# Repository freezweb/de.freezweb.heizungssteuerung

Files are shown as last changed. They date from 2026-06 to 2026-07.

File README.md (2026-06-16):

# de.freezweb.heizungssteuerung

Heizungssteuerung auf Revolution Pi Connect 4 mit Anbindung an Home Assistant (MQTT).

Komplette Spezifikation: siehe [LASTENHEFT.md](LASTENHEFT.md).

## Komponenten
- **Hauptsteuerung** Heizungsraum (RevPi #1, `10.1.25.10`)
- **Slave-Steuerung** Hauptkeller (RevPi #2, `10.1.25.11`, sp&auml;ter)
- **Visualisierung + History**: Home Assistant via MQTT-Discovery
- **Failsafe**: Witterungsgef&uuml;hrte Heizkurve bei MQTT-/HA-Ausfall

## Stack
- Python 3.11 (Asyncio)
- `revpimodio2` &mdash; RevPi-I/O
- `paho-mqtt` &mdash; HA-Kopplung
- `pymodbus` &mdash; W&auml;rmepumpen, Klima-Innenger&auml;te, Slave-CPU
- systemd (`Type=simple, Restart=on-failure`)

## Verzeichnisstruktur
```
src/heizung/        Hauptcode
config/             Live-Configs (gitignored, *.example committet)
pictory/            RevPi-PiCtory-Export
tests/              Pytest
deploy/             systemd-Unit + install/update Scripts
docs/               Hydraulik-, I/O- und MQTT-Doku
```

Wichtige Hardware-Planung:
- [docs/revpi-modulplanung.md](docs/revpi-modulplanung.md)
- [docs/io-belegung.md](docs/io-belegung.md)

## Quick start (Entwicklung)
```bash
python -m venv .venv
.venv\Scripts\activate
pip install -e .
cp config/settings.yaml.example config/settings.yaml
# Anpassen, dann:
python -m heizung
```

## Deployment auf RevPi
Siehe `deploy/install.sh`.

## Phasen-Plan
Siehe [LASTENHEFT.md Abschnitt 10](LASTENHEFT.md#10-phasen-plan-reihenfolge).

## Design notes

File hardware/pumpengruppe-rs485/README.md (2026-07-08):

# Pumpengruppe RS485 KiCad-Projekt

RevA preliminary, Stand 2026-06-25.

Dieses Verzeichnis enthaelt den KiCad-Startentwurf fuer die dezentrale
Pumpengruppen-Platine:

- `pumpengruppe-rs485.kicad_pro`: KiCad-Projekt
- `pumpengruppe-rs485.kicad_sch`: Schaltplan mit lokalen Symbolen
- `pumpengruppe-rs485.kicad_pcb`: PCB-Grundlayout 160 x 110 mm
- `lib/`: lokale Symbole/Footprints
- `export-fab.ps1`: Gerber/Drill/BOM-Export per `kicad-cli`
- `fab/`: Zielordner fuer Fertigungsdaten

Aktueller Stand:

- Schaltplan/PCB laden in KiCad 10.0.4.
- Schaltplan enthaelt jetzt alle im PCB platzierten Hauptbauteile inklusive
  `F1`, `U5`, USB-C/USB-UART und schaltbarem RS485-Abschluss. Die lokalen
  Symbole haben benannte Pins; die Netznamen sind als sichtbare Texte an den
  Funktionspins gesetzt.
- Gerber/Drill/BOM lassen sich per `export-fab.ps1` erzeugen.
- USB-C-Serviceanschluss mit USB-UART-Funktion ist eingeplant.
- UART-Topologie im Schaltplan ist getrennt:
  `U6` USB-UART liegt nur auf ESP-UART0 (`ESP_U0RX`/`ESP_U0TX`) fuer
  Firmware/Debug. `U4` MAX3485 liegt separat auf dem RS485-UART
  (`RS485_UART_RX` = ESP GPIO16, `RS485_UART_TX` = ESP GPIO17,
  `RS485_DE` = ESP GPIO4). Nach dieser Korrektur muss die PCB-Datei in KiCad
  aus dem Schaltplan aktualisiert und das Routing fuer diese Netze neu gezogen
  werden; alte `UART_RX`/`UART_TX`-Routen im PCB duerfen nicht als
  Fertigungsstand gelten.
- ESP32 ist als WROOM-32D mit PCB-Antenne vorgesehen; Antennenseite am
  Platinenrand platzieren und Keepout freihalten.
- Relais werden nicht direkt vom ESP geschaltet: pro Relais sind 100R
  Gatewiderstand, 100k Pulldown, AO3400A-kompatibler NMOS, SS14-Freilaufdiode
  und Status-LED vorgesehen.
- Mischer ist als Hardware-Interlock geplant: `K2` schaltet nur die
  Mischerfreigabe, `K3` ist ein SPDT-Umschaltrelais fuer die Richtung
  `NC=ZU` / `NO=AUF`. Damit koennen AUF und ZU elektrisch nicht gleichzeitig
  gespeist werden.
- Kontrollanzeigen: 230 V diskret auf der Netzseite mit `R40/R41/D40/D41`,
  5 V, 3V3 sowie RS485 TX/RX und die drei Relaisansteuerungen.
- Adressierbare RGB-Anzeige: `D60-D83` sind einheitliche SK6812MINI/3535-5-V-RGB-LEDs
  an `RGB_DATA`/ESP32 GPIO21. `D60-D63` bleiben allgemeine Status-LEDs,
  `D64-D83` bilden den senkrechten Ventilstand-Balken mit 5-%-Schritten;
  die 20er-Leiste ist im 4,8-mm-Raster gesetzt, damit Courtyards nicht kollidieren.
- RTD/ESP-Hinweis: Die beiden MAX31865 haben getrennte Chip-Select-Leitungen
  (`RTD_VL_CS` = GPIO5, `RTD_RL_CS` = GPIO22). Der ESP32-EN-Pin ist ueber
  `R33` als 10-kOhm-Pullup an `+3V3` angebunden.
- Netzteil ist auf ein guenstiges KiCad-Standardfootprint fuer
  `HLK-5M05`/`HLK-5Mxx` umgestellt.
- RS485 ist auf eine guenstige Standardtransceiver-Schaltung umgestellt:
  `U4` = MAX3485/SP3485-Klasse im SOIC-8 mit getrennten UART-Netzen zum ESP,
  `RS485_DE` vom ESP fuer DE/RE.
- Ueberspannungsschutz auf der Netzseite ist diskret vorgesehen:
  `RV1` als 275-VAC-MOV zwischen L und N.
- RJ45 Pin 1/2 fuehren `BUS_5V`, Pin 7/8 `COM`; `F2` schuetzt die 5V-Kopplung
  mit PTC, `R32` koppelt COM auf lokale 0V fuer RJ45-Power-Sharing.
- Es gibt zwei Bestueckungsvarianten fuer dieselbe Leiterplatte:
  - Vollausbau Pumpengruppe: `pumpengruppe-rs485-bom.csv` und
    `pumpengruppe-rs485-pick-place.csv`.
  - Temperatur-/RS485-Variante: `pumpengruppe-rs485-bom-tempinput.csv` und
    `pumpengruppe-rs485-pick-place-tempinput.csv`; dabei bleibt der linke
    230-V-/Relaisbereich unbestueckt und die Versorgung erfolgt ueber
    `BUS_5V`/RJ45.
- Die Breakaway-Variante ist im Board sichtbar umgesetzt: `MB1` setzt
  0,7-mm-NPTH-Mousebites in die oberen und unteren Materialstege des
  vorhandenen Isolationsschlitzes. Zusaetzlich bleibt die
  `Dwgs.User`-/Silkscreen-Markierung fuer die Bestueckungsvariante erhalten.
- Netzteil und Relais sind so platziert, dass die Bauteile den
  MAINS/SELV-Spalt ueberbruecken: Netz-/Kontaktpins links, SELV-/Spulenpins
  rechts.
- RS485-Abschluss ist schaltbar: `R3 = 120R` in Serie mit `JP1`. `JP1` ist
  ein 1x3-Header, damit der Jumper am Geraet bleiben kann:
  `1-2 = Abschluss aktiv`, `2-3 = Parkposition/Aus`.
- RJ45-Buchsen und USB-C-Serviceport sind an die Unterkante gesetzt und zeigen
  zur Kante, damit Stecker/Kabel nutzbar sind. RS485-Schraubklemmen bleiben an
  der rechten Anschlusskante. J3/J4 sind auf dem Silkscreen mit A/B/GND
  beschriftet; am unteren Rand steht das RJ45-Pinout
  `1/2=5V 3/6=NC 4=A 5=B 7/8=GND`.
- KiCad-Netclasses sind in `pumpengruppe-rs485.kicad_pro` gesetzt:
  `230V` routet L/N/geschaltete 230-V-Lastnetze und PE mit 1,5 mm und
  0,8 mm Clearance innerhalb der 230-V-Netze. Fuer die 5-A-Sicherung sollte die
  Bestellung mit mindestens 70 um / 2 oz Kupfer angefragt werden oder die
  tatsaechliche Last/Sicherung entsprechend reduziert werden. Die 8-mm-Trennung
  zwischen 230 V und SELV bleibt als physische Keepout-/Fraesnut-Regel beim
  Layout zwingend einzuhalten.
- Die Netclasses fuer weitere Power-Routings sind gesetzt:
  `SELV_POWER_0V8` fuer `+5V`, `BUS_5V`, `USB_VBUS`, `GND` und `RS485_GND`;
  `Doppelte Dicke` mit 0,4 mm fuer `+3V3`. Auf der RGB-/Temp-Input-Seite sind
  erste vorhandene 5-V-/GND-Segmente real auf 0,8 mm und 3V3-Segmente auf
  0,4 mm verbreitert. Einige Engstellen an USB/RJ45 bleiben bewusst 0,2 mm,
  weil breitere Leiterbahnen dort DRC-Kurzschluesse erzeugen wuerden. Fuer die
  finale Serienplatine sollten diese Netze weiter gezielt als breite
  Versorgungsstaemme bzw. Kupferflaechen nachgezogen werden.

Wichtig: RevA ist elektrisch geroutet und hat keine offenen Netze im KiCad-DRC.
Vor einer Netzspannungs-Freigabe bleiben trotzdem Relais-/Sicherungsrating,
PE-Fuehrung, Gehaeuseintegration, Beruehrschutz, EMV-Schutz und die
Herstellerfreigabe fuer 230-V-Abstaende zu pruefen. Wenn die RJ45-5V-Weitergabe
bestueckt/genutzt wird, ist die RS485-/SELV-Masse gemeinsam; das
Isolationskonzept muss dann als gemeinsamer SELV-Bus bewertet werden.

## Export

Nach Installation von KiCad:

```powershell
cd hardware\pumpengruppe-rs485
.\export-fab.ps1
```

Das Skript erzeugt Gerber, Excellon-Drill, beide BOM-Varianten, beide
Pick-and-Place/XY-Dateien und eine ZIP-Datei in `fab/`.

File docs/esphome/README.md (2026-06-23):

# ESPHome Wasserverbrauch Pumpe

`wasserverbrauch-pumpe.yaml` ist der aktuell bekannte Stand des ESP32 am
Flowmeter der Brunnenpumpe.

## Ziel fuer die Brunnenregelung

Die ESPHome-Konfig stellt den Momentandurchfluss als lokalen Modbus-TCP-Server
per WLAN bereit.

| Register | Typ | Inhalt | Skalierung |
|---|---|---|---|
| 0 | Input Register | Wasserdurchfluss | L/min * 100 |
| 1/2 | Input Register | Wasserverbrauch Gesamt | L * 1000 |

Beispiel: Registerwert `125` bedeutet `1.25 L/min`.

## Modbus TCP

- TCP-Port: `502`
- Unit-ID: `1`
- Function 3 und 4 werden beantwortet
- Register 0: Durchfluss `L/min * 100`
- Register 1/2: Gesamtverbrauch `L * 1000`

## Anbindung an die Hauptsteuerung

ESPHome bringt `async_tcp` als TCP-Grundlage mit, aber keinen fertigen
Modbus-TCP-Server fuer diesen Flowmeter-Fall. Deshalb startet die YAML in
`on_boot` einen kleinen AsyncTCP-Server direkt aus einem Lambda. Es wird keine
zweite Datei und keine External Component benoetigt.

Die Hauptsteuerung liest:

- Host: `wasserverbrauch-pumpe.local` bzw. die per mDNS aufgeloeste IP
- TCP-Port: `502`
- Unit-ID: `1`
- Function: `4` / Input Register
- Register: `0`
- Skalierung: `100`

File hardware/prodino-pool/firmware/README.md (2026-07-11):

# Prodino Pool Firmware

Firmware fuer den KMP Prodino MKR Zero Ethernet als Pool-I/O per Modbus TCP:

- Relay 1: Pool-Nachfuellventil
- Relay 2: Flockungsmittel-Peristaltikpumpe
- OptoIn1: Schwimmer, Kontakt geschlossen = Pool zu leer

Modbus TCP:

- Port: `502`
- Unit-ID: `1`
- Coils `0..3`: Relais 1..4, schreibbar per FC05/FC15, lesbar per FC01
- Discrete Inputs `0..3`: OptoIn 1..4, lesbar per FC02
- Holding/Input Register FC03/FC04:
  - `0`: Uptime Sekunden Low-Word
  - `1`: Uptime Sekunden High-Word
  - `2`: Relaismaske, Bit 0 = Relais 1
  - `3`: Eingangsmaske, Bit 0 = OptoIn 1
  - `4`: Firmware-Version

Sicherheit:

- Wenn 120 Sekunden kein Modbus-Schreibkommando kommt, werden alle Relais ausgeschaltet.
- DHCP wird zuerst versucht; als Fallback nutzt die Firmware `10.1.1.146`.

Flashen:

```powershell
cd hardware\prodino-pool\firmware
pio run -t upload
pio device monitor -b 115200
```

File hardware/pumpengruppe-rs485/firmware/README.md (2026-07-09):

# Pumpengruppe RS485 Firmware

Erste Test-Firmware fuer die ESP32-Pumpengruppen-Platine.

## Funktionen in Version 0.2.0

- WLAN als Client, bei fehlender Verbindung Fallback-AP.
- Weboberflaeche fuer Status, Werteuebersicht, WLAN, RS485 und Mischerparameter.
- Web-Update unter `/update`.
- ArduinoOTA im lokalen Netz.
- Modbus-RTU-Slave mit den Registeradressen aus `docs/pumpengruppe-rs485-platine.md`.
- Optionaler Modbus-TCP-Server mit demselben Registersatz. Der Transport kann
  WLAN oder spaeter ein kabelgebundener IP-Pfad sein.
- Optionaler MQTT-Client fuer Installationen ohne Modbus-Master.
- Simulierte Vor-/Ruecklauftemperaturen, solange keine MAX31865-Hardware angeschlossen ist.
- Relais-/Mischerzustand und Bus-Watchdog als lauffaehige Logik.

## Flashen

```powershell
cd hardware\pumpengruppe-rs485\firmware
pio run -t upload
pio device monitor
```

Wenn kein WLAN konfiguriert ist oder die Verbindung fehlschlaegt, startet der
ESP32 einen Access Point:

- SSID: `Pumpengruppe-XXXXXX`
- Passwort: keines, offenes Einrichtungs-WLAN
- Web: `http://192.168.4.1/`
- Captive Portal: DNS leitet im Einrichtungs-WLAN auf die Weboberflaeche um.

Default-Login fuer die Weboberflaeche:

- Benutzer: `admin`
- Passwort: `admin`

Im offenen Einrichtungs-WLAN ist kein Login noetig. Sobald der ESP im normalen
WLAN erreichbar ist, schuetzt HTTP Basic Auth die Weboberflaeche. Bitte nach
dem ersten Test aendern.

## Konfiguration zuruecksetzen

Der Taster `BOOT/CFG RESET` liegt auf `GPIO0` gegen GND.

- kurzer Druck waehrend Reset/Power-Up: normaler ESP32-Bootloader/Flash-Modus
- langer Druck im laufenden Betrieb fuer mindestens 10 Sekunden:
  gespeicherte WLAN-, Web-, Modbus- und MQTT-Konfiguration wird geloescht,
  alle Ausgaenge werden abgeschaltet und der ESP startet neu

Danach startet wieder das offene Einrichtungs-WLAN.

## Vorlaeufige Pinbelegung

| Signal | GPIO |
|---|---:|
| Pumpe Relais | 35 |
| Mischer Freigabe | 36 |
| Mischer Richtung | 37 |
| RS485 TX | 17 |
| RS485 RX | 16 |
| RS485 DE/RE | 4 |
| RGB/SK6812 | 21 |
| SPI MOSI | 11 |
| SPI MISO | 13 |
| SPI SCK | 12 |
| RTD Vorlauf CS | 10 |
| RTD Ruecklauf CS | 9 |
| BOOT/CFG RESET | 0 |
| USB D- | native USB / GPIO19 |
| USB D+ | native USB / GPIO20 |

Die Platinenrevision nutzt `ESP32-S3-WROOM-1-N4`; der USB-UART-Baustein
entfaellt, Firmware/Monitor laufen direkt ueber natives USB-CDC.

J5 ist als Erweiterungsheader vorgesehen: `+5V`, `+3V3`, mehrfach `GND` sowie
freie S3-GPIOs `1`, `2`, `3`, `5`, `6`, `7`, `8`, `14`, `15`, `18`, `38`,
`39`, `40`, `41`, `42`. Diese Pins sind nicht fuer Relais, RS485, SPI, RGB,
USB oder Boot reserviert.

## Modbus

RTU und TCP verwenden denselben Registersatz:

- Holding Register 0..8: Master -> Board
- Input Register 0..8: Board -> Master

Modbus TCP ist ab Werk aktiv auf Port `502`. Die Unit-ID ist die eingestellte
Slave-ID, `255` wird ebenfalls akzeptiert. Falls nur RS485 genutzt werden soll,
kann TCP in der Weboberflaeche deaktiviert werden.

## MQTT

MQTT ist ab Werk deaktiviert und kann in der Weboberflaeche unter `MQTT`
aktiviert werden. Wenn kein Basis-Topic eingetragen ist, wird
`pumpengruppe/<hostname>` verwendet.

Command-Topics:

| Topic | Payload |
|---|---|
| `<base>/cmd` oder `<base>/set` | JSON, z.B. `{"pump":true,"target":56}` |
| `<base>/target/set` | Zielposition in Prozent, z.B. `56` |
| `<base>/pump/set` | `0/1`, `on/off`, `true/false` |
| `<base>/mode/set` | `auto`, `hand`, `cal_close`, `cal_open` |
| `<base>/modbus_tcp/set` | `0/1`, `on/off`, `true/false`, schaltet Modbus TCP sofort am ESP |

Status-Topics:

| Topic | Inhalt |
|---|---|
| `<base>/availability` | `online` / `offline` |
| `<base>/state` | JSON mit Firmware, IP, Pumpe, Ziel, Position, Temperaturen, Fehlern |
| `<base>/position/state` | Mischerposition in Prozent |
| `<base>/target/state` | Zielposition in Prozent |
| `<base>/pump/state` | realer Pumpenausgang `0/1` |
| `<base>/pump_requested/state` | angeforderte Pumpe `0/1` |
| `<base>/vl_temp/state` / `<base>/rl_temp/state` | Vor-/Ruecklauf in Grad C |
| `<base>/fault/state` | Fehlercode |
| `<base>/moving/state` | Mischerfahrt aktiv `0/1` |
| `<base>/modbus_tcp/state` | Modbus TCP aktiv `0/1` |
| `<base>/heartbeat` | JSON mit `uptimeS`/`uptimeMs` als Lebenszeichen |

Die Statuswerte werden nach dem MQTT-Connect einmal vollstaendig gesendet und
danach nur noch bei geaenderter Payload erneut veroeffentlicht. Der Heartbeat
kommt weiterhin zyklisch im eingestellten Statusintervall, damit man sieht,
dass das Board noch arbeitet.

Einrichtungshilfe:

Beim MQTT-Verbinden veroeffentlicht das Board retained Hilfe- und Beispieltopics
unter `<base>/help/...` und `<base>/example/...`. Die echten Command-Topics
werden bewusst nicht retained vom Board beschrieben, damit ein alter retained
Befehl beim Reconnect nicht automatisch erneut ausgefuehrt wird.

Solange MQTT verbunden ist, gilt die Brokerverbindung als Watchdog-Lebenszeichen.
Wenn WLAN/Broker ausfaellt, greift der vorhandene Watchdog wie bei Modbus.

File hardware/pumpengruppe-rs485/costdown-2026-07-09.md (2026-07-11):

# Pumpengruppe RS485 Costdown 2026-07-09

Ziel: PCBWay soll die Platine nicht mit teuren Importteilen kalkulieren muessen. Wo funktional vertretbar, werden guenstige Standardteile aus chinesischem Lager bevorzugt. Vor erneutem Angebot werden Schaltplan, Footprints und BOM auf diese Teile umgestellt.

## Status 2026-07-10

Die PCBWay-Quote vom 2026-07-09 markiert als lange Lieferzeit (`7-10 Workdays`) nur F1, K2 und K3. Diese drei Positionen sind im KiCad-Projekt ersetzt:

| Ref | Vorher | Jetzt | Status |
|---|---|---|---|
| F1 | Littelfuse 03453LS1H | 2x Bel Fuse FC-203-22 Sicherungsclip | In Schaltplan, PCB und exportierter BOM geaendert |
| K1-K3 | Omron G5LE Varianten | Songle SRD-05VDC-SL-C fuer alle drei Relais | In Schaltplan, PCB und exportierter BOM geaendert |
| U4 | MAX3485EESA+ | MaxLinear SP3485EN-L/TR | Zusaetzlicher Costdown-Tausch ohne Layoutaenderung, in Schaltplan, PCB und exportierter BOM geaendert |

Export/Pruefung nach Umbau: `fab/pumpengruppe-rs485-revA-preliminary-gerber.zip`, `fab/pumpengruppe-rs485-bom.csv`, `fab/pumpengruppe-rs485-aisler-mpn-bom.csv` und `fab/preflight-drc-after-leadtime.rpt` wurden neu erzeugt. DRC: 0 unverbundene Pads, 0 Footprint-Fehler; verbleibend sind bekannte Silkscreen-Warnungen.

## Festgelegte Klemmen

Alle Klemmen sollen Schraube oben und Drahteinfuehrung seitlich haben.

| Ref | Alt | Neu | Preisstand | Grund |
|---|---|---|---|---|
| X1, X2 | Degson DG129-7.62-03P-14-00AH | [Cixi Kefa KF128-5.08-3P-AA / LCSC C474953](https://www.lcsc.com/product-detail/C474953.html) | ab ca. 0.1609 USD | 5.08 mm, 3-polig, guenstig, seitliche Einfuehrung, oben geschraubt |
| X3 | Degson DG129-7.62-04P-14-00AH | [DORABO DB128L-5.08-4P-GN-S / LCSC C2827883](https://www.lcsc.com/product-detail/C2827883.html) | 5+ ca. 0.3391 USD, 50+ ca. 0.2698 USD | 5.08 mm, 4-polig, guenstig, seitliche Einfuehrung, oben geschraubt |
| J3, J4 | Degson DG350-3.5-03P-14-00AH | [Cixi Kefa KF128L-3.5-3P / LCSC C474931](https://www.lcsc.com/product-detail/C474931.html) | ab ca. 0.1102 USD | RS485-Klemme, 3.5 mm, guenstig |
| X4, X5 | Degson DG350-3.5-02P-14-00AH | [Cixi Kefa KF128L-3.5-2P / LCSC C474930](https://www.lcsc.com/product-detail/C474930.html) | ab ca. 0.0728 USD | RTD-Klemme, 3.5 mm, guenstig |

Hinweis: X1/X2/X3 sind 230-V-nahe. Nach dem Umrouten muessen Freiraeume, Netzklassen und Bohr-/Pad-Abstaende erneut per DRC geprueft werden.

## Weitere empfohlene Costdown-Teile

| Ref | Alt laut PCBWay | Vorschlag | Preisstand | Einschaetzung |
|---|---|---|---|---|
| F1 | Littelfuse 03453LS1H, ca. 8.50 USD/Stk | [2x Bel Fuse FC-203-22 / LCSC C3205463](https://www.lcsc.com/product-detail/C3205463.html) | ab ca. 0.0112 USD je Clip, 2 Clips pro Sicherung | Sehr grosser Hebel; nutzt den vorhandenen offiziellen KiCad-Clip-Footprint, PCBWay muss zwei Clips pro F1 bestuecken |
| K1/K2/K3 | Omron G5LE, teuer/Import | [Songle SRD-05VDC-SL-C / LCSC C35449](https://www.lcsc.com/product-detail/C35449.html) fuer alle drei Relais | ab ca. 0.2324 USD | Einheitliches SPDT-Relais spart BOM-Varianten. K1/K2 nutzen nur COM/NO, K3 nutzt COM/NO/NC fuer AUF/ZU. Fuer moderne Hocheffizienzpumpen mit wenigen Watt ausreichend, Schaltleistung trotzdem mit realem Pumpendatenblatt verifizieren |
| PSU1 | Mean Well IRM-05-5 | [HI-LINK HLK-5M05 / LCSC C209907](https://www.lcsc.com/product-detail/C209907.html) oder guenstiger 5-W-AC/DC-Baustein | ab ca. 1.6091 USD | 5 W beibehalten, 3 W wegen Relais/RGB eher nicht |
| U4 | MAX3485EESA+ | [MaxLinear SP3485EN-L/TR / LCSC C8963](https://www.lcsc.com/product-detail/C8963.html) | ab ca. 0.1662 USD | Pin-kompatible SOIC-8-Klasse, deutlich guenstiger |
| U6 | CP2102N QFN | Entfaellt bei Wechsel auf ESP32-C3/S3 mit nativem USB; sonst [WCH CH340C SOP-16 / LCSC C84681](https://www.lcsc.com/product-detail/C84681.html) | CH340C ab ca. 0.3578 USD | Native USB spart U6, DTR/RTS-Transistoren und einige Passivteile. CH340C nur verwenden, wenn wir beim klassischen ESP32 bleiben |
| U1 | ESP32-WROOM-32D-N4 | Bevorzugt: [ESP32-S3-WROOM-1-N4 / LCSC C2913197](https://www.lcsc.com/product-detail/C2913197.html); Sparvariante: [ESP32-C3-WROOM-02-N4 / LCSC C2934560](https://www.lcsc.com/product-detail/C2934560.html); konservativ: [ESP32-WROOM-32E-N4 / LCSC C701341](https://www.lcsc.com/product-detail/C701341.html) | S3 100+ ca. 3.5177 USD; C3 100+ ca. 2.4185 USD; 32E 100+ ca. 2.9273 USD | S3 kostet gegenueber C3 ca. 1.10 USD mehr, spart wie C3 den USB-UART und gibt deutlich mehr GPIO-/Firmware-Reserve. C3 bleibt nur die maximale Sparvariante |
| D10-D31 | Wuerth 0603 LEDs | [KENTO KT-0603G / LCSC C12624](https://www.lcsc.com/product-detail/C12624.html) | 50+ ca. 0.0122 USD, 500+ ca. 0.0097 USD | Gleiche Funktion, deutlich billiger |
| U2/U3 | MAX31865AAP+ | Behalten oder redesign auf ADS1115 + Praezisionsnetzwerk | offen | MAX31865 ist teuer, aber sauber. ADS1115 spart Geld, erfordert Firmware-/Analog-Redesign |

## USB-Flash / Bootloader

Aktueller Pruefstand aus KiCad-Netzliste:

- USB-C D+/D- sind mit dem USB-UART verbunden.
- USB-UART TXD/RXD sind gekreuzt mit ESP UART0 GPIO3/GPIO1 verbunden.
- RS485 liegt separat auf GPIO16/GPIO17 und kollidiert damit nicht mit dem USB-Flash-Port.
- Nicht fertig: `DTR` und `RTS` vom USB-UART sind unverbunden, `IO0` vom ESP ist ebenfalls unverbunden. Damit kann die Platine aktuell nicht sicher per "nur USB einstecken und Upload druecken" in Serie geflasht werden.

Pflichtumbau fuer Serienflash:

1. `GPIO0` mit 10 kOhm Pull-up nach 3V3 versehen.
2. `EN` mit 10 kOhm Pull-up nach 3V3 beibehalten und 100 nF nach GND ergaenzen.
3. `DTR` und `RTS` ueber die uebliche zweitransistorige Auto-Program-Schaltung auf `GPIO0` und `EN` fuehren, wie bei ESP32-Devkits. Damit kann esptool/PlatformIO den Chip automatisch resetten und in den UART-Bootloader bringen.
4. Taster `BOOT/CFG RESET` von `GPIO0` nach GND vorsehen. Kurz beim Reset = Bootloader, 10 s im laufenden Betrieb = Firmware loescht Konfiguration und startet wieder ins offene Einrichtungs-WLAN.
5. Zusaetzlich kleine Testpads fuer `EN`, `GPIO0`, `U0TXD`, `U0RXD`, `3V3`, `GND` vorsehen. Fuer Fehlersuche Gold wert.

Wenn U6 auf CH340C umgestellt wird, muss dieselbe Funktion erhalten bleiben: `TXD`, `RXD`, `DTR#`, `RTS#`, `VCC`, `GND`, USB D+/D-. Nur ein reiner TX/RX-Anschluss reicht nicht.

## ESP-Modul-Entscheidung

Kurzfassung: Wenn wir sowieso wegen Relais/Klemmen/USB routen muessen, ist `ESP32-S3-WROOM-1-N4` die sinnvollste Revision. Der C3 waere billiger, hat aber fuer diese Platine praktisch keine GPIO-Reserve. Der S3 kostet bei 100 Stueck grob 1.10 USD mehr als der C3, spart aber ebenfalls den USB-UART und laesst firmwareseitig deutlich mehr Luft.

Bewertung:

- `ESP32-WROOM-32D` ist bei Espressif als NRND gefuehrt. Fuer neue Bestellungen daher nicht mehr die beste Wahl.
- `ESP32-WROOM-32E-N4` ist der kleinste Umbau: gleicher Modul-Footprint/Pinout-Bereich, ausreichend GPIO, Firmware bleibt praktisch gleich, Preis bei LCSC 100+ ca. 2.9273 USD. Nachteil: externer USB-UART bleibt noetig.
- `ESP32-C3-WROOM-02-N4` ist billiger und moderner, Preis bei LCSC 100+ ca. 2.4185 USD, und hat USB Serial/JTAG direkt im Chip. Damit entfallen U6, DTR/RTS-Transistoren und ein Teil der Passivteile.
- C3-Nachteil: 15 GPIOs sind knapp. Fuer diese Platine geht es voraussichtlich exakt auf: 3 Relais, RS485 TX/RX/DE, SPI MOSI/MISO/SCK, 2x RTD-CS, RGB-Daten, BOOT/CFG-Reset, USB D+/D-. Es bleibt praktisch keine Reserve.
- `ESP32-S3-WROOM-1-N4` hat ebenfalls natives USB Serial/JTAG, mehr Rechenleistung, mehr RAM und deutlich mehr nutzbare GPIOs. Preis bei LCSC 100+ ca. 3.5177 USD, also ca. 1.10 USD mehr als C3. Bei 10 Platinen sind das nur rund 11 bis 12 USD Mehrkosten, dafuer bleibt die Firmware/Hardware deutlich entspannter.

Empfehlung fuer Costdown-Revision A: auf `ESP32-S3-WROOM-1-N4` umplanen. `ESP32-C3-WROOM-02-N4` nur als harte Sparvariante, falls jeder Dollar zaehlt. `ESP32-WROOM-32E-N4 + CH340C` nur als Fallback, falls natives USB oder S3-Layout unerwartet Probleme macht.

Vor S3-Freigabe zwingend pruefen:

1. Exaktes Pinmapping fuer alle Signale inkl. strapping pins und USB D+/D-.
2. PlatformIO/Arduino Build mit passendem `esp32-s3-devkitc-1` Boardprofil.
3. USB-Flash und Monitor ueber natives USB auf Windows testen.
4. BOOT/CFG-Reset-Taster auf den S3-Boot-Strap-Pin legen und in Firmware entsprechend anpassen.

## Naechster Umbaupfad

1. Klemmen, RS485-IC, Status-LEDs und Sicherungshalter umstellen.
2. K1/K2/K3 auf einheitliches Songle SRD-05VDC-SL-C umstellen; K1/K2 als NO-Kontakt, K3 als Umschalter.
3. USB-UART-Auto-Boot-Schaltung ergaenzen, sonst ist Serienflash nicht akzeptabel.
4. Netzteil auf 5-W-Standardmodul umplanen und thermisch/lastseitig pruefen.
5. Erst danach RTD-Frontend anfassen, weil das deutlich mehr Schaltplan und Firmware betrifft.

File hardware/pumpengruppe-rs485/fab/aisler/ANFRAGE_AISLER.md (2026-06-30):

# AISLER Anfrage - Pumpengruppe RS485 RevA

Projekt: `pumpengruppe-rs485`

Ziel der Anfrage:
- Angebot fuer Leiterplatte und Bestueckung der aktuellen RevA einholen.
- Zunaechst Prototyp-/Kleinserie, Stueckzahl bitte im AISLER-Portal variieren.
- Bitte als Machbarkeits-/Kostenanfrage behandeln, nicht ohne Ruecksprache in Serienfertigung geben.

Empfohlener Upload:
1. `pumpengruppe-rs485-aisler-native-kicad.zip`
   - KiCad-10-Projekt mit lokalen Symbolen und Footprints.
   - AISLER unterstuetzt KiCad nativ; das ist fuer BOM/PnP-Erkennung meist am besten.
2. Falls noetig zusaetzlich `pumpengruppe-rs485-aisler-gerber-drill.zip`
   - Klassische Gerber-/Excellon-Fertigungsdaten.
3. Fuer Assembly die CSV-Dateien unter `assembly/` nutzen.
   - Wichtig: `pumpengruppe-rs485-aisler-mpn-bom.csv` ist die bevorzugte AISLER-BOM mit Hersteller- und MPN-Feldern.
   - `pumpengruppe-rs485-component-review.csv` enthaelt die wenigen Positionen, bei denen Footprint/Spannungsfestigkeit vor einer echten Bestellung noch bestaetigt werden muessen.

Varianten:
- `pumpengruppe-rs485-aisler-mpn-bom.csv` + `pumpengruppe-rs485-pick-place.csv`
  = volle Pumpengruppen-Variante mit 230V-/Relais-/Pumpen-/Mischerbereich.
- `pumpengruppe-rs485-bom-tempinput.csv` + `pumpengruppe-rs485-pick-place-tempinput.csv`
  = Bestueckungsvariante fuer reine Temperatur-/RS485-Eingangskarte, linker 230V-Teil nicht bestueckt.
- PSU1 ist auf Mean Well IRM-05-5 umgeplant und soll in der vollen Pumpengruppen-Variante von AISLER bestueckt werden. Bitte Footprint, Verfuegbarkeit und 230V-Abstaende vor Freigabe bestaetigen.

Wichtige Rueckfragen an AISLER:
- 230V-Bereich, Relais, Netzteil und Schraubklemmen bitte gegen VDE-/Kriechstreckenanforderungen pruefen.
- Bitte klaeren, welche THT-Teile automatisch/manuell bestueckbar sind.
- Bitte Ersatztypen fuer Relais, Klemmen, RJ45, USB-C und PSU1 / IRM-05-5 vor Freigabe bestaetigen.
- D50/D51/D52 sind optionale RS485-TVS-Reserveplaetze und in der Basisbestueckung DNP; bitte nicht bestuecken.
- X3 ist ein 4-poliger 7,62-mm-Netz-/Mischeranschluss. Bitte nicht durch eine 5,08-mm-Klemme ersetzen; MPN/Footprint muessen vor Fertigung mechanisch zusammenpassen.
- Relais K1/K2/K3 und RTD-ICs U2/U3 sind in der Review-Liste bewusst als Footprint-Pruefung markiert.
- R40/R41 sind 230V-LED-Vorwiderstaende; Spannungsfestigkeit, Verlustleistung und Kriechstrecke vor Freigabe pruefen.
- Bitte Positionen/Rotationen im Assembly-Viewer pruefen, insbesondere RJ45, USB-C, Relais, ESP32 und SK6812MINI.
- Die DRC-/ERC-Reports liegen bei. Aktueller Stand enthaelt noch Warnungen/Verstoesse und Schaltplan-/PCB-Paritaetsmeldungen; vor einer echten Produktionsfreigabe muessen diese gemeinsam bewertet bzw. bereinigt werden.

Board-Hinweise:
- 2-Lagen PCB.
- Mains/SELV-Trennung und Bruchkante/Bestueckungsvariante sind Bestandteil des aktuellen Layoutstands.
- RJ45 fuehrt RS485 sowie BUS_5V/BUS_COM fuer Daisy-Chain-Versorgung.
- RS485-Abschluss ueber 1x3-Jumper: 1-2 = Abschluss aktiv, 2-3 = Parkposition.

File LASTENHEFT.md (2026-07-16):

# LASTENHEFT - Heizungssteuerung Freezweb (de.freezweb.heizungssteuerung)

Stand: 2026-06-16

Komplette Spezifikation des Projekts. Anderungen am Funktionsumfang erfordern
Update dieses Dokuments.

## 0. Zielsetzung (TL;DR)
Komplette Ablosung der bisherigen Heizungssteuerung durch eigene Python-Losung
auf 2x Revolution Pi Connect 4 (Hauptsteuerung Heizungsraum + Slave Hauptkeller).
Visualisierung und Verlaufsdaten komplett in Home Assistant via MQTT-Discovery.
Autarker Failsafe-Betrieb mit witterungsgefuhrter Heizkurve bei MQTT-/HA-Ausfall.
Jeder Ausgang Hand/Auto schaltbar mit pro Kanal konfigurierbarem Hand-Timeout.

Vorbereitet fur den Umbau auf 2x 16 kW Monoblock-Warmepumpe + separate
Brauchwasser-WP + Brunnenkuhlung + Pool ganzjahrig 35 Grad + Klima-OG +
Nebengebaude + Hoftor.

## 1. Raumliche Aufteilung & Komponenten

| Standort | Inhalt | Anbindung |
|---|---|---|
| Heizungsraum (separat) | Hauptsteuerung RevPi #1, Olbrenner (uebergangsweise), Warmwasserspeicher; spater 2x Monoblock-WP, Brauchwasser-WP, Pool-Hydraulik, Brunnenkuhlung-WT, Nebengebaude-Strang | direkte I/O |
| Hauptkeller (~12 m entfernt) | Slave-RevPi #2 (spater), 2x 3-Wege-Mischer + Umwalzpumpen, 3 Strange: FBH-EG, Klimakreis-OG, Heizkorper-Backup OG; optional Gewaechshaus-Lufterhitzer als zusaetzlicher Niedertemperaturkreis | LAN/VLAN 25, Modbus-TCP |
| EG | Heizkreisverteiler FBH + Shelly-Funkventile (von HA gesteuert) | nur HA |
| OG | Aktuell 6 Heizkorper mit Shelly-TRV -> spater 5 Klima-Innengerate (Kind, Buro, Schlaf, Bad, Flur) + Heizkorper-Backup | Modbus RTU |
| Hoftor | 2 Antriebsausgange (ganz/halb) + 2 Endschalter + 1 Lichtschranke | Haupt-CPU |

## 2. Wohnflachen & Heizlast

### 2.1 Raume Hauptgebaude

**Erdgeschoss - Gesamt 122,31 m^2, beheizt ~105,5 m^2**

| Raum | Masse | Flache | Beheizt? |
|---|---|---|---|
| Kueche | 5,20 x 3,55 | 18,46 | ja |
| Wohnen | 11,50 x 5,00 | 57,50 | ja |
| Bad | 3,30 x 2,75 | 9,08 | ja |
| Flur | 8,00 x 1,60 | 12,80 | ja |
| HWR | 3,35 x 2,15 | 7,20 | nein (kalt) |
| Wintergarten | 5,10 x 3,75 | 19,13 | nein (komplett unbeheizt) |
| Treppenflur | 3,85 x 2,00 | 7,70 | ja |

**Obergeschoss - Gesamt 111,07 m^2, beheizt ~99,2 m^2**

| Raum | Masse | Flache | Beheizt? | Klima-IG |
|---|---|---|---|---|
| Flur 1 | 2,85 x 2,70 | 7,70 | ja | - |
| Flur 2 | 5,85 x 2,75 | 16,09 | ja | ja (Flur-IG) |
| Flur 3 | 3,45 x 2,25 | 7,76 | ja | - |
| Saunaraum (Lager) | 6,90 x 3,55 | 24,50 | nein (Frostschutz) | - |
| Kind | 5,00 x 3,55 | 17,75 | ja | ja |
| Buero | 6,95 x 3,55 | 24,67 | ja | ja |
| Schlafen | 3,55 x 3,55 | 12,60 | ja | ja |
| Bad mit Whirlpool | 3,55 x 3,55 | 12,60 | ja | ja |

### 2.2 Weitere beheizte Flachen
- **Nebengebaude**: ~140 m^2 (2x Buero + 1x Konferenz/Aufenthalt/Kueche/Multifunktion)
- **Pool**: < 30 m^3 outdoor mit Rollabdeckung, **ganzjahrig 35 Grad**

### 2.3 Heizlast-Uberschlag
Annahmen: Massivziegel mit beidseitiger Daemmung 10-14 cm, 2-Scheiben-Iso-Verglasung,
oberste Geschossdecke gedaemmt, Keller ungedaemmt aber Heizungsverteilung
durchlaeuft (kein Frost), Kernsanierung 2000-2003 -> Heizlastniveau ca. 55-70 W/m^2.

| Bereich | Flache | Spez. Heizlast | Heizlast |
|---|---|---|---|
| Hauptgebaude (EG+OG) | ~205 m^2 | 65 W/m^2 | ~13 kW |
| Nebengebaude | 140 m^2 | 70 W/m^2 (Burobetrieb tagsueber) | ~10 kW |
| Pool 35 Grad outdoor, abgedeckt, -10 Grad Aussentemp | 25 m^2 Becken | 250 W/m^2 | ~6-8 kW dauerhaft |
| **Spitzenlast (gleichzeitig)** | | | **~28-30 kW** |

### 2.3.1 Raumweise Heizlast fuer HA-Leistungsanforderung

Da das Gebaeude innen und aussen um 2000 gedaemmt wurde und ueberall
doppelt verglaste Kunststofffenster verbaut sind, wird fuer die
laufende Regelung vorerst der Lastenheft-Ueberschlag von **65 W/m^2**
als einheitlicher spezifischer Raumwert verwendet. Home Assistant
gewichtet diese Raum-Heizlast mit der aktuellen Ventilstellung.

**EG / FBH-Kreis**

| Raum / Ventilgruppe | Flaeche | Heizlast bei 65 W/m^2 | HA-Stellwert |
|---|---:|---:|---|
| Kueche | 18,46 m^2 | 1,20 kW | `number.heizung_kuche_ventilstellung` |
| Wohnen 1 | 19,17 m^2 anteilig | 1,25 kW | `number.wohnzimmer_1_ventilstellung` |
| Wohnen 2 | 19,17 m^2 anteilig | 1,25 kW | `number.wohnzimmer_2_ventilstellung` |
| Wohnen 3 | 19,17 m^2 anteilig | 1,25 kW | `number.wohnzimmer_3_ventilstellung` |
| Bad EG | 9,08 m^2 | 0,59 kW | `number.heizung_eg_bad_ventilstellung` |
| Flur + Treppenflur | 20,50 m^2 | 1,33 kW | `number.heizung_flur_eg_ventilstellung` |
| **Summe EG** | **105,54 m^2** | **6,86 kW** | |

**OG / Heizkoerper-Backup**

| Raum / Ventilgruppe | Flaeche | Heizlast bei 65 W/m^2 | HA-Stellwert |
|---|---:|---:|---|
| Flur 1-3 | 31,55 m^2 | 2,05 kW | `sensor.shellyblutrv_f844772c4513_valve_position` |
| Kind | 17,75 m^2 | 1,15 kW | `sensor.shellyblutrv_f8447705cec4_valve_position_2` |
| Buero | 24,67 m^2 | 1,60 kW | `sensor.shellyblutrv_f844772090fd_valve_position` |
| Schlafen | 12,60 m^2 | 0,82 kW | `sensor.shellyblutrv_f844772ca365_valve_position` |
| Bad OG | 12,60 m^2 | 0,82 kW | `sensor.shellyblutrv_f844772c36fd_valve_position` |
| Saunaraum/Lager | 24,50 m^2 | Frostschutz, nicht in Heizanforderung | `sensor.shellyblutrv_f8447705cec4_valve_position` |
| **Summe OG ohne Sauna** | **99,17 m^2** | **6,44 kW** | |

Wenn einzelne Ventil-Entitaeten in HA nicht verfuegbar sind, darf die
Automation fuer diesen Raum temporaer auf den jeweiligen Gesamt-Prozentwert
`sensor.heizanforderung_eg_prozent` bzw. `sensor.heizanforderung_og_prozent`
zurueckfallen.

### 2.4 WP-Dimensionierungs-Empfehlung
- 2x 11 kW war urspruenglich zu knapp gerechnet.
- **Empfehlung: 2x 16 kW Monoblock** (gesamt 32 kW, Modulationsbereich typ. 5-16 kW/Stueck)
  - Damit immer mind. eine WP im Optimalbereich (5-8 kW) fuer Teillast
  - Bei Volllast beide parallel
  - Bei Abtauen einer WP uebernimmt die andere
- **Pool-Waerme aus PV-Ueberschuss** (30 kWp + 100 kWh Speicher) -> realistisch
- **Brauchwasser-WP** bleibt separat (200 L, eigener Steuerkreis)

### 2.5 WP-Modell-Favorit Monoblock

**Favorit Stand 2026-06-23: Sunex NEXUS M18 EVI 18 kW Monoblock-Waermepumpe (R32)**

- Link: https://www.thermona-shop.de/sunex-nexus-m18-evi-18-kw-monoblock-waermepumpe-fuer-groessere-gebaeude-r32-47395
- Preis bei Pruefung: 2.262,99 EUR inkl. MwSt., zzgl. Versand
- Auslegung: 2 Stueck = 36 kW nominal; alternativ 3 kleinere Geraete nur bei deutlich besserem Preis/Modbus-Konzept.
- Passt zur Anlage, weil das Haus bereits auf Niedertemperatur bis ca. 55 Grad ausgelegt ist.
- Wichtige Daten laut Shop: 18 kW, max. VL 55 Grad, SCOP W35 4,58, SCOP W55 3,47, 400 V / 3~, R32, Betrieb -25 bis +45 Grad, empfohlener Heizwasserdurchfluss 3,1 m3/h.
- Achtung: Umwaelzpumpe ist laut Shop nicht integriert; Hydraulikpumpe, Sicherheitsgruppe, Magnetfilter und Frostschutzkonzept separat planen.
- Vor Bestellung zwingend klaeren: Modbus/Steuerungsdoku, externe Freigabe ueber Linkage Switch, Sollwertvorgabe, Fehler-/Statusregister, Gewaehrleistungsbedingungen bei Eigenintegration.

Weitere marktuebliche Kandidaten als Vergleich:
Heiko Thermal Plus 16 kW, Midea V8 16 kW, HeyHeat, Solar2Heat.

Pflichtkriterien:
- Monoblock (kein Innengeraet)
- Modbus RTU mindestens: Freigabe, VL-Soll, Heiz/Kuehl-Umschaltung, Status, Fehler
- Modulierend (Inverter)
- COP > 4 bei A7/W35
- VL bis 55 Grad
- 230 V oder 400 V Anschluss klaeren

## 3. Bestandshardware & Anpassung

### 3.1 Vorhanden (Heizungsraum, Stand 2026-06-16)
- 4x **RevPi Connect 4 WLAN 32/4GB** (eine CPU fuer Hauptsteuerung aktiv, weitere als Slave/Reserve; Hostname Hauptsteuerung `RevPi107273`)
- 3x **DIO V1.5** - je 14 DI + 14 DO (Eingaenge und Ausgaenge separat vorhanden, nicht 14 universelle Kanaele)
- 17x **DI V1.5** - je 16 DI = 272 DI Reservebestand
- 11x **AIO V1.4** - je 4 AI (V/I) + 2 RTD (Pt100/Pt1000) + 2 AO (V/I)

Wichtige Korrektur: DIO-Kanaele sind nicht "entweder DI oder DO". Ein DIO stellt
parallel 14 Eingange und 14 Ausgaenge bereit. AIO stellt direkte PT1000-Fuehler
nur an den 2 RTD-Kanaelen pro Modul bereit; die 4 AI sind Spannungs-/Stromeingaenge.

### 3.2 Geplante Modulkonfiguration (Endausbau)

**Hauptsteuerung Heizungsraum** (von links nach rechts):
> **DIO, DIO, AIO, AIO, AIO, CPU, AIO, AIO, AIO, AIO, AIO**

-> 2x DIO = 28 DI + 28 DO (21 DO geplant, 7 DO Reserve; 16 DI geplant, 12 DI Reserve)
-> 8x AIO = 32 AI (V/I) + 16 RTD + 16 AO
-> RevPi Connect 4 Limit eingehalten: 5 Module links + 5 Module rechts

**Slave-Steuerung Hauptkeller** (neu aufzubauen, spater):
> **DIO, CPU, AIO, AIO, AIO**

-> 1x DIO = 14 DI + 14 DO
-> 3x AIO = 12 AI (V/I) + 6 RTD + 6 AO
-> Damit sind alle 3 vorhandenen DIO und alle 11 vorhandenen AIO sinnvoll verteilt.
-> Die 17 DI-Module bleiben Reserve oder fuer spaetere dezentrale reine Eingangsstationen.

### 3.3 Zusatzhardware (zu beschaffen)

| Komponente | Zweck | Stueck | grob |
|---|---|---|---|
| Waveshare RS485-to-ETH | Modbus-Gateway WP-Bus | 1 | 50 EUR |
| Waveshare RS485-to-ETH | Modbus-Gateway Klima-OG-Bus | 1 | 50 EUR |
| Waveshare RS485-to-ETH | Modbus-Gateway BW-WP/Pool-/Filterperipherie | 1 | 50 EUR |
| Dezentrale RS485-Pumpengruppen-Platine | je Mischerkreis: 3WV Auf/Zu, Pumpe, VL/RL-RTD, ESP32 OTA | 4+ inkl. optional Gewaechshaus | Eigenentwicklung |
| Koppelrelais 24V -> 230V/16A | Pumpen, WP-Freigaben, Brunnen, Tor | ~20 | je 8-12 EUR |
| Hutschienen-Netzteil 24V/5A | I/O-Versorgung Slave-Schrank | 1 | 40 EUR |
| PT1000 Anlegefuehler | neue Sensoren erganzend | ~8 inkl. optional Gewaechshaus | je 15 EUR |
| Schaltschrank Slave | Hauptkeller | 1 | 200 EUR |
| Endschalter Hoftor (mechanisch, NO) | Tor zu-Position | 2 | 30 EUR |
| Lichtschranke Tor (Reflex, 24V) | Sicherheit Tor | 1 | 80 EUR |
| 3WV-Stellantriebe spater optional 0-10V | wenn 230V-Antriebe ersetzt werden | 5 (sukzessive) | je 100-150 EUR |

### 3.4 Netzwerk (festgelegt)
- VLAN: **25 / heizung_25 / 10.1.25.0/24** (pfSense + UniFi)
- **RevPi #1 (Heizungsraum)**: 10.1.25.10/24 statisch
- **RevPi #2 (Hauptkeller)**: 10.1.25.11/24 statisch (spaeter)
- Gateway: 10.1.25.1 (pfSense)
- MQTT-Broker: mqtt.esrv.center (User vbnet/vbnet)
- HA: 10.1.20.2 (eigenes VLAN, ueber pfSense erreichbar)
- SSH-Key vom Daniel-Laptop: `~/.ssh/id_ed25519_heizung` (eingerichtet 2026-06-16)

## 4. I/O-Belegungsplan

### 4.1 Haupt-RevPi Digital

Physische Klemmenlogik fuer die Hauptsteuerung:

- Karte 1 von links = DIO Adresse 27 / PiCtory `DIO2`: `DO1.1-DO1.14`, `DI1.1-DI1.14` = Software `DO15-DO28`, `DI15-DI28`
- Karte 2 von links = DIO Adresse 28 / PiCtory `DIO1`: `DO2.1-DO2.14`, `DI2.1-DI2.14` = Software `DO01-DO14`, `DI01-DI14`

**Digitale Ausgaenge (DO):**

| # | Physisch | Beschreibung | Phase |
|---|---|---|---|
| DO01 | DO2.1 | Olbrenner Freigabe (uebergangsweise) | A -> entfaellt B |
| DO02 | DO2.2 | Ladepumpe Brauchwasserspeicher (uebergangsweise) | A -> entfaellt B |
| DO03 | DO2.3 | WP1 Freigabe (potentialfrei) | B |
| DO04 | DO2.4 | WP2 Freigabe (potentialfrei) | B |
| DO05 | DO2.5 | Brauchwasser-WP Freigabe | B |
| DO06 | DO2.6 | Brunnenpumpe Magnetventil | C |
| DO07 | DO2.7 | Pool-Filterpumpe Freigabe | E |
| DO08 | DO2.8 | WP1 in Sammel-/Gesamtwaermekreis AUF | B |
| DO09 | DO2.9 | WP1 in Sammel-/Gesamtwaermekreis ZU | B |
| DO10 | DO2.10 | WP2 in Sammel-/Gesamtwaermekreis AUF | B |
| DO11 | DO2.11 | WP2 in Sammel-/Gesamtwaermekreis ZU | B |
| DO12 | DO2.12 | 3WV Pool-Heizkreis AUF | E |
| DO13 | DO2.13 | 3WV Pool-Heizkreis ZU | E |
| DO14 | DO2.14 | 3WV Nebengebaude AUF | B |
| DO15 | DO1.1 | 3WV Nebengebaude ZU | B |
| DO16 | DO1.2 | Reserve (HK-Backup-Mischer sitzt am Keller-Slave) | - |
| DO17 | DO1.3 | Reserve (HK-Backup-Mischer sitzt am Keller-Slave) | - |
| DO18 | DO1.4 | Pumpe Nebengebaude | B |
| DO19 | DO1.5 | Pumpe Pool-Heizkreis | E |
| DO20 | DO1.6 | Tor "ganz" Impuls (1000 ms via Koppelrelais) | A |
| DO21 | DO1.7 | Tor "halb" Impuls (1000 ms via Koppelrelais) | A |
| DO22 | DO1.8 | Reserve | - |
| DO23 | DO1.9 | Reserve | - |
| DO24 | DO1.10 | Reserve | - |
| DO25 | DO1.11 | Reserve | - |
| DO26 | DO1.12 | Reserve | - |
| DO27 | DO1.13 | Reserve | - |
| DO28 | DO1.14 | Reserve | - |

Klima-OG Kuehlmodus: Wenn die Klima-OG-Senke eine niedrigere Temperatur
fordert, aber der Heizungsmischer bereits geschlossen bleiben muss, kann die
Steuerung in den Brunnen-/Waermetauscherbetrieb wechseln. Dann wird DO06
`Brunnenpumpe Magnetventil` zusammen mit K-DO02 `Pumpe Klimakreis-OG`,
K-DO04 `FU Brunnenpumpe Freigabe` und K-AO01 `FU-Sollwert` aktiviert; K-AO03
`Mischer Klima-OG` wird auf `0 %` gesetzt. Die Funktion bleibt per Default
deaktiviert (`klima_og.kuehlung_enabled: false`), bis Magnetventil bzw.
spaeter ein regelbares Ventil hydraulisch sicher eingebaut sind.

**Digitale Eingange (DI):**

| # | Physisch | Beschreibung | Phase |
|---|---|---|---|
| DI01 | DI2.1 | Endschalter linker Torfluegel geschlossen | A |
| DI02 | DI2.2 | Endschalter rechter Torfluegel geschlossen | A |
| DI03 | DI2.3 | Lichtschranke Tor (Sicherheit, NC: 1=sicher/frei, 0=unterbrochen) | A |
| DI04 | DI2.4 | SG-Ready 1 (EVU, reserviert) | - |
| DI05 | DI2.5 | SG-Ready 2 (EVU, reserviert) | - |
| DI06 | DI2.6 | Reserve (PV-Ueberschuss kommt direkt per HA/MQTT) | - |
| DI07 | DI2.7 | Reserve (PV-Mangel kommt direkt per HA/MQTT) | - |
| DI08 | DI2.8 | Sammelstoerung WP1 | B |
| DI09 | DI2.9 | Sammelstoerung WP2 | B |
| DI10 | DI2.10 | Sammelstoerung BW-WP | B |
| DI11 | DI2.11 | Stromungswachter Brunnen | C |
| DI12 | DI2.12 | Oelbrenner Wasserdruckwachter (NC: 1=OK, 0=Stoerung) | A |
| DI13 | DI2.13 | Oelbrenner Betriebsmeldung | A |
| DI14 | DI2.14 | Oelbrenner Stoermeldung | A |
| DI15 | DI1.1 | Oelbrenner Sicherheitstemperaturbegrenzer STB (NC: 1=OK, 0=Stoerung) | A |
| DI16 | DI1.2 | Reserve | - |

Sicherheitswirkung Oelbrenner Bestand:

- DI12 Wasserdruckwachter offen / Wassermangel sperrt DO01 Brennerfreigabe und
  schaltet alle Heizungs-Hauptkreis-Pumpen ab, auch im Handbetrieb:
  DO02, DO18, DO19 sowie K-DO01 bis K-DO03.
- DI15 STB offen sperrt DO01 Brennerfreigabe hart, auch im Handbetrieb.
- DI14 Brenner-Stoermeldung wird gemeldet und per Telegram eskaliert, sperrt
  DO01 aber nicht. So bleibt die normale Anforderung am Feuerungsautomaten an,
  damit der Brenner direkt an seiner Taste entstoert werden kann.

### 4.2 Haupt-RevPi Analog (AIO #1-8)

Physische AIO-Karten der Hauptsteuerung:

- Karte 3 von links = AIO Adresse 29 / PiCtory `AIO1`
- Karte 4 von links = AIO Adresse 30 / PiCtory `AIO2`
- Karte 5 von links = AIO Adresse 31 / PiCtory `AIO3`
- Karte 6 von links = AIO Adresse 32 / PiCtory `AIO4`
- Karte 7 von links = AIO Adresse 33 / PiCtory `AIO5`
- Karte 8 von links = AIO Adresse 34 / PiCtory `AIO6`
- Karte 9 von links = AIO Adresse 35 / PiCtory `AIO7`
- Karte 10 von links = AIO Adresse 36 / PiCtory `AIO8`

**RTD (16 direkte Pt1000-Kanaele auf 8 AIO):**

| # | Physisch | AIO | Kanal | Beschreibung |
|---|---|---|---|---|
| RTD01 | RTD3.1 | 1 | RTD1 | Vorlauf Kessel/WP-Sammelvorlauf |
| RTD02 | RTD3.2 | 1 | RTD2 | Brauchwasser oben |
| RTD03 | RTD4.1 | 2 | RTD1 | Ruecklauf Kessel/WP-Sammelruecklauf |
| RTD04 | RTD4.2 | 2 | RTD2 | Brauchwasser unten / Ladetemperatur |
| RTD05 | RTD5.1 | 3 | RTD1 | Aussentemperatur (Nordwand, beschattet) |
| RTD06 | RTD5.2 | 3 | RTD2 | Brunnenwasser-Eintritt WT |
| RTD07 | RTD6.1 | 4 | RTD1 | Brunnenwasser-Austritt WT |
| RTD08 | RTD6.2 | 4 | RTD2 | Kuehlkreis-Vorlauf (kalte Seite WT zum OG) |
| RTD09 | RTD7.1 | 5 | RTD1 | Kuehlkreis-Ruecklauf vom OG |
| RTD10 | RTD7.2 | 5 | RTD2 | Pool-Wassertemperatur |
| RTD11 | RTD8.1 | 6 | RTD1 | Pool-WT Vorlauf |
| RTD12 | RTD8.2 | 6 | RTD2 | Pool-WT Ruecklauf |
| RTD13 | RTD9.1 | 7 | RTD1 | Vorlauf Nebengebaude |
| RTD14 | RTD9.2 | 7 | RTD2 | Ruecklauf Nebengebaude |
| RTD15 | RTD10.1 | 8 | RTD1 | WP1 Verdampfertemperatur / Reserve je nach WP-Modbus |
| RTD16 | RTD10.2 | 8 | RTD2 | BW-WP Vorlauf / Reserve je nach BW-WP-Modbus |

**AI (32 Kanaele V/I - fuer 0-10V/4-20mA, nicht direkte PT1000):**

| # | Physisch | AIO | Kanal | Beschreibung |
|---|---|---|---|---|
| AI01 | AI3.1 | 1 | AI1 | WP1 Vorlauf analoger Messumformer (optional; primaer Modbus) |
| AI02 | AI3.2 | 1 | AI2 | WP1 Ruecklauf analoger Messumformer (optional; primaer Modbus) |
| AI03 | AI3.3 | 1 | AI3 | WP2 Vorlauf analoger Messumformer (optional; primaer Modbus) |
| AI04 | AI3.4 | 1 | AI4 | WP2 Ruecklauf analoger Messumformer (optional; primaer Modbus) |
| AI05 | AI4.1 | 2 | AI1 | Reserve fuer 0-10V/4-20mA |
| AI06 | AI4.2 | 2 | AI2 | Reserve fuer 0-10V/4-20mA |
| AI07 | AI4.3 | 2 | AI3 | Reserve fuer 0-10V/4-20mA |
| AI08 | AI4.4 | 2 | AI4 | Reserve fuer 0-10V/4-20mA |
| AI09 | AI5.1 | 3 | AI1 | Reserve fuer 0-10V/4-20mA |
| AI10 | AI5.2 | 3 | AI2 | Reserve fuer 0-10V/4-20mA |
| AI11 | AI5.3 | 3 | AI3 | Reserve fuer 0-10V/4-20mA |
| AI12 | AI5.4 | 3 | AI4 | Reserve fuer 0-10V/4-20mA |
| AI13 | AI6.1 | 4 | AI1 | Reserve fuer 0-10V/4-20mA |
| AI14 | AI6.2 | 4 | AI2 | Reserve fuer 0-10V/4-20mA |
| AI15 | AI6.3 | 4 | AI3 | Reserve fuer 0-10V/4-20mA |
| AI16 | AI6.4 | 4 | AI4 | Reserve fuer 0-10V/4-20mA |
| AI17 | AI7.1 | 5 | AI1 | Reserve fuer 0-10V/4-20mA |
| AI18 | AI7.2 | 5 | AI2 | Reserve fuer 0-10V/4-20mA |
| AI19 | AI7.3 | 5 | AI3 | Reserve fuer 0-10V/4-20mA |
| AI20 | AI7.4 | 5 | AI4 | Reserve fuer 0-10V/4-20mA |
| AI21 | AI8.1 | 6 | AI1 | Reserve fuer 0-10V/4-20mA |
| AI22 | AI8.2 | 6 | AI2 | Reserve fuer 0-10V/4-20mA |
| AI23 | AI8.3 | 6 | AI3 | Reserve fuer 0-10V/4-20mA |
| AI24 | AI8.4 | 6 | AI4 | Reserve fuer 0-10V/4-20mA |
| AI25 | AI9.1 | 7 | AI1 | Reserve fuer 0-10V/4-20mA |
| AI26 | AI9.2 | 7 | AI2 | Reserve fuer 0-10V/4-20mA |
| AI27 | AI9.3 | 7 | AI3 | Reserve fuer 0-10V/4-20mA |
| AI28 | AI9.4 | 7 | AI4 | Reserve fuer 0-10V/4-20mA |
| AI29 | AI10.1 | 8 | AI1 | Reserve fuer 0-10V/4-20mA |
| AI30 | AI10.2 | 8 | AI2 | Reserve fuer 0-10V/4-20mA |
| AI31 | AI10.3 | 8 | AI3 | Reserve fuer 0-10V/4-20mA |
| AI32 | AI10.4 | 8 | AI4 | Reserve fuer 0-10V/4-20mA |

**AO (10 Kanaele 0-10V):**

| # | Physisch | AIO | Kanal | Beschreibung |
|---|---|---|---|---|
| AO01 | AO3.1 | 1 | AO1 | WP1 VL-Sollwert |
| AO02 | AO3.2 | 1 | AO2 | WP2 VL-Sollwert |
| AO03 | AO4.1 | 2 | AO1 | BW-WP VL-Sollwert |
| AO04 | AO4.2 | 2 | AO2 | 3WV Nebengebaude (zukuenftig 0-10V) |
| AO05 | AO5.1 | 3 | AO1 | Reserve (HK-Backup-Mischer sitzt am Keller-Slave) |
| AO06 | AO5.2 | 3 | AO2 | WP1 in Sammel-/Gesamtwaermekreis (zukuenftig 0-10V) |
| AO07 | AO6.1 | 4 | AO1 | WP2 in Sammel-/Gesamtwaermekreis (zukuenftig 0-10V) |
| AO08 | AO6.2 | 4 | AO2 | Pool-Senke am Gesamtwaermekreis (zukuenftig 0-10V) |
| AO09 | AO7.1 | 5 | AO1 | Filterpumpe Pool Drehzahl |
| AO10 | AO7.2 | 5 | AO2 | Reserve |
| AO11 | AO8.1 | 6 | AO1 | Reserve |
| AO12 | AO8.2 | 6 | AO2 | Reserve |
| AO13 | AO9.1 | 7 | AO1 | Reserve |
| AO14 | AO9.2 | 7 | AO2 | Reserve |
| AO15 | AO10.1 | 8 | AO1 | Reserve |
| AO16 | AO10.2 | 8 | AO2 | Reserve |

### 4.3 Slave-RevPi Hauptkeller / dezentrale Pumpengruppen (spater)

Designentscheidung Stand 2026-06-25: Die Mischerkreise im Hauptkeller sollen
bevorzugt ueber dezentrale RS485-Pumpengruppen-Platinen laufen, nicht mehr
zwingend ueber direkte DIO/AIO-Kanaele des Keller-RevPi. Jede Platine schaltet
lokal Pumpe, 3WV AUF und 3WV ZU, misst VL/RL per RTD und berechnet die
Mischer-Laufzeit aus der per Modbus vorgegebenen Zielposition selbst. Details:
[docs/pumpengruppe-rs485-platine.md](docs/pumpengruppe-rs485-platine.md).

Optionaler Zusatzkreis: Gewaechshaus-Lufterhitzer als Niedertemperatur-Senke
mit ca. 35 Grad Vorlauf. Dieser Kreis soll bevorzugt ebenfalls eine eigene
RS485-Pumpengruppen-Platine bekommen, damit Pumpe, Mischer und VL/RL-Fuehler
lokal am Abgang sitzen. Damit bleibt die Haupt-/Keller-RevPi-I/O-Belegung frei
und der Kreis kann spaeter ohne Umbau der bestehenden drei Mischerkreise
nachgeruestet werden.

Die folgende RevPi-I/O-Planung bleibt als Rueckfall-/Reservevariante bestehen,
falls einzelne Kreise direkt auf den Keller-RevPi gelegt werden. Sie deckt nur
die drei Hauptkeller-Mischerkreise ab; der Gewaechshauskreis benoetigt bei
direkter RevPi-Verdrahtung zusaetzliche RTD-Kanaele oder bleibt bei der
dezentralen Pumpengruppen-Platine.

Geplante physische Klemmenlogik fuer den Keller-Slave:

- Keller-Karte 1 = DIO links der CPU: `K-DO1.1-K-DO1.14`, `K-DI1.1-K-DI1.14`
- Keller-Karte 2 = erste AIO rechts der CPU: `K-RTD2.1-K-RTD2.2`, `K-AI2.1-K-AI2.4`, `K-AO2.1-K-AO2.2`
- Keller-Karte 3 = zweite AIO rechts der CPU: `K-RTD3.1-K-RTD3.2`, `K-AI3.1-K-AI3.4`, `K-AO3.1-K-AO3.2`
- Eine Keller-Karte 4 ist aktuell nicht verbaut. Der Klimakreis-OG kommt spaeter ueber die dezentrale Pumpengruppen-Platine.

**DIO (14 DI + 14 DO):**

| # | Physisch | Beschreibung |
|---|---|---|
| K-DO01 | K-DO1.1 | Pumpe Mischer FBH-EG |
| K-DO02 | K-DO1.2 | Pumpe Mischer Klimakreis-OG |
| K-DO03 | K-DO1.3 | Pumpe Heizkorper-Backup OG |
| K-DO04 | K-DO1.4 | FU Brunnenpumpe Freigabe / Run |
| K-DO05 | K-DO1.5 | Reserve |
| K-DO06 | K-DO1.6 | Reserve |
| K-DO07 | K-DO1.7 | Reserve |
| K-DO08 | K-DO1.8 | Reserve |
| K-DO09 | K-DO1.9 | Reserve |
| K-DO10 | K-DO1.10 | Reserve |
| K-DO11 | K-DO1.11 | Reserve |
| K-DO12 | K-DO1.12 | Reserve |
| K-DO13 | K-DO1.13 | Reserve |
| K-DO14 | K-DO1.14 | Reserve |
| K-DI01 | K-DI1.1 | Druckwachter Heizkreis (optional) |
| K-DI02 | K-DI1.2 | Stromungswachter Mischerkreis (optional) |
| K-DI03 | K-DI1.3 | Reserve |
| K-DI04 | K-DI1.4 | Reserve |
| K-DI05 | K-DI1.5 | Reserve |
| K-DI06 | K-DI1.6 | Reserve |
| K-DI07 | K-DI1.7 | Reserve |
| K-DI08 | K-DI1.8 | Reserve |
| K-DI09 | K-DI1.9 | Reserve |
| K-DI10 | K-DI1.10 | Reserve |
| K-DI11 | K-DI1.11 | Reserve |
| K-DI12 | K-DI1.12 | Reserve |
| K-DI13 | K-DI1.13 | Reserve |
| K-DI14 | K-DI1.14 | Reserve |

**AIO (2x AIO = 8 AI + 4 RTD + 4 AO):**

| # | Physisch | Beschreibung |
|---|---|---|
| K-RTD01 | K-RTD2.1 | Vorlauf Heizkorper-Backup OG |
| K-RTD02 | K-RTD2.2 | Ruecklauf Heizkorper-Backup OG |
| K-RTD03 | K-RTD3.1 | Ruecklauf FBH-EG |
| K-RTD04 | K-RTD3.2 | Vorlauf FBH-EG nach Mischer |
| K-AI01 | K-AI2.1 | Brunnen-Drucksensor 4-20mA, 0-10 bar |
| K-AI02 | K-AI2.2 | Reserve fuer 0-10V/4-20mA |
| K-AI03 | K-AI2.3 | Reserve fuer 0-10V/4-20mA |
| K-AI04 | K-AI2.4 | Reserve fuer 0-10V/4-20mA |
| K-AI05 | K-AI3.1 | Reserve fuer 0-10V/4-20mA |
| K-AI06 | K-AI3.2 | Reserve fuer 0-10V/4-20mA |
| K-AI07 | K-AI3.3 | Reserve fuer 0-10V/4-20mA |
| K-AI08 | K-AI3.4 | Reserve fuer 0-10V/4-20mA |
| K-AO01 | K-AO2.1 | FU Brunnenpumpe Drehzahlsollwert 4-20mA |
| K-AO02 | K-AO2.2 | Interner Sollwert Mischer FBH, aktuell ueber R421B16-Laufzeitrelais |
| K-AO03 | K-AO3.1 | Interner Sollwert Mischer Klima-OG, spaeter dezentrale Pumpengruppen-Platine |
| K-AO04 | K-AO3.2 | Interner Sollwert Mischer Heizkorper-Backup OG, aktuell ueber R421B16-Laufzeitrelais |

### 4.4 Modbus-Geraete (separate RS485-Busse ueber Waveshare-Gateways)

**Bus 1 (Heizungsraum, RTU 9600 8N1):** Warmepumpen
- Slave 1: WP1
- Slave 2: WP2

**Bus 2 (Heizungsraum):** BW-WP + Pool-/Filterperipherie
- Slave 10: Brauchwasser-WP
- Slave 11: Pool-/Filtersteuerung (optional; keine eigene Pool-WP)

**Bus 3 (Slave-Steuerung Hauptkeller, RS485-ETH ins VLAN):** Klima-OG
- Slave 20-24: 5x Klima-Innengerate OG

**Bus 4 (Hauptkeller, RTU, Pumpengruppen):** dezentrale Mischerkreis-Platinen
- Slave 30: Pumpengruppe FBH-EG
- Slave 31: Pumpengruppe Klimakreis-OG
- Slave 32: Pumpengruppe Heizkoerper-Backup OG
- Slave 33: Pumpengruppe Gewaechshaus-Lufterhitzer (optional, VL-Soll ca. 35 Grad)
- Registerentwurf siehe `docs/pumpengruppe-rs485-platine.md`

**Inter-CPU-Kommunikation:**
- Slave-RevPi exponiert seine Werte als Modbus-TCP Server (Port 502)
- Haupt-RevPi pollt periodisch (1 Hz)

## 5. Hydraulik-Schema (vereinfacht, Endausbau)

Siehe [docs/hydraulik.md](docs/hydraulik.md).

## 6. Software-Architektur

### 6.1 Stack-Entscheidung: Python statt OpenPLC
- Heizungsregelung nicht zeitkritisch (Zykluszeit 1-2 s reicht)
- Visu komplett in HA -> keine Web-UI auf RevPi notig
- Einheitliche Code-Basis, leicht zu maintainen, git-versionierbar
- Bibliotheken: `revpimodio2`, `paho-mqtt`, `pymodbus`, `pydantic`

### 6.2 Verzeichnisstruktur
```
/opt/heizung/
├── heizung.py              # Hauptprogramm (asyncio Event-Loop)
├── config/
│   ├── io_map.yaml         # I/O-Kanalbelegung (Single Source of Truth)
│   ├── modbus_map.yaml     # Modbus-Register-Definitionen WP/Klima
│   ├── settings.yaml       # Sollwerte, Heizkurve, Hand/Auto-State
│   └── mqtt.yaml           # MQTT-Topics, HA-Discovery
├── lib/
│   ├── iohw.py             # RevPi-I/O-Wrapper
│   ├── modbus_master.py    # Modbus-RTU/TCP-Master mit Reconnect
│   ├── regler.py           # PI-Regler, Heizkurve, Sequenzlogik
│   ├── mqtt_bridge.py      # MQTT-Client + HA-Discovery + State-Sync
│   ├── failsafe.py         # Watchdog + Fallback-Logik
│   ├── hand_auto.py        # Hand/Auto-Override pro Kanal, nur explizit rueckstellbar
│   └── state.py            # Persistierter State (JSON, atomic-write)
├── state/
│   └── state.json
└── deploy/
    └── heizung.service     # systemd-Unit
```

### 6.3 Regelungs-Logik (Hauptregelkreis, 1 Hz)
1. **I/O lesen**: Alle DI/AI von RevPi, alle Modbus-Werte
2. **HA-Anforderungen abrufen** (per MQTT-Subscribe, gecached)
3. **Anforderungsberechnung**:
   - Hoechster geforderter VL aller aktiven Senken am Gesamtwaermekreis + Aufschlag (Mischer-Reserve) = WP-VL-Soll
   - Anforderungen werden nur verarbeitet, wenn die jeweilige Senke in HA/State freigegeben ist
4. **WP-Steuerung** (Sequenz):
   - WP1 und WP2 speisen beide denselben Gesamtwaermekreis; keine feste Zuordnung WP/Haus/Pool
   - Jede Waermequelle hat eine Freigabe: Oelbrenner, WP1, WP2, BWWP
   - Bei kleiner Anforderung: eine WP
   - Bei mehreren aktiven Senken oder hoher Last: beide WPs parallel
   - Wechselrhythmus (alle 24 h) damit Laufzeit gleich verteilt
   - Bei PV-Ueberschuss aus HA/MQTT + Pool unter Maxtemp: Pool vorrangig laden
5. **Mischer-Regelung** (an Slave-CPU):
   - PI-Regler auf Mischer-Vorlauf zu Soll
   - Soll vom Master per Modbus-TCP uebergeben
6. **Hand-Override**: Pro Kanal vor Schreib-Aktion pruefen
7. **MQTT-Publish**: State raus
8. **Failsafe-Watchdog**: HA-Last-Seen Timestamp pruefen

### 6.4 Hand/Auto-Logik
- Hand-Modus: Wert (DO bool, AO 0-100%) wird festgehalten
- Kein automatischer Rueckfall auf Auto: Handwerte/Sperren bleiben aktiv, bis sie in der Visu explizit auf Auto gesetzt werden
- Persistierung: Hand-Stati ueberleben Neustart
- In HA sichtbar: pro Kanal eine Switch-Entitat "Hand-Modus" + Number/Switch fur den Wert

### 6.4.1 Quellen-/Senkenfreigaben

- Jede Waermequelle ist per HA-Schalter freigebbar/sperrbar:
  `oelbrenner`, `wp1`, `wp2`, `bwwp`.
- Jeder Heizkreis bzw. jede Senke ist per HA-Schalter freigebbar/sperrbar:
  `fbh_eg`, `klima_og`, `nebengeb`, `hk_backup`, `pool`.
- Freigaben werden lokal auf dem RevPi in `state/freigaben.json` persistiert.
- Startzustand: Oelbrenner und FBH-EG freigegeben; WP1/WP2/BWWP/Pool/etc.
  gesperrt, bis sie nach Einbau bewusst in HA aktiviert werden.
- So kann der Oelbrenner parallel im System bleiben, bis das Oel leer ist.

### 6.4.2 Brunnenpumpe Konstantdruck (Keller)

- Die Brunnenpumpe sitzt im Keller und bekommt einen Frequenzumrichter.
- Druckmessung: PT-506 Drucksensor, 4-20 mA, 0-10 bar, in der Brunnenleitung.
- Anschluss Drucksensor an Keller-AIO1 / K-AI01:
  - RevPi AIO Input 1 ist in PiCtory auf 4-20 mA parametriert.
  - Fuer Strommessung muss am AIO Input 1 die Bruecke `*` zu `+` gesetzt sein.
  - 2-Leiter-Sensor: +24 V -> Sensor +, Sensor -/Signal -> AIO Input 1 `+`,
    AIO Input 1 `-` -> 0 V.
  - Unter 4 mA meldet die AIO-Karte Range-Fehler; rot blinkende IN-LED ist
    dann erwartbar. Aktuell muss bei 0 bar ca. 4 mA bzw. 4000 uA im Prozessbild
    anliegen.
- Ausgaenge am Keller-RevPi:
  - `brunnen_fu_soll`: Analogausgang 4-20 mA als Drehzahlsollwert zum FU.
    In der Handbedienung entspricht 0 % = 4 mA, 50 % = 12 mA, 100 % = 20 mA.
    Der FU ist am AVI-Eingang so skaliert, dass 0 % Ausgang den FU stoppt.
  - `brunnen_pumpe_freigabe`: optionaler DO als zusaetzliche FU-Run/Freigabe;
    der normale Regel-Stopp erfolgt ueber `brunnen_fu_soll = 0 %`.
- Der vorhandene 100-l-Druckspeicher bleibt im System.
- Durchflusserkennung:
  - Der vorhandene ESPHome-Zaehler `wasserverbrauch-pumpe` misst den aktuellen
    Verbrauch als `Wasserdurchfluss` in L/min und den Gesamtzaehler in Liter.
  - Die Steuerung nutzt fuer die Pumpenabschaltung den Momentanwert, nicht den
    Gesamtzaehler. Der Gesamtzaehler bleibt nur fuer Verbrauchsstatistik.
  - Ziel-Schnittstelle ist lokales Modbus vom ESP32 zur Hauptsteuerung; die
    aktuelle ESPHome-Basiskonfig liegt unter `docs/esphome/wasserverbrauch-pumpe.yaml`.
  - Geplantes Register: Input-Register 0 = `Wasserdurchfluss L/min * 100`,
    z.B. 125 = 1,25 L/min.
- Regelstrategie:
  - Wenn kein Abnehmer offen ist, steigt der Druck bis `brunnen_max_druck_bar`; dann wird abgeschaltet.
  - Falls der Druck diesen Abschaltpunkt wegen Pumpenkennlinie/Bypass nicht erreicht:
    Der Kein-Durchfluss-Timer wird erst aktiv, wenn der Druck im Bereich des
    Regeldrucks liegt (`brunnen_regeldruck_bar` minus Toleranz). Bleibt der
    Flowmeter dann laenger als `brunnen_flow_timeout_s` unter
    `brunnen_flow_min_l_min`, wird ebenfalls abgeschaltet.
  - Bei zu niedrigem Druck laeuft der Kein-Durchfluss-Timer nicht, damit die
    Pumpe trotz Tropfschlauch/kleiner Abnahme Druck aufbauen kann.
  - Im Normalbetrieb wird erst bei Unterschreiten von `brunnen_min_druck_bar`
    gestartet.
  - Wenn ein Abnehmer offen ist, regelt der FU-Sollwert auf `brunnen_regeldruck_bar`.
- In HA einstellbar:
  - `brunnen_min_druck_bar`
  - `brunnen_max_druck_bar`
  - `brunnen_regeldruck_bar`
  - `brunnen_fu_start_pct`
  - `brunnen_fu_max_pct`
  - `brunnen_kp_pct_pro_bar`
  - `brunnen_fu_ramp_up_pct_s`
  - `brunnen_fu_ramp_down_pct_s`
  - `brunnen_flow_min_l_min`
  - `brunnen_flow_timeout_s`
  - `brunnen_flow_stop_tolerance_bar`
  - Startwerte fuer die schnelle mehrstufige Kreiselpumpe: Start 20 %, FU Max
    zunaechst testweise 60-100 %, Kp 25 %/bar, Rampe hoch 25 %/s, Rampe runter 500 %/s. Die Pumpe regelt damit bewusst
    langsam hoch, nimmt aber bei schliessendem Hahn bzw. schlagartigem Druckanstieg
    sehr schnell Leistung weg. Bei Ueberschwingen zuerst Kp senken oder Maxdruck
    knapper setzen; bei zu traegem Druckaufbau Rampe hoch schrittweise erhoehen.
- In HA sichtbar:
  - aktueller Druck
  - FU-Sollwert in %
  - Durchfluss in L/min
  - Zeit ohne Durchfluss in s
  - Restzeit bis zur Flow-Abschaltung in s
  - aktiv/inaktiv
  - Regelgrund (`bereit`, `minderdruck_start`, `regelt`, `maxdruck_erreicht`,
    `kein_durchfluss_stop`, `sensor_unplausibel`)

### 6.5 Failsafe-Verhalten
- **Trigger**: MQTT-Verbindung > 60 s verloren ODER HA-Heartbeat-Topic > 5 min nicht aktualisiert
- **Modus**: Witterungsgefuhrte Heizkurve
  - Default-Kurve: A-12/W45, A0/W38, A+15/W25
  - Bei Sensor-Ausfall: Festwert 50 Grad
- Alle Heizpumpen: AN
- Mischer: Position halten (oder bei 0-10V auf 70%)
- WPs: weiterlaufen mit Failsafe-VL-Soll

### 6.6 Heizkurve & dynamische Kesseltemperatur
- Heizkurve parametrierbar in HA (Number-Entitaten fur Stuetzpunkte)
- Normalbetrieb: WP-VL = max(geforderte_VL_aller_aktiven_Senken_am_Gesamtwaermekreis) + 5 K Mischer-Reserve
- Failsafe: WP-VL = Heizkurve(Aussentemp)
- HA sieht **immer** die aktuelle Ziel-VL

### 6.7 PV-Integration (Phase F)
- PV-Signale kommen direkt aus Home Assistant per MQTT, nicht ueber RevPi-DI:
  - `heizung/pv/ueberschuss/set`: WPs duerfen Pool aufladen ueber Soll, max. 40 Grad
  - `heizung/pv/mangel/set`: WPs auf Sparmodus drosseln (z.B. nur WP1, max. 50% Leistung)
- Logik: Pool wird als thermischer Puffer genutzt
- Der Pool ist dabei eine Senke am gemeinsamen Gesamtwaermekreis, nicht fest einer bestimmten WP zugeordnet.

## 7. MQTT-Topic-Struktur (HA-Discovery)

Broker: `mqtt.esrv.center` mit User `vbnet`/`vbnet` (bereits in HA eingerichtet).

Siehe [docs/mqtt-topics.md](docs/mqtt-topics.md).

## 8. Visualisierung in HA

Eigenes Dashboard `Heizung` mit:
- **Ubersichts-Karte** (Picture-Elements mit Status-Overlays)
- **WP-Karten** je WP: Soll/Ist-VL, Leistung, COP, Laufzeit, Fehler
- **Mischer-Karten** mit Slider + Hand/Auto + Ist-Position
- **Anforderungs-Karte** spiegelt die HA-Heizungsanforderung
- **Pool-Karte** Soll/Ist + PV-Modus
- **Tor-Karte** 4 Buttons + Status + Lichtschranke
- **Heizkurve-Karte** 3 Stuetzpunkt-Slider + Plot
- **Failsafe-Karte** Status + manueller Force-Failsafe-Schalter
- **Freigabe-Karten** fuer Quellen und Senken; nur gesetzte Haken werden durch die Regelung verwendet

Verlaufskurven & History: nativ ueber HA-Recorder + InfluxDB-Add-on.

## 9. Sicherheits- & Hardware-Konzept

- 230 V Lastschalten ausschliesslich ueber Koppelrelais
- WP-Freigaben potentialfrei (Reed-Relais)
- Tor-Steuereingange potentialfrei (Koppelrelais simuliert Taster)
- Lichtschranke hardwareseitig auch direkt an Torantrieb-Sicherheitseingang
- Sensor-Plausibilitat (-20..+95 Grad, Pool +5..+45) -> Out-of-Range = fault
- 2 DI fuer SG-Ready reserviert, Logik aber **inaktiv** (lohnt bei 30 kWp + 100 kWh kaum)

## 10. Phasen-Plan (Reihenfolge)

| Phase | Inhalt | Vorbedingung |
|---|---|---|
| **0 - Vorbereitung** | VLAN 25 + pfSense + UniFi, RevPi #1 ans Netz, PW & SSH-Key, Repo, PiCtory-Config, systemd-Service-Geruest, MQTT-Smoke | RevPi physisch da |
| **A - Ist-Migration Brenner** | Brenner+BW-Pumpe+Tor 1:1 auf RevPi, HA-Anforderung als Auto-Trigger | Phase 0 |
| **B - Slave-Steuerung Keller** | RevPi #2 in Hauptkeller, Mischer FBH/OG-Klima, Modbus-TCP | A stabil |
| **C - Brunnen-Kuhlung** | Brunnenpumpe + WT-Sensoren, Sommerkuhlung freigegeben | B |
| **D - WP-Umbau (Hardware-Tag)** | Brenner raus, 2x 16 kW WP rein, BW-WP rein, alle 3WV-Selektoren, Modbus-RTU zu WPs | WPs beschafft + Heizungsbauer |
| **E - Klima-OG + Pool** | Klima-Innengerate + Pool-Hydraulik + WT + Filter | D, Klima-Modelle beschafft |
| **F - PV-Integration** | HA/MQTT-Signale, PV-Uberschuss-Logik | PV in Betrieb |
| **G - Tuning** | Heizkurve fein, COP-Monitoring, Hand-Timeouts final | im Betrieb |

## 11. Offene Punkte / Risiken

| # | Thema | Entscheidung benoetigt bis |
|---|---|---|
| O1 | WP-Favorit Sunex NEXUS M18 EVI 18 kW pruefen: Modbus-/Linkage-Doku, Lieferumfang, Gewaehrleistung | Vor Phase D |
| O2 | Konkretes Klima-Innengerat-Modell + Modbus-Doku | Vor Phase E |
| O3 | Brauchwasser-WP-Modell | Vor Phase D |
| O4 | 3WV-Stellantriebe: 230V/Auf-Zu mit dezentraler RS485-Pumpengruppen-Platine finalisieren | Vor KiCad/Fertigung |
| O5 | Schaltschrank Slave-Steuerung Hauptkeller Groesse + Lieferant | Vor Phase B |
| O6 | Modbus-Register-Listen sammeln + dokumentieren | je nach Geraet |
| O7 | HK-Backup OG: Eigener Strang oder ueber Klimakreis-OG? | Vor Phase E |
| O8 | Pool-Filterpumpen-Modell (Inverter oder klassisch)? | Vor Phase E |
| O9 | Lichtschranke Modell + Spannung (24V DC bevorzugt) | Vor Phase A |
| O10 | Gewaechshaus-Heizkreis: Lufterhitzer-Leistung, Frostschutzstrategie, Rohrweg und Pumpengruppenposition festlegen | Vor Umsetzung Gewaechshaus |

## 12. Verifikation pro Phase

**Phase 0:**
- `ssh -i ~/.ssh/id_ed25519_heizung pi@10.1.25.10` funktioniert
- Ping aus Standard-LAN klappt nicht (VLAN-Trennung), aus HA-VLAN via FW-Regel ja
- MQTT-Test: `mosquitto_pub -h mqtt.esrv.center ... -t heizung/test -m hallo` -> HA empfaengt

**Phase A:**
- HA-Heizungsanforderung schaltet Brenner ein -> DO01 = HIGH
- Brenner im Failsafe (HA aus): bleibt an wenn AI Aussen < 5 Grad
- Tor "ganz auf" via HA -> Impuls 1000 ms am DO20
- Endschalter "zu" -> DI01 aendert in HA sichtbar
- Lichtschranke NC: DI03=1 zeigt in HA sicher/frei, Unterbrechung DI03=0 zeigt unsicher; Unterbrechung waehrend Tor schliesst: sofortiger Stopp-Impuls

**Phase B:**
- Slave-CPU ping ueber VLAN 25
- Modbus-TCP-Request vom Master liest Mischer-Status
- RS485-Pumpengruppen antworten auf Modbus, schalten Pumpe und fahren Zielposition per Laufzeitlogik an
- Bei Slave-CPU-Crash: Master loggt Verbindungsverlust, faellt auf Failsafe

**Phase D:**
- WP1+WP2 reagieren auf Modbus-Sollwert (mbpoll-Test)
- Sammelstoerung-DI triggert HA-Notification
- Bei manueller WP1-Abschaltung uebernimmt WP2 die Anforderung

**Phase E:**
- Klima-Innengerate schaltbar von HA, Ist-Ventilstellung lesbar
- Sommerkuhlung: Brunnenpumpe + Mischer Klima-OG foerdert kaltes Wasser
- Pool: 3WV schaltet, WP faehrt max. 40 Grad VL, Pool-Ist steigt

**Phase F:**
- PV-Uberschuss-Signal -> Pool-Aufladelogik aktiv (in HA sichtbar)
- PV-Mangel: WP2 gesperrt, WP1 max. 50%

## 13. Bewusst NICHT im Scope
- Eigene Web-Visu auf dem RevPi (HA uebernimmt das)
- OpenPLC / IEC 61131 (Python-Stack stattdessen)
- Pufferspeicher (kein Puffer geplant, Pool ist Pseudo-Puffer)
- Warmemengenzahler/Strommessung (macht HA per Shellys)
- Brauchwasser-Solar / WP-Solar-Kombi (BWWP autark)
- Saunabetrieb (Saunaraum bleibt Lager/unbeheizt)

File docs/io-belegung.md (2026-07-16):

# I/O-Belegung Hauptsteuerung Heizungsraum

Diese Datei ist eine **lesbare** Sicht auf `config/io_map.yaml.example`.
Bei Aenderungen IMMER zuerst die YAML anpassen, dann diese Tabelle nachziehen.

## RevPi-Modulregeln

Korrekte Kapazitaeten laut Revolution-Pi-Doku:

| Modul | Kanaele |
|---|---|
| DIO | 14 DI + 14 DO |
| DI | 16 DI |
| AIO | 4 AI (V/I) + 2 RTD (Pt100/Pt1000) + 2 AO (V/I) |
| RevPi Connect 4 | max. 10 Erweiterungsmodule, 5 links + 5 rechts |

Quellen:
- https://revolutionpi.com/en/docs/revpi-dio
- https://revolutionpi.com/en/docs/revpi-di
- https://revolutionpi.com/en/docs/revpi-aio
- https://revolutionpi.com/en/docs/revpi-connect-4

## Hardware-Layout Hauptsteuerung (links nach rechts)

| Adresse | Seite | Typ | HW-Version | Bemerkung |
|---|---|---|---|---|
| 27 | links | DIO | 1.5 | DO15-DO28, DI15-DI28 |
| 28 | links | DIO | 1.5 | DO01-DO14, DI01-DI14 |
| 29 | links | AIO | 1.4 | RTD01-02, AI01-04, AO01-02 |
| 30 | links | AIO | 1.4 | RTD03-04, AO03-04 |
| 31 | links | AIO | 1.4 | RTD05-06, AO05-06 |
| 0 | CPU | CPU | 1.0 | RevPi Connect 4 WLAN 32/4GB |
| 32 | rechts | AIO | 1.4 | RTD07-08, AO07-08 |
| 33 | rechts | AIO | 1.4 | RTD09-10, AO09-10 |
| 34 | rechts | AIO | 1.4 | RTD11-12 |
| 35 | rechts | AIO | 1.4 | RTD13-14 |
| 36 | rechts | AIO | 1.4 | RTD15-16 |

Damit sind die 10 Erweiterungsmodule des Connect 4 voll belegt.

## Kapazitaet Hauptsteuerung

| Typ | Bedarf geplant | Verfuegbar | Reserve |
|---|---:|---:|---:|
| DO | 21 | 28 | 7 |
| DI | 16 | 28 | 12 |
| RTD direkt | 16 | 16 | 0 |
| AI V/I | 4 optional + Reserve | 32 | 28 |
| AO V/I | 10 | 16 | 6 |

Hinweis: Direkte PT1000-Fuehler gehoeren auf RTD-Kanaele. Die AI-Kanaele sind
fuer 0-10V/4-20mA-Messumformer, nicht fuer direkte PT1000.

## Wichtige Punkte

- **DI01/DI02 Tor**: DI01 = linker Fluegel geschlossen, DI02 = rechter Fluegel geschlossen.
- **DI03 Lichtschranke Tor**: NC-Sicherheitskreis, elektrisch `1 = sicher/frei`, `0 = unterbrochen`. HA-Discovery invertiert die `safety`-Binary-Sensor-Anzeige, damit `1` als sicher angezeigt wird.
- **DO20/DO21 Tor**: Nur 1000 ms-Impulse (Taster-Simulation), keine Dauerstellung. HA sendet semantische Befehle `oeffnen_ganz`, `oeffnen_halb` und `schliessen`; die Steuerung sperrt unnoetige Befehle anhand der beiden Geschlossen-Endschalter.
- **Brauchwasser aktuell**: DO01 = Oelbrenner-Freigabe, DO02 = Brauchwasser-Ladepumpe. Die Speicherladung laeuft nur mit Freigabe `brauchwasser` und plausiblem oberen Speicherfuehler `RTD02/bw_oben`; BWWP bleibt separat auf DO05/AO03 fuer spaeter.
- **Oelbrenner Rueckmeldungen**: DI12 = Wasserdruckwachter (NC/24V), DI13 = Oelbrenner Betriebsmeldung, DI14 = Oelbrenner Stoermeldung, DI15 = Sicherheitstemperaturbegrenzer/STB (NC/24V). Bei Stoerung und bei Rueckkehr auf OK sendet Home Assistant eine Telegram-Nachricht. DI14 meldet nur den Feuerungsautomaten; DO01 bleibt bei normaler Anforderung an, damit die Entstoertaste am Brenner jederzeit wirkt.
- **Wassermangel / DI12**: Bei geoeffnetem Wasserdruckwachter werden Brennerfreigabe und alle Heizungs-Hauptkreis-Pumpen hart abgeschaltet, auch wenn ein Handwert aktiv ist. Betroffen sind DO02, DO18, DO19 sowie K-DO01 bis K-DO03; Brunnenpumpe/FU ist davon nicht betroffen.
- **Klima-OG Kuehlmodus**: Wenn `klima_og.kuehlung_enabled` aktiv ist und Klima OG einen niedrigen VL-Sollwert anfordert, schliesst die Steuerung den Heizmischer (`K-AO03 = 0 %`), nimmt Klima OG aus dem Heizrouting und schaltet den Brunnen-/Waermetauscherweg: DO06 `brunnen_mv`, K-DO02 `pumpe_klima_og`, K-DO04 `brunnen_pumpe_freigabe` und mindestens den Startwert auf K-AO01 `brunnen_fu_soll`. Default bleibt aus, bis Hydraulik/Ventil fertig sind.
- **Keller-Uebergangsaufbau R421B16**: Wenn `keller_relais.enabled` aktiv ist, ersetzt das Waveshare/R421B16-Modul die physische Ausgabe fuer die drei Heizkreis-Pumpengruppen. Relais 1/2/3 = FBH EG (Pumpe/Fahrt/Richtung), Relais 4/5/6 = HK-Backup OG, Relais 7/8/9 = Klima OG. Routing und Automatik nutzen weiter die normalen Pumpen-/Mischer-Komponenten; die neun Handkanaele liegen separat auf `KR-DO01..KR-DO09`. Die Temperaturen kommen weiterhin als lokale PT1000 auf die Hauptsteuerung. Das Modul wird zyklisch per Modbus-FC03 gepollt; Ausfall setzt A3 rot und triggert die HA/Telegram-Stoermeldung.
- **Mischer-Auf/Zu-Paare** (z.B. DO08/DO09): Software-seitig sicherstellen, dass nie beide Richtungen gleichzeitig aktiv sind.
- **WP1/WP2**: Beide WPs speisen den gemeinsamen Sammel-/Gesamtwaermekreis. DO08-DO11/AO06-AO07 sind keine Haus/Pool-Auswahl, sondern Quellen-Freigabe in diesen Kreis.
- **Pool**: Der Pool ist eine Senke am Gesamtwaermekreis. DO12/DO13/AO08 schalten den Pool-Kreis, DO19 die Pool-Kreis-Pumpe.
- **HK-Backup OG**: Der 3WV/Mischer gehoert in den Hauptkeller zum Slave-RevPi. DO16/DO17/AO05 der Hauptsteuerung sind Reserve.
- **PV-Signale**: PV-Ueberschuss und PV-Mangel liegen nicht auf RevPi-DI. Sie kommen direkt aus HA per MQTT (`heizung/pv/ueberschuss/set`, `heizung/pv/mangel/set`).
- **PiCtory-Namen**: Stand 2026-06-17 aus der gruenen Hauptsteuerung uebernommen. Doppelte Modultypen erhalten PiCtory-Suffixe wie `_i17` oder `_i14`.

## Slave-Steuerung Hauptkeller

Ist-Stand 2026-06-18:

- RevPi #2 ist unter `10.1.25.11` erreichbar.
- Auf dem Keller-RevPi laeuft **keine eigene Heizungsregelung**.
- `heizung.service` ist dort `disabled/inactive`.
- `heizung-keller-slave.service` ist der aktive Autostart-Service.
- Der Keller-RevPi stellt seine I/O nur per Modbus TCP auf Port `502` bereit.
- Die Hauptsteuerung `10.1.25.10` liest Keller-Sensoren per Modbus, berechnet
  die Regelung zentral und schreibt die gewuenschten Keller-Ausgaenge zurueck.
- `piTest -d` meldet die Keller-Erweiterungsmodule bis zur Spannungsversorgung
  als `NOT present`.

Planungsstand 2026-06-25: Die drei Mischerkreise sollen bevorzugt ueber
dezentrale RS485-Pumpengruppen-Platinen laufen. Diese Boards schalten lokal
Pumpe, 3WV AUF/ZU, messen VL/RL und setzen die vom Master vorgegebene
Zielposition per Laufzeitlogik um. Der direkte RevPi-I/O-Plan unten bleibt als
Reserve-/Rueckfallvariante. Hardwareentwurf:
[pumpengruppe-rs485-platine.md](pumpengruppe-rs485-platine.md).

Optional ist ein vierter Niedertemperaturkreis fuer das Gewaechshaus geplant:
Lufterhitzer mit ca. 35 Grad Vorlauf. Dieser Kreis soll als weitere RS485-
Pumpengruppen-Platine laufen.

Ist-Stand 2026-07-08: Am Keller-RevPi sind nur zwei AIO-Karten vorhanden.
Die vier lokalen RTD-Kanaele sind fuer HK-Backup und FBH belegt. Klima OG
kommt spaeter ueber die eigene Pumpengruppen-Platine und liegt nicht mehr auf
lokalen Keller-RTD-Kanaelen.

Belegung:

| Modul | Zweck |
|---|---|
| DIO | 14 DI + 14 DO fuer Pumpen, FU-Freigabe, lokale Kontakte |
| CPU | RevPi #2, 10.1.25.11 |
| AIO x2 | 4 RTD fuer HK-Backup/FBH + AO fuer FU/interne Mischer-Sollwerte + AI fuer Drucksensor/Reserve |

Vorgeschlagene lokale I/O-Zuordnung fuer den Slave:

| Kanal | Funktion |
|---|---|
| DO01 | Pumpe FBH EG |
| DO02 | Pumpe Klima OG |
| DO03 | Pumpe HK-Backup OG |
| DO04 | FU Brunnenpumpe Freigabe / Run |
| DO05-DO14 | Reserve |
| DI01-DI03 | Stoer-/Rueckmeldekontakte FBH/Klima/HK |
| DI04-DI14 | Reserve |
| RTD01/RTD02 | HK-Backup OG VL/RL auf K-RTD2.1/K-RTD2.2 |
| RTD03/RTD04 | FBH EG RL/VL auf K-RTD3.1/K-RTD3.2 |
| AI01 | PT-506 Brunnen-Drucksensor 4-20 mA, 0-10 bar |
| AI02-AI08 | Reserve 0-10V/4-20mA |
| AO01 | FU Brunnenpumpe Drehzahlsollwert 4-20 mA |
| AO02-AO04 | interne Mischer-Sollwerte FBH/Klima/HK; aktuell ueber R421B16-Laufzeitrelais bzw. spaeter dezentrale Platine |

RS485-Pumpengruppen am Bus 4:

| Slave | Kreis |
|---|---|
| 30 | FBH EG |
| 31 | Klima OG |
| 32 | HK-Backup OG |

Modbus-TCP-Test Nebengebaeude:

| Kreis | Ziel | Register/Transport |
|---|---|---|
| Nebengebaeude | ESP-Pumpengruppe `10.1.20.189:502`, Unit-ID `30` | Holding 0..3: Sequenz, Pumpe, Mischerposition x10, Mode; Input 0..5: Status, Position, VL/RL, Sequenz, Fehler |

In `settings.yaml` wird dafuer `pumpengruppen.nebengeb` aktiviert. Die
berechneten lokalen Ausgaenge `pumpe_nebengeb` und `sv_nebengeb_pct` bleiben
als logische/HA-Werte erhalten, werden bei `disable_local_outputs: true` aber
nicht mehr physisch auf DO18/AO04 geschrieben. DO14/DO15 werden im Testmodus
ebenfalls nicht lokal geschaltet.
| 33 | Gewaechshaus-Lufterhitzer, optional, VL-Soll ca. 35 Grad |

Brunnenregelung: Der Drucksensor und die FU-Ausgaenge sitzen am Keller-RevPi,
aber die Konstantdruckregelung laeuft zentral auf der Hauptsteuerung. Der
Keller-RevPi fuehrt nur die per Modbus TCP geschriebenen DO/AO-Sollwerte aus.

Wichtig fuer AI01: RevPi-AIO-Strommessung braucht die Bruecke `*` zu `+` am
jeweiligen Eingang. Bei K-AI01/AIO Input 1 muss bei 0 bar ca. 4 mA anliegen;
ein Wert nahe 0 mA setzt `InputStatus` auf Unterbereich und laesst die IN-LED
rot blinken.

Wichtig fuer die Keller-RTDs: In PiCtory muessen die AIO-Parameter auf
`RTDType = 1` und `RTD*Wiring = 2` stehen. Bei 2-Draht-PT1000-Fuehlern sind
zusaetzlich die Drahtbruecken am RTD-Eingang erforderlich; sonst liefert die
AIO `RTDStatus = 2` und `RTDValue = 8500` (wird in HA als nicht verfuegbar
ausgeblendet).

Siehe [LASTENHEFT.md](../LASTENHEFT.md#43-slave-revpi-hauptkeller-spater).

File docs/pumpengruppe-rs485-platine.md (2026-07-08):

# RS485-Pumpengruppen-Platine

Stand: 2026-06-25

Entwurf fuer eine dezentrale Hutschienen-Platine je Pumpenbaugruppe mit
3-Wege-Mischer, Umwaelzpumpe, Vorlauf- und Ruecklauffuehler. Die Hauptsteuerung
gibt per Modbus RTU nur Pumpenfreigabe und Stellwert-Sollposition vor. Die
Platine berechnet daraus die noetige Mischer-Laufzeit selbst.

Wichtig: Das ist ein Entwurfs- und Layout-Lastenheft, keine fertige
Konformitaetserklaerung. 230-V-Layout, Schutzleiterfuehrung und Einbau muessen
vor Fertigung/Inbetriebnahme von einer Elektrofachkraft geprueft werden.

## Zielbild

- Ein Board pro Heiz-/Kuehlkreis: `fbh_eg`, `klima_og`, `hk_backup`, optional
  spaeter weitere Senken.
- Versorgung je Board direkt aus 230 V AC.
- ESP32 fuer Modbus-RTU-Slave, lokale Laufzeitlogik, WLAN-Konfiguration und OTA.
- Keine Anzeige am Geraet.
- Anschluss an RS485-Bus mit RJ45-Daisychain plus Schraubklemmen fuer YSTY.
- Ausgangslogik:
  - Pumpe AN/AUS
  - Mischerfreigabe AN/AUS
  - Mischerrichtung AUF/ZU ueber Umschaltrelais
- Eingangssensorik:
  - Vorlauf RTD, 2-Draht, PT100/PT1000
  - Ruecklauf RTD, 2-Draht, PT100/PT1000

## Klemmen und Steckverbinder

| Stecker | Typ | Pins | Funktion |
|---|---|---:|---|
| X1 | Schraubklemme 5,08/7,62 mm | 3 | 230 V Eingang: L, N, PE |
| X2 | Schraubklemme 5,08/7,62 mm | 3 | Pumpenausgang: L geschaltet, N, PE |
| X3 | Schraubklemme 5,08/7,62 mm | 4 | Mischer: L_AUF, L_ZU, N, PE |
| X4 | Schraubklemme 3,5 mm | 2 | RTD Vorlauf |
| X5 | Schraubklemme 3,5 mm | 2 | RTD Ruecklauf |
| J1 | RJ45 | 8 | RS485 Bus A/B/GND, parallel zu J2/J3/J4 |
| J2 | RJ45 | 8 | RS485 Bus A/B/GND, parallel zu J1/J3/J4 |
| J3 | Schraubklemme 3,5 mm | 3 | RS485 Eingang YSTY: D+, D-, GND |
| J4 | Schraubklemme 3,5 mm | 3 | RS485 Ausgang YSTY: D+, D-, GND |

RJ45-Pinout:

| RJ45 Pin | Signal |
|---:|---|
| 1 | BUS_5V |
| 2 | BUS_5V |
| 3,6 | nicht belegt |
| 4 | RS485 A / D+ |
| 5 | RS485 B / D- |
| 7 | RS485_GND / COM |
| 8 | RS485_GND / COM |

Alle vier RS485-Anschluesse liegen elektrisch parallel. Die beiden RJ45-Buchsen
sind fuer kurze Patchkabel zwischen Pumpengruppen gedacht. Die Schraubklemmen
sind fuer ankommende/weitergehende YSTY-Leitung gedacht.
BUS_5V wird ueber eine selbstrueckstellende Sicherung auf die lokale 5V-Schiene
gekoppelt. Fuer diese Hilfsversorgung muss COM mit lokaler 0V verbunden werden;
dadurch ist die RJ45-Weitergabe als gemeinsamer SELV-Bus zu betrachten.

## Bestueckungsvarianten

Es wird nur eine Leiterplatte gefertigt. Die Funktion wird ueber die
Bestueckung unterschieden:

- Vollausbau Pumpengruppe:
  - Bestueckung nach `hardware/pumpengruppe-rs485/fab/pumpengruppe-rs485-bom.csv`
  - Pick-and-Place nach
    `hardware/pumpengruppe-rs485/fab/pumpengruppe-rs485-pick-place.csv`
  - 230-V-Eingang, Netzteil, Relais, Mischer-/Pumpenausgaenge, RTD, RS485 und
    RGB-Anzeigen bestueckt.
- Temperatur-/RS485-Variante:
  - Bestueckung nach
    `hardware/pumpengruppe-rs485/fab/pumpengruppe-rs485-bom-tempinput.csv`
  - Pick-and-Place nach
    `hardware/pumpengruppe-rs485/fab/pumpengruppe-rs485-pick-place-tempinput.csv`
  - Linker 230-V-/Relaisbereich bleibt DNP: `X1`, `X2`, `X3`, `F1`, `PSU1`,
    `K1`, `K2`, `K3`, Relais-Treiber, Netz-LED und MOV werden nicht bestueckt.
  - Versorgung erfolgt ueber `BUS_5V`/RJ45 mit `F2` und gemeinsamer
    `COM`/0V-Kopplung ueber `R32`.
  - Die Ventilstand-LED-Kette `D64-D83`/`C64-C83` bleibt DNP; die vier
    Status-RGB-LEDs `D60-D63` bleiben bestueckt.

Auf der PCB ist die Breakaway-Ausfuehrung als sichtbare Bestueckungsmarkierung
und als echte Bohrperforation umgesetzt: `MB1` setzt 0,7-mm-NPTH-Mousebites in
die oberen und unteren Materialstege des vorhandenen Isolationsschlitzes. Damit
kann dieselbe Leiterplatte fuer Vollausbau und Temperatur-/RS485-Variante
produziert werden. Vor Serienfertigung sollte PCBWay die Mousebite-Geometrie
und die mechanische Reststegbreite trotzdem bestaetigen.

## Blockschaltbild

```mermaid
flowchart LR
    X1[230 V Eingang L/N/PE] --> F1[Sicherung T2A/T4A je Pumpenlast]
    F1 --> PSU[isoliertes AC/DC-Modul 5 V]
    PSU --> REG[3.3 V Regler]
    REG --> ESP[ESP32-WROOM]

    X1 --> RELP[Relais Pumpe]
    X1 --> RELM[Mischer-Freigaberelais]
    RELM --> RELD[SPDT-Richtungsrelais]
    RELP --> X2[Pumpenausgang]
    RELD --> X3[Mischer L_AUF / L_ZU]

    ESP --> DRV[Relais-Treiber + Verriegelung]
    ESP --> RTD1[MAX31865 Vorlauf]
    ESP --> RTD2[MAX31865 Ruecklauf]
    RTD1 --> X4
    RTD2 --> X5

    ESP --> ISO485[isolierter RS485-Transceiver]
    ISO485 --> BUS[RJ45 + Schraubklemmen]
```

## Empfohlene Bauteilklassen

| Funktion | Empfehlung |
|---|---|
| MCU | ESP32-WROOM-32D oder vergleichbares ESP32-Modul mit PCB-Antenne und Keepout am Platinenrand |
| 230 V -> 5 V | guenstiges zugelassenes AC/DC-Modul mit KiCad-Standardfootprint, z.B. HLK-5M05/HLK-5Mxx |
| 3.3 V | Buck/LDO mit Reserve fuer WLAN-Spitzenstrom, mindestens 600 mA Peak |
| RS485 | guenstige Standard-Transceiverklasse MAX3485/SP3485/SN65HVD im SOIC-8; DE/RE ueber ESP-GPIO `RS485_DE` |
| RTD | 2x MAX31865 oder gleichwertig, je Kanal eigener Praezisionsreferenzwiderstand |

Aktuelle UART-Zuordnung im KiCad-Schaltplan:

- USB-C/CP2102N ist nur Service/Flash: `ESP_U0RX`/`ESP_U0TX` auf ESP-UART0.
- RS485/MAX3485 ist getrennt: `RS485_UART_RX` auf ESP GPIO16,
  `RS485_UART_TX` auf ESP GPIO17, `RS485_DE` auf ESP GPIO4.
- Das PCB muss nach dieser Schaltplan-Korrektur in KiCad aus dem Schaltplan
  aktualisiert und die alten `UART_RX`/`UART_TX`-Routen muessen ersetzt werden.

RTD-Anbindung: Die zwei MAX31865 haben getrennte Chip-Select-Leitungen:
`RTD_VL_CS` auf ESP GPIO5 und `RTD_RL_CS` auf ESP GPIO22. Der ESP32-EN-Pin
ist ueber `R33` als 10-kOhm-Pullup an `+3V3` angebunden.
| Relais | 1x Pumpenrelais, 1x Mischerfreigabe, 1x Mischer-SPDT-Richtung; 250 V AC passend zur Last/Inrush |
| Relais-Treiber | Diskret mit AO3400A-kompatiblem NMOS, 100R Gate, 100k Pulldown, SS14 Freilauf; guenstige Standardteile |
| Eingangsschutz RTD | Serienwiderstand, RC-Filter, ESD/Surge nach Leitungslage |
| Bus-Schutz | diskret mit Standard-TVS/Serienwiderstaenden nach Leitungslage; keine teuren Sondermodule |

PT1000 ist fuer 2-Draht-Fuehler bevorzugt, weil Leitungswiderstand weniger stark
ins Messergebnis eingeht. PT100 wird unterstuetzt, sollte aber als
Konfigurationsvariante mit Offset-Kalibrierung behandelt werden.

## 230-V-Ausgaenge

Die Platine schaltet nur die Phase:

- Pumpenausgang X2:
  - `L_Pumpe` ueber Relais K1
  - `N` durchverbunden
  - `PE` durchverbunden
- Mischerausgang X3:
  - K2 schaltet `L_FUSED` auf `MIX_L_EN`
  - K3 ist ein SPDT-Umschaltrelais: gemeinsamer Kontakt `MIX_L_EN`,
    NC = `L_ZU`, NO = `L_AUF`
  - `N` durchverbunden
  - `PE` durchverbunden

K2/K3 bilden damit eine echte Hardware-Verriegelung: Ohne K2 liegt am Mischer
gar keine Phase an; K3 kann elektrisch nur eine Richtung verbinden. AUF und ZU
koennen durch diese Kontaktlogik nicht gleichzeitig gespeist werden.

Zusaetzliche Logik:

- Software-Interlock bleibt trotzdem aktiv und schaltet vor Richtungswechsel
  immer erst K2 aus.
- Umschaltpause zwischen AUF/ZU mindestens 500 ms.

Netzseitig ist ein diskreter MOV 275 VAC zwischen L/N vorzusehen. Empfohlen:
RC-Snubber oder MOV je induktiver Last nach konkreter Pumpen- und
Stellantriebs-Spezifikation. Fuer Pumpen mit hoher Einschaltspitze Relais nicht
nach Nennstrom allein auswaehlen, sondern nach Inrush-/Motorlast-Datenblatt.

Die 230-V-Kontrollanzeige bleibt vollstaendig auf der Netzseite: zwei
hochohmige 1206-Serienwiderstaende, LED und antiparallele Schutzdiode. Keine
LED-Leitung darf in den SELV-Bereich laufen.

## Leiterplatte und Sicherheitsabstaende

Auslegung fuer 230 V AC, Schaltschrank-/Gebaeudetechnik, Verschmutzungsgrad 2.
Wenn das Board in einer Umgebung nach Ueberspannungskategorie III bewertet wird,
sind die strengeren Werte anzusetzen.

Layout-Ziele:

- Mindestens 8 mm Abstand/Kriechstrecke zwischen primaerer 230-V-Seite und SELV
  inklusive ESP32, RS485, RTD und USB/UART-Servicepunkten.
- Fraesnut oder breite Keepout-Zone zwischen 230-V- und SELV-Seite, besonders
  am AC/DC-Modul, Relaiskontaktbereich und unter Steckverbindern.
- Mindestens 3 mm Abstand zwischen 230-V-Leitern unterschiedlicher Potentiale
  auf der Lastseite; bei Netz-Eingang/ungefilterter Seite konservativ groesser.
- PE nicht als duenne Leiterbahn durch das Board fuehren. Bevorzugt:
  grossflaechige, kurze PE-Fuehrung mit ausreichender Kupferbreite oder
  externe PE-Brueckung/Klemmenblock im Gehaeuse.
- Keine SELV-Leitung unter Relaiskontakten, Netzsicherung, MOVs oder
  230-V-Klemmen hindurch.
- Silkscreen-Zonierung: `230 V` und `SELV` klar markieren.
- Testpunkte fuer 230 V nur beruehrgeschuetzt oder ganz weglassen.
- Leiterbahnbreite fuer Pumpenphase nach realem Strom, Kupferdicke und
  Temperaturhub dimensionieren. Die RevA-Datei ist auf 1,5 mm 230-V-Lastbahnen
  gesetzt; fuer eine 5-A-Sicherung sollte PCBWay mindestens mit 70 um / 2 oz
  Kupfer angefragt werden oder die Sicherung/Last kleiner dimensioniert werden.
  Lokale Engstellen an Relais-/Klemmenpads kurz halten.
- KiCad-Netclasses im Projekt:
  - `230V`: `L_IN`, `L_FUSED`, `L_PUMP`, `MIX_L_EN`, `L_OPEN`, `L_CLOSE`,
    `N`, `PE`; Routingbreite 1,5 mm, Clearance 0,8 mm innerhalb der
    230-V-Netze.
  - `Default`: SELV/Signale; Routingbreite 0,2 mm, projektweite
    Mindestbreite 0,2 mm.
  - `SELV_POWER_0V8`: `+5V`, `BUS_5V`, `USB_VBUS`, `GND`, `RS485_GND`;
    Routingbreite 0,8 mm fuer neue Versorgungsrouten.
  - `Doppelte Dicke`: `+3V3`; Routingbreite 0,4 mm.
  - Auf der RGB-/Temp-Input-Seite sind erste vorhandene 5-V-/GND-Segmente real
    auf 0,8 mm und 3V3-Segmente auf 0,4 mm verbreitert. USB- und RJ45-Engstellen
    bleiben bewusst schmal, weil eine globale Track-Verbreiterung dort
    DRC-Kurzschluesse erzeugt. Diese Netze muessen fuer eine belastbare
    Serienversion weiter gezielt mit breiten Versorgungsstaemmen bzw.
    Kupferflaechen nachgezogen werden.
  - `SELV_SIGNAL`: ESP-, SPI-, UART-, USB-CC/Daten-, LED- und RTD-Signale;
    Routingbreite 0,25 mm.
- Die Netclass-Clearances sind bauteilkompatible CAD-Mindestwerte. Die
  sicherheitsrelevante Trennung 230 V zu SELV wird nicht durch diese Werte
  ersetzt, sondern muss ueber die 8-mm-Zonierung/Fraesnut und DRC-/Sichtpruefung
  eingehalten werden.
- Sicherung vor den Relaiskontakten vorsehen; Wert nach Leitungsschutz,
  Klemmenrating und Pumpenlast festlegen.
- DRC-Regeln im CAD getrennt fuer Netze `MAINS_L/N`, `MAINS_SW`, `PE`, `SELV`,
  `RS485_ISO` anlegen.

Vor Fertigung zu pruefen:

- EN 60664-1 fuer Isolationskoordination/Kriechstrecken.
- DIN EN 60730-1, falls die Baugruppe als automatische elektrische Regel- und
  Steuergeraete-Baugruppe bewertet wird.
- DIN VDE 0100 / Schaltschranknormen fuer Einbau, Absicherung, PE und
  Leitungsquerschnitte.
- EMV-Anforderungen, insbesondere lange RS485-/RTD-Leitungen und Relaislasten.

## Firmware-Funktionen

Die Platine ist ein Modbus-RTU-Slave. WLAN wird nur fuer Konfiguration,
Diagnose und OTA genutzt, nicht fuer den regulaeren Regelbetrieb.

Pflichtfunktionen:

- Slave-Adresse, Baudrate, Paritaet, Mischerlaufzeit und Sensortyp per WLAN
  konfigurierbar.
- OTA-Update per WLAN, abgesichert mit Passwort/Token.
- Watchdog: bei Modbus-Kommunikationsausfall Pumpe aus nach Timeout; Mischer
  bleibt stehen.
- Lokale Relaislogik laeuft auch bei WLAN-Ausfall weiter.
- Aktuelle Mischerposition wird in NVS/Flash persistiert, aber mit begrenzter
  Schreibfrequenz.
- Kalibrierfahrt konfigurierbar:
  - `close_to_zero`: ZU fuer Laufzeit + Ueberlauf, Position = 0 %.
  - `open_to_hundred`: AUF fuer Laufzeit + Ueberlauf, Position = 100 %.
  - `none`: letzte gespeicherte Position verwenden.
- Endlagen-Rekalibrierung: bei Sollwert 0 % oder 100 % darf mit kleinem
  Ueberlauf gefahren werden, um Laufzeitfehler zu korrigieren.
- Temperatur-Plausibilitaet: z.B. -20..95 C fuer Heizkreise.

Stellweg-Berechnung:

```text
delta_pct = ziel_pct - position_pct
laufzeit_s = abs(delta_pct) / 100 * kalibrierte_gesamtlaufzeit_s
richtung = AUF wenn delta_pct > 0, sonst ZU
```

Waehrend der Fahrt wird die interne Position ueber die vergangene Zeit
integriert. Nach Ablauf wird das Relais abgeschaltet und die erreichte Position
als Istwert gemeldet.

## Modbus-Registervorschlag

Alle Prozentwerte werden mit Faktor 10 uebertragen: 56,0 % = `560`.
Temperaturen werden mit Faktor 10 uebertragen: 34,5 C = `345`.

Holding Register, Master -> Board:

| Adresse | Name | Einheit | Beschreibung |
|---:|---|---|---|
| 0 | `command_seq` | - | Wird bei neuem Befehl erhoeht |
| 1 | `pump_enable` | 0/1 | Pumpe aus/an |
| 2 | `mixer_target_pct_x10` | 0..1000 | Zielposition |
| 3 | `mode` | enum | 0 auto, 1 hand, 2 kalibrieren_zu, 3 kalibrieren_auf |
| 4 | `watchdog_timeout_s` | s | Default 60 |
| 5 | `mixer_runtime_s` | s | Kalibrierte 0..100-%-Laufzeit |
| 6 | `endstop_overrun_s` | s | Zusatzlauf an Endlage |
| 7 | `rtd_type` | enum | 0 PT1000, 1 PT100 |
| 8 | `failsafe_pump` | 0/1 | Pumpenzustand bei Busausfall, Default 0 |

Input Register, Board -> Master:

| Adresse | Name | Einheit | Beschreibung |
|---:|---|---|---|
| 0 | `status_bits` | bitfield | online, fault, moving, pump_on, open_on, close_on |
| 1 | `mixer_position_pct_x10` | 0..1000 | geschaetzte Istposition |
| 2 | `vl_temp_c_x10` | C | Vorlauf |
| 3 | `rl_temp_c_x10` | C | Ruecklauf |
| 4 | `last_command_seq` | - | zuletzt uebernommener Befehl |
| 5 | `fault_code` | enum | 0 ok, siehe Fehlerliste |
| 6 | `uptime_s_lo` | s | Uptime low word |
| 7 | `uptime_s_hi` | s | Uptime high word |
| 8 | `fw_version` | BCD | z.B. 0x0100 |

Fehlercodes:

| Code | Bedeutung | Reaktion |
|---:|---|---|
| 0 | ok | normal |
| 1 | Modbus-Watchdog abgelaufen | Pumpe nach Timeout aus, Mischer stop |
| 2 | VL-Fuehler unplausibel/defekt | Fehler melden, Regelung Master entscheidet |
| 3 | RL-Fuehler unplausibel/defekt | Fehler melden, Regelung Master entscheidet |
| 4 | beide Mischerrelais angefordert | beide aus, fault |
| 5 | Kalibrierung fehlt | Mischerbefehle optional sperren |
| 6 | Relais-/Treiberdiagnose fehlerhaft | alle Ausgaenge aus |

## Adressierung und Bus

Vorgeschlagene Slave-IDs:

| Slave-ID | Kreis |
|---:|---|
| 30 | FBH EG Pumpengruppe |
| 31 | Klima OG Pumpengruppe |
| 32 | HK-Backup OG Pumpengruppe |
| 33 | Gewaechshaus-Lufterhitzer, optional, VL-Soll ca. 35 Grad |
| 34..39 | Reserve |

Busparameter Startwert: 19200 8E1 oder 9600 8N1. Fuer maximale Robustheit mit
langen YSTY-Strecken ist 9600 8N1 unkritischer; final muss die Hauptsteuerung
einheitlich konfiguriert werden.

Hardware:

- 120-Ohm-Abschluss per Jumper/DIP nur am letzten Busgeraet.
- Umsetzung im KiCad-Entwurf: `R3 = 120R` plus `JP1 RS485_TERM_ON_PARK`.
  `JP1` ist als 1x3-Header ausgelegt: Jumper auf `1-2` = Abschluss zwischen
  D+ und D-, Jumper auf `2-3` = Parkposition/Aus, damit die Bruecke nicht
  verloren geht.
- `U4` ist kein teures isoliertes RS485-Modul mehr, sondern ein SOIC-8
  Standardtransceiver. Dadurch ist `COM`/0V als gemeinsamer SELV-Bus zu planen.
- RJ45 Pin 1/2 kann 5 V zwischen Pumpengruppen weiterreichen. Die lokale
  Einspeisung ist ueber PTC geschuetzt; die 0V-Verbindung muss fuer diese
  Betriebsart bestueckt sein.
- Bias-Widerstaende nur einmal pro Bus aktivieren, bevorzugt am Master/Gateway.
- RJ45 und Schraubklemmen duerfen nicht als Stern verdrahtet werden; sie sind
  nur mechanische Alternativen fuer dieselbe Linien-Topologie.

## Mechanik

- Hutschienen-Gehaeuse, z.B. 4 TE bis 6 TE je nach Klemmen- und Relaisgroesse.
- 230-V-Klemmen auf einer Seite, SELV/RS485/RTD auf der anderen Seite.
- ESP32-Antenne weg von Relais, Netzteil, PE-Flachen und Schaltschrankwand.
- Beschriftung je Klemme direkt auf Front/Deckel: `L N PE`, `Pumpe`, `AUF ZU N PE`,
  `VL`, `RL`, `RS485`.
- Service-Taste fuer WLAN-Konfigurationsmodus und Status-LED im SELV-Bereich
  sind sinnvoll, aber kein Display erforderlich.
- 24 adressierbare 5-V-RGB-LEDs `D60-D83` (einheitlich SK6812MINI/3535, WS2812-kompatibles Datenprotokoll) an ESP32
  GPIO21 (`RGB_DATA`), mit `R60=330R` Dateneingangswiderstand und je LED 100nF
  Pufferkondensator `C60-C83`.
  `D60-D63` sind freie Status-LEDs; `D64-D83` bilden eine senkrechte
  Ventilstandanzeige mit einer LED je 5 %.
- USB-C-Serviceanschluss auf SELV-Seite fuer Firmware/Debug, mechanisch an der
  Platinenkante mit Steckrichtung nach aussen. Bei klassischem
  ESP32-WROOM ist dafuer ein USB-UART-Baustein noetig; D+/D- duerfen nicht
  direkt an den ESP32-WROOM gehen.
- ESP32-WROOM-32D so platzieren, dass die PCB-Antenne am Platinenrand sitzt
  und der Antennen-Keepout nicht durch Kupfer, Bauteile oder Gehaeuse verdeckt wird.

## Offene Entscheidungen vor KiCad

- Pumpenleistung und Einschaltstrom der konkreten Pumpenbaugruppen.
- Laufzeit der konkreten 3WV-Stellantriebe von 0..100 %.
- PT100 oder PT1000 final; Empfehlung: PT1000.
- Ob der Mischer-Stellantrieb wirklich 230 V AUF/ZU mit gemeinsamem N ist.
- Gehaeusebreite und bevorzugte Klemmenserie.
- Konkreter USB-UART-Baustein und Auto-Boot-Schaltung fuer ESP32-Flashing.

## Quellen und Pruefhinweise

- IEC 60664-1:2020 ist die Basis fuer Isolationskoordination an Geraeten bis
  AC 1000 V / DC 1500 V und fuer die Bestimmung von Luft- und Kriechstrecken.
- IEC 60730-1:2022 beschreibt Anforderungen an Konstruktion, Betrieb und Test
  automatischer elektrischer Steuergeraete.
- IPC-2221B ist der generische Leiterplatten-Designstandard und Grundlage fuer
  Leiterbahn-/Abstands- und Fertigungsregeln; konkrete Stromtragfaehigkeit muss
  mit Kupferdicke, Temperaturhub und Leiterplattenhersteller abgestimmt werden.
- Vereinfachte Online-Rechner fuer Leiterbahnbreite sind nur Vorab-Schaetzung,
  keine finale Sicherheitsvalidierung.

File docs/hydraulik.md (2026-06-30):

# Hydraulik-Schema (Endausbau)

Grundprinzip: **WP1 und WP2 speisen beide denselben Gesamtwaermekreis**.
Haus, Nebengebaeude, Pool, HK-Backup und optional das Gewaechshaus sind Senken
an diesem gemeinsamen Erzeuger-/Verteilerkreis. Es gibt keine feste Zuordnung
"WP1 = Haus" oder "WP2 = Pool"; jede aktive Waermequelle kann jede aktive Senke
bedienen.

```mermaid
flowchart LR
    subgraph HR[Heizungsraum]
        WP1[WP1 16 kW Monoblock]
        WP2[WP2 16 kW Monoblock]
        BWWP[Brauchwasser-WP<br/>200 L]
        SVW1[WP1-Kreisventil<br/>in Sammelvorlauf]
        SVW2[WP2-Kreisventil<br/>in Sammelvorlauf]
        VL[Sammelvorlauf<br/>Gesamtwaermekreis]
        RL[Sammelruecklauf<br/>Gesamtwaermekreis]
        BR[Brunnenpumpe]
        WTK[WT Brunnen-Kuehlung]
        SVP[Pool-Kreisventil]
        PPool[Pumpe Pool-Kreis]
        PWT[Pool-Waermetauscher]
        SVN[Nebengebaeude-Kreisventil]
        PNeb[Pumpe Nebengebaeude]
        SVH[HK-Backup-Kreisventil OG]
        SVG[Gewaechshaus-Kreisventil]
        PGew[Pumpe Gewaechshaus-Kreis]
        BWS[Trinkwarmwasser-<br/>Speicher 200 L]
    end

    subgraph HK[Hauptkeller]
        SVF[3WV Mischer FBH]
        PF[Pumpe FBH-EG]
        SVK[3WV Mischer Klima-OG]
        PK[Pumpe Klimakreis-OG]
    end

    subgraph EG[Erdgeschoss]
        FBH[Fussbodenheizung<br/>+ Shelly-Ventile]
    end

    subgraph OG[Obergeschoss]
        K1[Klima Kind]
        K2[Klima Buero]
        K3[Klima Schlaf]
        K4[Klima Bad]
        K5[Klima Flur]
        HKB[Heizkoerper-Backup OG]
    end

    subgraph POOL[Pool]
        BEC[Pool 30 m3<br/>35 Grad ganzjaehrig]
    end

    subgraph NEB[Nebengebaeude]
        NHK[Heizkreis Nebengebaeude]
    end

    subgraph GEW[Gewaechshaus]
        GLH[Lufterhitzer<br/>VL ca. 35 Grad]
    end

    WP1 --> SVW1 --> VL
    WP2 --> SVW2 --> VL
    VL --> SVF --> PF --> FBH --> RL
    VL --> SVK --> PK --> K1 & K2 & K3 & K4 & K5 --> RL
    VL --> SVN --> PNeb --> NHK --> RL
    VL --> SVH --> HKB --> RL
    VL --> SVG --> PGew --> GLH --> RL
    VL --> SVP --> PPool --> PWT --> BEC --> RL
    BWWP --> BWS
    BR --> WTK --> SVK
```

## Regelungsprinzip

- **Gesamtwaermekreis**: Alle normalen Heiz-/Pool-Anforderungen werden gesammelt.
  Der hoechste geforderte Vorlauf plus Mischerreserve ergibt den WP-Sollwert.
- **WP1/WP2**: Beide WPs bekommen denselben Sollwert fuer den Sammelvorlauf.
  Bei kleiner Last laeuft eine WP, bei mehreren aktiven Senken oder hoher Last
  laufen beide parallel. Laufzeitrotation wird separat gepflegt.
- **Pool**: Der Pool ist eine Senke am Gesamtwaermekreis. Er wird ueber sein
  Kreisventil und die Pool-Kreis-Pumpe zugeschaltet, nicht ueber eine exklusiv
  zugeordnete Waermepumpe.
- **Nebengebaeude / Haus / HK-Backup / Gewaechshaus**: Ebenfalls Senken am
  gemeinsamen Kreis. Das Gewaechshaus ist als Niedertemperatur-Senke mit ca.
  35 Grad Vorlauf geplant und passt damit gut zum WP-Betrieb.
- **BWWP**: Die Brauchwasser-WP bleibt ein separater kleiner Steuerkreis fuer den
  Trinkwarmwasserspeicher.
- **Brunnen-WT**: Eigener Kuehlpfad in den Klimakreis, getrennt von der
  Waermeerzeugerlogik.

## Wichtige Konsequenz

Software, HA-Visualisierung und Beschriftung muessen immer von Quellen und
Senken sprechen:

- Quellen: `wp1`, `wp2`, spaeter ggf. `oelbrenner`
- Gemeinsamer Knoten: `gesamtwaermekreis`
- Senken: `fbh_eg`, `klima_og`, `nebengeb`, `hk_backup`, `pool`,
  `gewaechshaus`

Damit bleibt die Anlage routingfaehig: **alles kann auf alles geroutet werden**,
solange Ventilstellung, Pumpenfreigabe und Solltemperatur dazu passen.

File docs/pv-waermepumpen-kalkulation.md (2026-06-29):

# PV- und Waermepumpen-Kalkulation

Stand: 2026-06-29

Diese Datei fasst die von dir als Screenshot gelieferte Grobkalkulation
zusammen und markiert die Punkte, die fuer eine belastbare Planung noch fehlen.
Das Angebot des Elektrikers enthaelt laut aktuellem Stand die PV-Module und das
Untergestell fuer 65x 455 Wp, also 29,575 kWp, plus einen Zaehlerschrank.

Quelle der Kostenpositionen: Screenshot der bisherigen Kalkulation vom
2026-06-27. Die folgenden Tabellen sind aus diesem Bild uebernommen und nur
formal bereinigt.

Link-Regel fuer diese Datei: Jede Kaufposition bekommt einen konkreten
Artikel-, Hersteller- oder Angebotslink mit Preisstand. Reine Suchlinks werden
nicht als Position gefuehrt. Wenn eine Position noch nicht konkret genug ist,
wird sie in kleinere, bestellbare Einzelartikel aufgeloest.

## Zielbild

- PV-Anlage: 29,575 kWp aus dem GSB-Angebot, optional erweiterbar ueber
  PV-Zaun und weitere Flaechen.
- Batteriespeicher: Grundausstattung 8x 16s, ca. 128,6 kWh LiFePO4,
  Erweiterung mechanisch und elektrisch vorbereitet bis 16x 16s,
  ca. 257,2 kWh nominal.
- Wechselrichter-/ESS-Konzept: Victron-basiert mit 6x MultiPlus-II 48/8000,
  3-phasig, je Phase 2 Geraete parallel.
- Waermeerzeugung: 2 Waermepumpen mit je ca. 18 kW plus separate
  Warmwasser-Waermepumpe.
- Steuerung: PV-Ueberschuss und PV-Mangel werden in Home Assistant gebildet und
  per MQTT an die Heizungssteuerung uebergeben.

## Kostenuebersicht

### PV, Speicher und Elektro

| Position | Link / Quelle | Anschluesse / Bemerkung | Anzahl | Einzelpreis | Gesamt |
|---|---|---:|---:|---:|---:|
| Victron VM-3P75CT optionaler Kontroll-/Unterzaehler | https://www.victronenergy.com/meters-and-sensors/energy-meter | Nicht fuer ESS-Regelung noetig, wenn wirklich alle Lasten und AC-PV auf AC-out liegen | 0 | 120,59 EUR | 0,00 EUR |
| Lynx Distributor | https://www.victronenergy.com/dc-distribution-systems/lynx-distributor | 4 | 3 | 141,95 EUR | 425,85 EUR |
| MPPT RS 450/200 MC4 | https://www.victronenergy.com/solar-charge-controllers/smartsolar-mppt-rs-450-tr | 4 | 3 | 1.365,95 EUR | 4.097,85 EUR |
| MultiPlus-II 48/6k5/100-50 | https://www.victronenergy.com/inverters-chargers/multiplus-ii | 2 | 3 | 649,00 EUR | 1.947,00 EUR |
| Ekrano GX | https://www.victronenergy.com/communication-centres/ekrano-gx | 1 | 1 | 397,95 EUR | 397,95 EUR |
| Victron MEGA-fuse 300A/58V, Set 5 Stk. | https://www.offgridtec.com/en/victron-300a-80v-mega-fuse-fuse-set-of-5.html | 5 Stk./Pack, 48-V-tauglicher Ersatz fuer alte 500-A-Position | 3 | 38,44 EUR | 115,32 EUR |
| Batteriespeichergehaeuse | siehe Einkaufskandidaten unten, Startlink: https://www.alibaba.com/product-detail/PL-Stock-DIY-15kWh-Solar-Storage_1601636254158.html | 16 | 6 | 86,91 EUR | 521,46 EUR |
| EVE MB31 Batteriezelle 314 Ah | https://www.alibaba.com/product-detail/8000-Cycles-V3-EU-Stock-3_1601244515922.html | 1 | 99 | 48,28 EUR | 4.779,72 EUR |
| Kleinmaterial DC-Verkabelung | Detailpositionen siehe DC-Verteilung/Kleinmaterial: H07V-K, Rohrkabelschuhe, Schrumpfschlauch, Beschriftung, Potentialausgleich | pauschal | 1 | 500,00 EUR | 500,00 EUR |
| Kleinmaterial AC-Verkabelung | Startpaket aus Artikelregister: NYM-J/NYY-J 5x10/5x16, Hager SLS/RCD, Verteilerzubehoer; Mengen nach AC-Schema | pauschal | 1 | 1.000,00 EUR | 1.000,00 EUR |
| Angebot GSB ANG-2026-19, PV-Material + Zaehlerschrank | lokale Quelle: `C:/Users/Danie/Downloads/Angebot-GSB-ANG-2026-19-Eschenlohre-28-03-2026.pdf` | 29,575 kWp + Schrank | 1 | 14.202,94 EUR | 14.202,94 EUR |
| **Zwischensumme PV/Speicher/Elektro** |  |  |  |  | **27.988,09 EUR** |

### Waermepumpen und Heizung

| Position | Link / Quelle | Anzahl | Einzelpreis | Gesamt |
|---|---|---:|---:|---:|
| Sunex NEXUS M18 EVI 18 kW Monoblock | https://preisvergleich.heise.de/sunex-nexus-m18-evi-420-000-518-a3338154.html | 2 | 2.599,99 EUR | 5.199,98 EUR |
| Warmwasser-Waermepumpe AEG WPT 300 EL, 300 l | https://www.hornbach.de/p/warmwasser-waermepumpe-aeg-300-l-wpt-300-el/6668689/ | 1 | 2.099,00 EUR | 2.099,00 EUR |
| Kleinmaterial Heizung | Startpaket aus Artikelregister/Heizungsplanung: Pumpengruppen, Mischer, Rohr/Fittinge, Sicherheitsgruppe, Magnetitabscheider, Daemmung | 1 | 1.500,00 EUR | 1.500,00 EUR |
| **Zwischensumme Waerme/Heizung** |  |  |  | **8.798,98 EUR** |

**Grobe Gesamtsumme bisher:** 36.787,07 EUR

## Elektrikerangebot GSB ANG-2026-19

Quelle: Angebot `GSB ANG-2026-19` vom 2026-03-28 fuer BV Parkstrasse 5,
19309 Lanz. Das Angebot erklaert die Position aus der Ursprungskalkulation
ueber 14.202,94 EUR.

| Pos. | Inhalt | Betrag |
|---|---|---:|
| 001 | PV-Anlage 29,575 kWp: Module mit Schienensystem, Stringverkabelung, PV-Stecker und Kupplungen liefern; 65x PV-Modul 455 Wp; Schienensysteme fuer 5 Daecher: Sueddach Scheune, 2x Gaube Sued, Ostdach Wohnhaus, Westdach Wohnhaus; Befestigung mit Dachhaken, Schienensystem 1-lagig | 12.764,11 EUR |
| 002 | Wandschrank 7-reihig 800x1100 BxH, SKII IP44, Zaehlerschrank; 3-feldrig mit einem Zaehlplatz, APZ/Verteilerfelder, SLS 63 A 3-polig, SPD Typ 1+2+3, Hauptschalter 63 A | 1.209,10 EUR netto / 1.438,83 EUR brutto |
| Summe | Nettobetrag 13.973,21 EUR, 0 % MwSt. auf PV-Anteil, 19 % MwSt. 229,73 EUR auf steuerpflichtigen Anteil | 14.202,94 EUR |

Rechenwerte:

- 65 x 455 Wp = 29,575 kWp.
- PV-Materialposition: ca. 431,58 EUR/kWp.
- Gesamtangebot inkl. Zaehlerschrank: ca. 480,23 EUR/kWp.
- Anzahlung laut Angebot: 2.840,59 EUR.

Abgrenzung / offene Punkte:

- Der Wortlaut nennt bei der PV-Position ausdruecklich "liefern". Montage,
  Geruest/Steiger, AC-Anschluss, Anmeldung, Inbetriebnahme, Pruefprotokoll und
  finaler Stringplan sind im Angebot nicht eindeutig als enthalten erkennbar.
- Das Angebot enthaelt keine Wechselrichter, keinen Speicher, keine MPPTs,
  keine Victron-Komponenten und keine Notstrom-/AC-out-Rueckleitung.
- Die angebotenen Dachflaechen sind: Scheune Sued, zwei Sued-Gauben,
  Wohnhaus Ost und Wohnhaus West.

## Recherche und Annahmen 2026-06-27

Fuer USD-Positionen wurde der EZB-Referenzkurs vom 2026-06-26 verwendet:
1 EUR = 1,1401 USD. USD-Preise sind damit nur Planwerte, weil Alibaba-Preise
fuer Versand, DDP, Zoll, Umsatzsteuer, Zertifikate und Mengenstaffeln final
immer angefragt werden muessen.

Wichtige Quellen:

- Victron MultiPlus-II technische Daten:
  https://www.victronenergy.com/media/pg/MultiPlus-II_230V/en/technical-specifications-mp-ii-230v.html
- Victron MultiPlus-II Installationshandbuch, DC-Sicherungen und Kabel:
  https://www.victronenergy.com/upload/documents/MultiPlus-II_230V/32424-MultiPlus-II___Quattro-II-pdf-en.pdf
- Victron MPPT RS 450/200 technische Daten:
  https://www.victronenergy.com/media/pg/SmartSolar_MPPT_RS/en/technical-specifications.html
- Victron ESS Konfiguration / Grid Setpoint:
  https://www.victronenergy.com/media/pg/Energy_Storage_System/en/configuration.html
- EZB USD/EUR Referenzkurs:
  https://www.ecb.europa.eu/stats/policy_and_exchange_rates/euro_reference_exchange_rates/html/eurofxref-graph-usd.en.html
- Polestar 4 AC-Laden bis 22 kW mit passender Option:
  https://www.polestar.com/en-ae/polestar-4/range-and-charging/
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

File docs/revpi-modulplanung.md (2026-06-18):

# RevPi-Modulplanung

Stand: 2026-06-16

## Bestand

| Typ | Anzahl | Kapazitaet je Modul | Gesamt |
|---|---:|---|---|
| CPU RevPi Connect 4 | 4 | max. 10 Erweiterungsmodule je CPU | 4 Steuerungen moeglich |
| DIO | 3 | 14 DI + 14 DO | 42 DI + 42 DO |
| DI | 17 | 16 DI | 272 DI |
| AIO | 11 | 4 AI + 2 RTD + 2 AO | 44 AI + 22 RTD + 22 AO |
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

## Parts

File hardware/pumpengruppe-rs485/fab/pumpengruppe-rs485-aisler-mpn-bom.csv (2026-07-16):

Refs | Value | Footprint | Qty | DNP | Manufacturer | MPN | AISLER_MPN | Supplier | AssemblyNote
C22,C23 | 10nF 50V | Capacitor_SMD:C_0603_1608Metric | 2 |  | Murata | GRM188R71H103KA01D | GRM188R71H103KA01D | AISLER source or equivalent
C60-C83 | 100nF 16V | Capacitor_SMD:C_0603_1608Metric | 24 |  | Murata | GRM188R71C104KA01D | GRM188R71C104KA01D | AISLER source or equivalent
D1-D4 | B5819W | Diode_SMD:D_SOD-123 | 4 |  | Jiangsu Changjing Electronics | B5819W | B5819W | AISLER source or equivalent | SOD-123 Schottky, SS14 class
D10-D12,D20,D21,D30,D31 | LED green 0603 | LED_SMD:LED_0603_1608Metric | 7 |  | Wurth Elektronik | 150060GS75000 | 150060GS75000 | AISLER source or equivalent
D40 | LED green 0805 | LED_SMD:LED_0805_2012Metric | 1 |  | Wurth Elektronik | 150080GS75000 | 150080GS75000 | AISLER source or equivalent | 230VAC indicator, mains side
D41 | 1N4148W | Diode_SMD:D_SOD-123 | 1 |  | Diodes Incorporated | 1N4148W-7-F | 1N4148W-7-F | AISLER source or equivalent
D60-D83 | SK6812MINI-E | LED_SMD:LED_SK6812MINI_PLCC4_3.5x3.5mm_P1.75mm | 24 |  | OPSCO Optoelectronics | SK6812MINI-E | SK6812MINI-E | AISLER source or equivalent
F1 | 2x FC-203-22 fuse clips for 5x20 | Fuse:Fuseholder_Clip-5x20mm_Bel_FC-203-22_Lateral_P17.80x5.00mm_D1.17mm_Horizontal | 1 |  | Bel Fuse | FC-203-22 | FC-203-22 | LCSC C3205463 / PCBWay equivalent | Populate two FC-203-22 clips per F1 footprint for one 5x20mm fuse; do not use one-piece expensive fuse holder
F2 | PTC 1.1A 1812 | Fuse:Fuse_1812_4532Metric | 1 |  | Bourns | MF-MSMF110-2 | MF-MSMF110-2 | AISLER source or equivalent
J1,J2 | RJ45 8P8C horizontal | Connector_RJ:RJ45_Amphenol_54602-x08_Horizontal | 2 |  | Amphenol ICC | 54602-908LF | 54602-908LF | AISLER source or equivalent
J3,J4 | KF128L-3.5-3P | FW_Pumpengruppe:TB_KF128L_350_3P | 2 |  | Cixi Kefa Elec | KF128L-3.5-3P | KF128L-3.5-3P | AISLER source or equivalent,LCSC C474931 / PCBWay equivalent
J5 | EXT_GPIO_HEADER | Connector_PinHeader_2.54mm:PinHeader_2x10_P2.54mm_Vertical | 1 |  | XFCN | PZ254V-22-10-A60-2500 |  | LCSC C49056273 | Optional 2x10 2.54mm expansion header; can be DNP if not needed
JP1 | 1x3 2.54mm header | Connector_PinHeader_2.54mm:PinHeader_1x03_P2.54mm_Vertical | 1 |  | Samtec | TSW-103-07-G-S | TSW-103-07-G-S | AISLER source or equivalent | Use with 2.54mm jumper shunt, park position included
K1-K3 | SRD-05VDC-SL-C | Relay_THT:Relay_SPDT_SANYOU_SRD_Series_Form_C | 3 |  | Songle Relay | SRD-05VDC-SL-C | SRD-05VDC-SL-C | LCSC C35449 / PCBWay equivalent | Costdown SRD Form-C relay; K1/K2 NC contact intentionally unused
PSU1 | HLK-5M05 | Converter_ACDC:Converter_ACDC_Hi-Link_HLK-5Mxx | 1 |  | Hi-Link | HLK-5M05 | HLK-5M05 | AISLER / approved distributor | 5W AC/DC module; re-route mains and SELV clearances after footprint change
Q1-Q3 | AO3400A | Package_TO_SOT_SMD:SOT-23 | 3 |  | Alpha & Omega Semiconductor | AO3400A | AO3400A | AISLER source or equivalent
R1,R2 | 5.1k 1% 0603 | Resistor_SMD:R_0603_1608Metric | 2 |  | Yageo | RC0603FR-075K1L | RC0603FR-075K1L | AISLER source or equivalent
R4-R6 | 100R 1% 0603 | Resistor_SMD:R_0603_1608Metric | 3 |  | Yageo | RC0603FR-07100RL | RC0603FR-07100RL | AISLER source or equivalent
R7-R9 | 100k 1% 0603 | Resistor_SMD:R_0603_1608Metric | 3 |  | Yageo | RC0603FR-07100KL | RC0603FR-07100KL | AISLER source or equivalent
R10-R12,R20 | 2.2k 1% 0603 | Resistor_SMD:R_0603_1608Metric | 4 |  | Yageo | RC0603FR-072K2L | RC0603FR-072K2L | AISLER source or equivalent
R21 | 1.5k 1% 0603 | Resistor_SMD:R_0603_1608Metric | 1 |  | Yageo | RC0603FR-071K5L | RC0603FR-071K5L | AISLER source or equivalent
R22,R23 | 4.3k 0.1% 0603 | Resistor_SMD:R_0603_1608Metric | 2 |  | Yageo | RT0603BRD074K3L | RT0603BRD074K3L | AISLER source or equivalent
R30,R31 | 4.7k 1% 0603 | Resistor_SMD:R_0603_1608Metric | 2 |  | Yageo | RC0603FR-074K7L | RC0603FR-074K7L | AISLER source or equivalent
R32 | 0R 0603 | Resistor_SMD:R_0603_1608Metric | 1 |  | Yageo | RC0603JR-070RL | RC0603JR-070RL | AISLER source or equivalent
R33 | 10k 1% 0603 | Resistor_SMD:R_0603_1608Metric | 1 |  | Yageo | RC0603FR-0710KL | RC0603FR-0710KL | AISLER source or equivalent
R40,R41 | 150k 1% 1206 | Resistor_SMD:R_1206_3216Metric | 2 |  | Yageo | RC1206FR-07150KL | RC1206FR-07150KL | AISLER source or equivalent | Mains LED dropper, verify voltage rating/series clearance
R60 | 330R 1% 0603 | Resistor_SMD:R_0603_1608Metric | 1 |  | Yageo | RC0603FR-07330RL | RC0603FR-07330RL | AISLER source or equivalent
R90 | 10k 1% 0603 | Resistor_SMD:R_0603_1608Metric | 1 |  | Yageo | RC0603FR-0710KL
RV1 | MOV 275VAC | Varistor:RV_Disc_D12mm_W3.9mm_P7.5mm | 1 |  | Bourns | MOV-14D471K | MOV-14D471K | AISLER source or equivalent
SW1 | BOOT/CFG RESET | Button_Switch_SMD:SW_Push_1TS009xxxx-xxxx-xxxx_6x6x5mm | 1 |  | HYP / equivalent | 1TS009A-1800-5000-CT
U1 | ESP32-S3-WROOM-1-N4 | RF_Module:ESP32-S3-WROOM-1 | 1 |  | Espressif Systems | ESP32-S3-WROOM-1-N4 | ESP32-S3-WROOM-1-N4 | LCSC or PCBWay equivalent
U2,U3 | MAX31865AAP+ | Package_SO:SSOP-20_5.3x7.2mm_P0.65mm | 2 |  | Analog Devices | MAX31865AAP+ | MAX31865AAP+ | AISLER source or equivalent | VERIFY_FOOTPRINT: selected IC/package must be checked against RTD footprint before production
U4 | SP3485EN-L/TR | Package_SO:SOIC-8_3.9x4.9mm_P1.27mm | 1 |  | MaxLinear | SP3485EN-L/TR | SP3485EN-L/TR | LCSC C8963 / PCBWay equivalent
U5 | AMS1117-3.3 | Package_TO_SOT_SMD:SOT-223-3_TabPin2 | 1 |  | Advanced Monolithic Systems | AMS1117-3.3 | AMS1117-3.3 | AISLER source or equivalent
X1,X2 | KF128-5.08-3P-AA | FW_Pumpengruppe:TB_KF128_508_3P | 2 |  | Cixi Kefa Elec | KF128-5.08-3P-AA | KF128-5.08-3P-AA | AISLER source or equivalent
X3 | DB128L-5.08-4P-GN-S | FW_Pumpengruppe:TB_DB128L_508_4P | 1 |  | DORABO | DB128L-5.08-4P-GN-S | DB128L-5.08-4P-GN-S | AISLER source or equivalent
X4,X5 | KF128L-3.5-2P | FW_Pumpengruppe:TB_KF128L_350_2P | 2 |  | Cixi Kefa Elec | KF128L-3.5-2P | KF128L-3.5-2P | AISLER source or equivalent
X6 | USB-C receptacle | Connector_USB:USB_C_Receptacle_HRO_TYPE-C-31-M-12 | 1 |  | Korean Hroparts Elec | TYPE-C-31-M-12 | TYPE-C-31-M-12 | AISLER source or equivalent

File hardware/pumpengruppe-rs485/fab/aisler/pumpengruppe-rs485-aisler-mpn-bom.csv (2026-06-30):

Refs | Value | Footprint | Qty | DNP | Manufacturer | MPN | Supplier | AssemblyNote
C60-C83 | 100n_RGB_LED | Capacitor_SMD:C_0603_1608Metric | 24 |  | Murata | GRM188R71C104KA01D | AISLER source or equivalent
D1 | SS14_FLYBACK_PUMP | Diode_SMD:D_SOD-123 | 1 |  | Jiangsu Changjing Electronics | B5819W | AISLER source or equivalent | SOD-123 Schottky, SS14 class
D2 | SS14_FLYBACK_MIX_ENABLE | Diode_SMD:D_SOD-123 | 1 |  | Jiangsu Changjing Electronics | B5819W | AISLER source or equivalent | SOD-123 Schottky, SS14 class
D3 | SS14_FLYBACK_MIX_DIR | Diode_SMD:D_SOD-123 | 1 |  | Jiangsu Changjing Electronics | B5819W | AISLER source or equivalent | SOD-123 Schottky, SS14 class
D4 | SS14_USB_TO_5V | Diode_SMD:D_SOD-123 | 1 |  | Jiangsu Changjing Electronics | B5819W | AISLER source or equivalent | SOD-123 Schottky, SS14 class
D10 | LED_PUMP | LED_SMD:LED_0603_1608Metric | 1 |  | Wurth Elektronik | 150060GS75000 | AISLER source or equivalent
D11 | LED_MIX_ENABLE | LED_SMD:LED_0603_1608Metric | 1 |  | Wurth Elektronik | 150060GS75000 | AISLER source or equivalent
D12 | LED_MIX_DIR | LED_SMD:LED_0603_1608Metric | 1 |  | Wurth Elektronik | 150060GS75000 | AISLER source or equivalent
D20 | LED_5V | LED_SMD:LED_0603_1608Metric | 1 |  | Wurth Elektronik | 150060GS75000 | AISLER source or equivalent
D21 | LED_3V3 | LED_SMD:LED_0603_1608Metric | 1 |  | Wurth Elektronik | 150060GS75000 | AISLER source or equivalent
D30 | LED_RS485_TX | LED_SMD:LED_0603_1608Metric | 1 |  | Wurth Elektronik | 150060GS75000 | AISLER source or equivalent
D31 | LED_RS485_RX | LED_SMD:LED_0603_1608Metric | 1 |  | Wurth Elektronik | 150060GS75000 | AISLER source or equivalent
D40 | LED_230VAC | LED_SMD:LED_0805_2012Metric | 1 |  | Wurth Elektronik | 150080GS75000 | AISLER source or equivalent | 230VAC indicator, mains side
D41 | 1N4148_LED_PROTECT | Diode_SMD:D_SOD-123 | 1 |  | Diodes Incorporated | 1N4148W-7-F | AISLER source or equivalent
D60 | SK6812MINI_STATUS_1 | LED_SMD:LED_SK6812MINI_PLCC4_3.5x3.5mm_P1.75mm | 1 |  | OPSCO Optoelectronics | SK6812MINI-E | AISLER source or equivalent
D61 | SK6812MINI_STATUS_2 | LED_SMD:LED_SK6812MINI_PLCC4_3.5x3.5mm_P1.75mm | 1 |  | OPSCO Optoelectronics | SK6812MINI-E | AISLER source or equivalent
D62 | SK6812MINI_STATUS_3 | LED_SMD:LED_SK6812MINI_PLCC4_3.5x3.5mm_P1.75mm | 1 |  | OPSCO Optoelectronics | SK6812MINI-E | AISLER source or equivalent
D63 | SK6812MINI_STATUS_4 | LED_SMD:LED_SK6812MINI_PLCC4_3.5x3.5mm_P1.75mm | 1 |  | OPSCO Optoelectronics | SK6812MINI-E | AISLER source or equivalent
D64 | SK6812MINI_VALVE_5PCT | LED_SMD:LED_SK6812MINI_PLCC4_3.5x3.5mm_P1.75mm | 1 |  | OPSCO Optoelectronics | SK6812MINI-E | AISLER source or equivalent
D65 | SK6812MINI_VALVE_10PCT | LED_SMD:LED_SK6812MINI_PLCC4_3.5x3.5mm_P1.75mm | 1 |  | OPSCO Optoelectronics | SK6812MINI-E | AISLER source or equivalent
D66 | SK6812MINI_VALVE_15PCT | LED_SMD:LED_SK6812MINI_PLCC4_3.5x3.5mm_P1.75mm | 1 |  | OPSCO Optoelectronics | SK6812MINI-E | AISLER source or equivalent
D67 | SK6812MINI_VALVE_20PCT | LED_SMD:LED_SK6812MINI_PLCC4_3.5x3.5mm_P1.75mm | 1 |  | OPSCO Optoelectronics | SK6812MINI-E | AISLER source or equivalent
D68 | SK6812MINI_VALVE_25PCT | LED_SMD:LED_SK6812MINI_PLCC4_3.5x3.5mm_P1.75mm | 1 |  | OPSCO Optoelectronics | SK6812MINI-E | AISLER source or equivalent
D69 | SK6812MINI_VALVE_30PCT | LED_SMD:LED_SK6812MINI_PLCC4_3.5x3.5mm_P1.75mm | 1 |  | OPSCO Optoelectronics | SK6812MINI-E | AISLER source or equivalent
D70 | SK6812MINI_VALVE_35PCT | LED_SMD:LED_SK6812MINI_PLCC4_3.5x3.5mm_P1.75mm | 1 |  | OPSCO Optoelectronics | SK6812MINI-E | AISLER source or equivalent
D71 | SK6812MINI_VALVE_40PCT | LED_SMD:LED_SK6812MINI_PLCC4_3.5x3.5mm_P1.75mm | 1 |  | OPSCO Optoelectronics | SK6812MINI-E | AISLER source or equivalent
D72 | SK6812MINI_VALVE_45PCT | LED_SMD:LED_SK6812MINI_PLCC4_3.5x3.5mm_P1.75mm | 1 |  | OPSCO Optoelectronics | SK6812MINI-E | AISLER source or equivalent
D73 | SK6812MINI_VALVE_50PCT | LED_SMD:LED_SK6812MINI_PLCC4_3.5x3.5mm_P1.75mm | 1 |  | OPSCO Optoelectronics | SK6812MINI-E | AISLER source or equivalent
D74 | SK6812MINI_VALVE_55PCT | LED_SMD:LED_SK6812MINI_PLCC4_3.5x3.5mm_P1.75mm | 1 |  | OPSCO Optoelectronics | SK6812MINI-E | AISLER source or equivalent
D75 | SK6812MINI_VALVE_60PCT | LED_SMD:LED_SK6812MINI_PLCC4_3.5x3.5mm_P1.75mm | 1 |  | OPSCO Optoelectronics | SK6812MINI-E | AISLER source or equivalent
D76 | SK6812MINI_VALVE_65PCT | LED_SMD:LED_SK6812MINI_PLCC4_3.5x3.5mm_P1.75mm | 1 |  | OPSCO Optoelectronics | SK6812MINI-E | AISLER source or equivalent
D77 | SK6812MINI_VALVE_70PCT | LED_SMD:LED_SK6812MINI_PLCC4_3.5x3.5mm_P1.75mm | 1 |  | OPSCO Optoelectronics | SK6812MINI-E | AISLER source or equivalent
D78 | SK6812MINI_VALVE_75PCT | LED_SMD:LED_SK6812MINI_PLCC4_3.5x3.5mm_P1.75mm | 1 |  | OPSCO Optoelectronics | SK6812MINI-E | AISLER source or equivalent
D79 | SK6812MINI_VALVE_80PCT | LED_SMD:LED_SK6812MINI_PLCC4_3.5x3.5mm_P1.75mm | 1 |  | OPSCO Optoelectronics | SK6812MINI-E | AISLER source or equivalent
D80 | SK6812MINI_VALVE_85PCT | LED_SMD:LED_SK6812MINI_PLCC4_3.5x3.5mm_P1.75mm | 1 |  | OPSCO Optoelectronics | SK6812MINI-E | AISLER source or equivalent
D81 | SK6812MINI_VALVE_90PCT | LED_SMD:LED_SK6812MINI_PLCC4_3.5x3.5mm_P1.75mm | 1 |  | OPSCO Optoelectronics | SK6812MINI-E | AISLER source or equivalent
D82 | SK6812MINI_VALVE_95PCT | LED_SMD:LED_SK6812MINI_PLCC4_3.5x3.5mm_P1.75mm | 1 |  | OPSCO Optoelectronics | SK6812MINI-E | AISLER source or equivalent
D83 | SK6812MINI_VALVE_100PCT | LED_SMD:LED_SK6812MINI_PLCC4_3.5x3.5mm_P1.75mm | 1 |  | OPSCO Optoelectronics | SK6812MINI-E | AISLER source or equivalent
F1 | TBD_T2A_T4A_L_FUSED | FW_Pumpengruppe:FUSE_5X20 | 1 |  | Littelfuse | 03453LS1H | AISLER source or equivalent | 5x20 PCB fuse holder/fuse solution, verify footprint and fuse rating before order
F2 | PTC_BUS_5V | Fuse:Fuse_1812_4532Metric | 1 |  | Bourns | MF-MSMF110-2 | AISLER source or equivalent
J1 | RJ45_RS485_IN | Connector_RJ:RJ45_Amphenol_54602-x08_Horizontal | 1 |  | Amphenol ICC | 54602-908LF | AISLER source or equivalent
J2 | RJ45_RS485_OUT | Connector_RJ:RJ45_Amphenol_54602-x08_Horizontal | 1 |  | Amphenol ICC | 54602-908LF | AISLER source or equivalent
J3 | YSTY_RS485_IN | FW_Pumpengruppe:TB_3_350 | 1 |  | Degson | DG350-3.5-03P-14-00AH | AISLER source or equivalent
J4 | YSTY_RS485_OUT | FW_Pumpengruppe:TB_3_350 | 1 |  | Degson | DG350-3.5-03P-14-00AH | AISLER source or equivalent
JP1 | RS485_TERM_ON_PARK | Connector_PinHeader_2.54mm:PinHeader_1x03_P2.54mm_Vertical | 1 |  | Samtec | TSW-103-07-G-S | AISLER source or equivalent | Use with 2.54mm jumper shunt, park position included
K1 | RELAY_PUMPE_16A | FW_Pumpengruppe:Relay_SPST_16A | 1 |  | Omron | G5LE-1A-E DC5 | AISLER source or equivalent | VERIFY_FOOTPRINT before assembly, relay footprint is still project-specific
K2 | MIX_ENABLE_RELAY | FW_Pumpengruppe:Relay_SPST_8A | 1 |  | Omron | G5LE-1A-E DC5 | AISLER source or equivalent | VERIFY_FOOTPRINT before assembly, relay footprint is still project-specific
K3 | MIX_DIR_SPDT_RELAY | FW_Pumpengruppe:Relay_SPDT_8A | 1 |  | Omron | G5LE-1 DC5 | AISLER source or equivalent | VERIFY_FOOTPRINT before assembly, relay footprint is still project-specific
PSU1 | HLK-5M05 | Converter_ACDC:Converter_ACDC_Hi-Link_HLK-5Mxx | 1 |  | Hi-Link | HLK-5M05 | AISLER source or equivalent
Q1 | AO3400A_PUMP | Package_TO_SOT_SMD:SOT-23 | 1 |  | Alpha & Omega Semiconductor | AO3400A | AISLER source or equivalent
Q2 | AO3400A_MIX_ENABLE | Package_TO_SOT_SMD:SOT-23 | 1 |  | Alpha & Omega Semiconductor | AO3400A | AISLER source or equivalent
Q3 | AO3400A_MIX_DIR | Package_TO_SOT_SMD:SOT-23 | 1 |  | Alpha & Omega Semiconductor | AO3400A | AISLER source or equivalent
R1 | 5k1_CC1_TO_GND | Resistor_SMD:R_0603_1608Metric | 1 |  | Yageo | RC0603FR-075K1L | AISLER source or equivalent
R2 | 5k1_CC2_TO_GND | Resistor_SMD:R_0603_1608Metric | 1 |  | Yageo | RC0603FR-075K1L | AISLER source or equivalent
R3 | 120R_RS485_TERM | Resistor_SMD:R_0603_1608Metric | 1 |  | Yageo | RC0603FR-07120RL | AISLER source or equivalent
R4 | 100R_GATE_PUMP | Resistor_SMD:R_0603_1608Metric | 1 |  | Yageo | RC0603FR-07100RL | AISLER source or equivalent
R5 | 100R_GATE_MIX_ENABLE | Resistor_SMD:R_0603_1608Metric | 1 |  | Yageo | RC0603FR-07100RL | AISLER source or equivalent
R6 | 100R_GATE_MIX_DIR | Resistor_SMD:R_0603_1608Metric | 1 |  | Yageo | RC0603FR-07100RL | AISLER source or equivalent
R7 | 100k_GATE_PD_PUMP | Resistor_SMD:R_0603_1608Metric | 1 |  | Yageo | RC0603FR-07100KL | AISLER source or equivalent
R8 | 100k_GATE_PD_MIX_ENABLE | Resistor_SMD:R_0603_1608Metric | 1 |  | Yageo | RC0603FR-07100KL | AISLER source or equivalent
R9 | 100k_GATE_PD_MIX_DIR | Resistor_SMD:R_0603_1608Metric | 1 |  | Yageo | RC0603FR-07100KL | AISLER source or equivalent
R10 | 2k2_LED_PUMP | Resistor_SMD:R_0603_1608Metric | 1 |  | Yageo | RC0603FR-072K2L | AISLER source or equivalent
R11 | 2k2_LED_MIX_ENABLE | Resistor_SMD:R_0603_1608Metric | 1 |  | Yageo | RC0603FR-072K2L | AISLER source or equivalent
R12 | 2k2_LED_MIX_DIR | Resistor_SMD:R_0603_1608Metric | 1 |  | Yageo | RC0603FR-072K2L | AISLER source or equivalent
R20 | 2k2_LED_5V | Resistor_SMD:R_0603_1608Metric | 1 |  | Yageo | RC0603FR-072K2L | AISLER source or equivalent
R21 | 1k5_LED_3V3 | Resistor_SMD:R_0603_1608Metric | 1 |  | Yageo | RC0603FR-071K5L | AISLER source or equivalent
R30 | 4k7_LED_TX | Resistor_SMD:R_0603_1608Metric | 1 |  | Yageo | RC0603FR-074K7L | AISLER source or equivalent
R31 | 4k7_LED_RX | Resistor_SMD:R_0603_1608Metric | 1 |  | Yageo | RC0603FR-074K7L | AISLER source or equivalent
R32 | 0R_BUS_0V_LINK | Resistor_SMD:R_0603_1608Metric | 1 |  | Yageo | RC0603JR-070RL | AISLER source or equivalent
R40 | 150k_LED_230V_1 | Resistor_SMD:R_1206_3216Metric | 1 |  | Yageo | RC1206FR-07150KL | AISLER source or equivalent | Mains LED dropper, verify voltage rating/series clearance
R41 | 150k_LED_230V_2 | Resistor_SMD:R_1206_3216Metric | 1 |  | Yageo | RC1206FR-07150KL | AISLER source or equivalent | Mains LED dropper, verify voltage rating/series clearance
R60 | 330R_RGB_DATA | Resistor_SMD:R_0603_1608Metric | 1 |  | Yageo | RC0603FR-07330RL | AISLER source or equivalent
RV1 | MOV_275VAC | Varistor:RV_Disc_D12mm_W3.9mm_P7.5mm | 1 |  | Bourns | MOV-14D471K | AISLER source or equivalent
U1 | ESP32-WROOM-32D | RF_Module:ESP32-WROOM-32D | 1 |  | Espressif Systems | ESP32-WROOM-32D-N4 | AISLER source or equivalent
U2 | MAX31865_VL | Package_SO:SOIC-16_3.9x9.9mm_P1.27mm | 1 |  | Analog Devices | MAX31865AAP+ | AISLER source or equivalent | VERIFY_FOOTPRINT: selected IC/package must be checked against RTD footprint before production
U3 | MAX31865_RL | Package_SO:SOIC-16_3.9x9.9mm_P1.27mm | 1 |  | Analog Devices | MAX31865AAP+ | AISLER source or equivalent | VERIFY_FOOTPRINT: selected IC/package must be checked against RTD footprint before production
U4 | MAX3485 | Package_SO:SOIC-8_3.9x4.9mm_P1.27mm | 1 |  | Analog Devices | MAX3485EESA+ | AISLER source or equivalent
U5 | 3V3_REG | Package_TO_SOT_SMD:SOT-223-3_TabPin2 | 1 |  | Advanced Monolithic Systems | AMS1117-3.3 | AISLER source or equivalent
U6 | CP2102N_USB_UART | Package_DFN_QFN:QFN-24-1EP_4x4mm_P0.5mm_EP2.7x2.7mm | 1 |  | Silicon Labs | CP2102N-A02-GQFN24 | AISLER source or equivalent
X1 | 230V_IN_L_N_PE | FW_Pumpengruppe:TB_3_762 | 1 |  | Degson | DG129-7.62-03P-14-00AH | AISLER source or equivalent
X2 | PUMPE_L_SW_N_PE | FW_Pumpengruppe:TB_3_762 | 1 |  | Degson | DG129-7.62-03P-14-00AH | AISLER source or equivalent
X3 | MISCHER_AUF_ZU_N_PE | FW_Pumpengruppe:TB_4_762 | 1 |  | Degson | DG129-7.62-04P-14-00AH | AISLER source or equivalent
X4 | RTD_VL_PT1000 | FW_Pumpengruppe:TB_2_350 | 1 |  | Degson | DG350-3.5-02P-14-00AH | AISLER source or equivalent
X5 | RTD_RL_PT1000 | FW_Pumpengruppe:TB_2_350 | 1 |  | Degson | DG350-3.5-02P-14-00AH | AISLER source or equivalent
X6 | USB_C_SERVICE_FLASH | Connector_USB:USB_C_Receptacle_HRO_TYPE-C-31-M-12 | 1 |  | Korean Hroparts Elec | TYPE-C-31-M-12 | AISLER source or equivalent

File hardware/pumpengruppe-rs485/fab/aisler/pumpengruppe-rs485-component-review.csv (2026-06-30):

Refs | Value | Footprint | Qty | DNP | Manufacturer | MPN | AISLER_MPN | Supplier | AssemblyNote
F1 | 5x20 fuse holder | FW_Pumpengruppe:FUSE_5X20 | 1 |  | Littelfuse | 03453LS1H | 03453LS1H | AISLER source or equivalent | 5x20 PCB fuse holder/fuse solution, verify footprint and fuse rating before order
K1 | G5LE-1A-E DC5 | FW_Pumpengruppe:Relay_SPST_16A | 1 |  | Omron | G5LE-1A-E DC5 | G5LE-1A-E DC5 | AISLER source or equivalent | VERIFY_FOOTPRINT before assembly, relay footprint is still project-specific
K2 | G5LE-1A-E DC5 | FW_Pumpengruppe:Relay_SPST_8A | 1 |  | Omron | G5LE-1A-E DC5 | G5LE-1A-E DC5 | AISLER source or equivalent | VERIFY_FOOTPRINT before assembly, relay footprint is still project-specific
K3 | G5LE-1 DC5 | FW_Pumpengruppe:Relay_SPDT_8A | 1 |  | Omron | G5LE-1 DC5 | G5LE-1 DC5 | AISLER source or equivalent | VERIFY_FOOTPRINT before assembly, relay footprint is still project-specific
R40,R41 | 150k 1% 1206 | Resistor_SMD:R_1206_3216Metric | 2 |  | Yageo | RC1206FR-07150KL | RC1206FR-07150KL | AISLER source or equivalent | Mains LED dropper, verify voltage rating/series clearance
U2,U3 | MAX31865AAP+ | Package_SO:SOIC-16_3.9x9.9mm_P1.27mm | 2 |  | Analog Devices | MAX31865AAP+ | MAX31865AAP+ | AISLER source or equivalent | VERIFY_FOOTPRINT: selected IC/package must be checked against RTD footprint before production

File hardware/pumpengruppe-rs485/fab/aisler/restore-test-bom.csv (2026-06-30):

Refs | Value | Footprint | Qty | DNP
C60 | 100n_RGB_LED | Capacitor_SMD:C_0603_1608Metric | 1
C61 | 100n_RGB_LED | Capacitor_SMD:C_0603_1608Metric | 1
C62 | 100n_RGB_LED | Capacitor_SMD:C_0603_1608Metric | 1
C63 | 100n_RGB_LED | Capacitor_SMD:C_0603_1608Metric | 1
C64 | 100n_RGB_LED | Capacitor_SMD:C_0603_1608Metric | 1
C65 | 100n_RGB_LED | Capacitor_SMD:C_0603_1608Metric | 1
C66 | 100n_RGB_LED | Capacitor_SMD:C_0603_1608Metric | 1
C67 | 100n_RGB_LED | Capacitor_SMD:C_0603_1608Metric | 1
C68 | 100n_RGB_LED | Capacitor_SMD:C_0603_1608Metric | 1
C69 | 100n_RGB_LED | Capacitor_SMD:C_0603_1608Metric | 1
C70 | 100n_RGB_LED | Capacitor_SMD:C_0603_1608Metric | 1
C71 | 100n_RGB_LED | Capacitor_SMD:C_0603_1608Metric | 1
C72 | 100n_RGB_LED | Capacitor_SMD:C_0603_1608Metric | 1
C73 | 100n_RGB_LED | Capacitor_SMD:C_0603_1608Metric | 1
C74 | 100n_RGB_LED | Capacitor_SMD:C_0603_1608Metric | 1
C75 | 100n_RGB_LED | Capacitor_SMD:C_0603_1608Metric | 1
C76 | 100n_RGB_LED | Capacitor_SMD:C_0603_1608Metric | 1
C77 | 100n_RGB_LED | Capacitor_SMD:C_0603_1608Metric | 1
C78 | 100n_RGB_LED | Capacitor_SMD:C_0603_1608Metric | 1
C79 | 100n_RGB_LED | Capacitor_SMD:C_0603_1608Metric | 1
C80 | 100n_RGB_LED | Capacitor_SMD:C_0603_1608Metric | 1
C81 | 100n_RGB_LED | Capacitor_SMD:C_0603_1608Metric | 1
C82 | 100n_RGB_LED | Capacitor_SMD:C_0603_1608Metric | 1
C83 | 100n_RGB_LED | Capacitor_SMD:C_0603_1608Metric | 1
D1 | SS14_FLYBACK_PUMP | FW_Pumpengruppe:D_SOD123 | 1
D2 | SS14_FLYBACK_MIX_ENABLE | FW_Pumpengruppe:D_SOD123 | 1
D3 | SS14_FLYBACK_MIX_DIR | FW_Pumpengruppe:D_SOD123 | 1
D4 | SS14_USB_TO_5V | FW_Pumpengruppe:D_SOD123 | 1
D10 | LED_PUMP | FW_Pumpengruppe:LED_0603 | 1
D11 | LED_MIX_ENABLE | FW_Pumpengruppe:LED_0603 | 1
D12 | LED_MIX_DIR | FW_Pumpengruppe:LED_0603 | 1
D20 | LED_5V | FW_Pumpengruppe:LED_0603 | 1
D21 | LED_3V3 | FW_Pumpengruppe:LED_0603 | 1
D30 | LED_RS485_TX | FW_Pumpengruppe:LED_0603 | 1
D31 | LED_RS485_RX | FW_Pumpengruppe:LED_0603 | 1
D40 | LED_230VAC | LED_SMD:LED_0805_2012Metric | 1
D41 | 1N4148_LED_PROTECT | Diode_SMD:D_SOD-123 | 1
D50 | TVS_RS485_A_COM | Diode_SMD:D_SOD-123 | 1
D51 | TVS_RS485_B_COM | Diode_SMD:D_SOD-123 | 1
D52 | TVS_RS485_A_B | Diode_SMD:D_SOD-123 | 1
D60 | SK6812MINI_STATUS_1 | LED_SMD:LED_SK6812MINI_PLCC4_3.5x3.5mm_P1.75mm | 1
D61 | SK6812MINI_STATUS_2 | LED_SMD:LED_SK6812MINI_PLCC4_3.5x3.5mm_P1.75mm | 1
D62 | SK6812MINI_STATUS_3 | LED_SMD:LED_SK6812MINI_PLCC4_3.5x3.5mm_P1.75mm | 1
D63 | SK6812MINI_STATUS_4 | LED_SMD:LED_SK6812MINI_PLCC4_3.5x3.5mm_P1.75mm | 1
D64 | SK6812MINI_VALVE_5PCT | LED_SMD:LED_SK6812MINI_PLCC4_3.5x3.5mm_P1.75mm | 1
D65 | SK6812MINI_VALVE_10PCT | LED_SMD:LED_SK6812MINI_PLCC4_3.5x3.5mm_P1.75mm | 1
D66 | SK6812MINI_VALVE_15PCT | LED_SMD:LED_SK6812MINI_PLCC4_3.5x3.5mm_P1.75mm | 1
D67 | SK6812MINI_VALVE_20PCT | LED_SMD:LED_SK6812MINI_PLCC4_3.5x3.5mm_P1.75mm | 1
D68 | SK6812MINI_VALVE_25PCT | LED_SMD:LED_SK6812MINI_PLCC4_3.5x3.5mm_P1.75mm | 1
D69 | SK6812MINI_VALVE_30PCT | LED_SMD:LED_SK6812MINI_PLCC4_3.5x3.5mm_P1.75mm | 1
D70 | SK6812MINI_VALVE_35PCT | LED_SMD:LED_SK6812MINI_PLCC4_3.5x3.5mm_P1.75mm | 1
D71 | SK6812MINI_VALVE_40PCT | LED_SMD:LED_SK6812MINI_PLCC4_3.5x3.5mm_P1.75mm | 1
D72 | SK6812MINI_VALVE_45PCT | LED_SMD:LED_SK6812MINI_PLCC4_3.5x3.5mm_P1.75mm | 1
D73 | SK6812MINI_VALVE_50PCT | LED_SMD:LED_SK6812MINI_PLCC4_3.5x3.5mm_P1.75mm | 1
D74 | SK6812MINI_VALVE_55PCT | LED_SMD:LED_SK6812MINI_PLCC4_3.5x3.5mm_P1.75mm | 1
D75 | SK6812MINI_VALVE_60PCT | LED_SMD:LED_SK6812MINI_PLCC4_3.5x3.5mm_P1.75mm | 1
D76 | SK6812MINI_VALVE_65PCT | LED_SMD:LED_SK6812MINI_PLCC4_3.5x3.5mm_P1.75mm | 1
D77 | SK6812MINI_VALVE_70PCT | LED_SMD:LED_SK6812MINI_PLCC4_3.5x3.5mm_P1.75mm | 1
D78 | SK6812MINI_VALVE_75PCT | LED_SMD:LED_SK6812MINI_PLCC4_3.5x3.5mm_P1.75mm | 1
D79 | SK6812MINI_VALVE_80PCT | LED_SMD:LED_SK6812MINI_PLCC4_3.5x3.5mm_P1.75mm | 1
D80 | SK6812MINI_VALVE_85PCT | LED_SMD:LED_SK6812MINI_PLCC4_3.5x3.5mm_P1.75mm | 1
D81 | SK6812MINI_VALVE_90PCT | LED_SMD:LED_SK6812MINI_PLCC4_3.5x3.5mm_P1.75mm | 1
D82 | SK6812MINI_VALVE_95PCT | LED_SMD:LED_SK6812MINI_PLCC4_3.5x3.5mm_P1.75mm | 1
D83 | SK6812MINI_VALVE_100PCT | LED_SMD:LED_SK6812MINI_PLCC4_3.5x3.5mm_P1.75mm | 1
F1 | TBD_T2A_T4A_L_FUSED | FW_Pumpengruppe:FUSE_5X20 | 1
F2 | PTC_BUS_5V | Fuse:Fuse_1812_4532Metric | 1
J1 | RJ45_RS485_IN | Connector_RJ:RJ45_Amphenol_54602-x08_Horizontal | 1
J2 | RJ45_RS485_OUT | Connector_RJ:RJ45_Amphenol_54602-x08_Horizontal | 1
J3 | YSTY_RS485_IN | FW_Pumpengruppe:TB_3_350 | 1
J4 | YSTY_RS485_OUT | FW_Pumpengruppe:TB_3_350 | 1
JP1 | RS485_TERM_ON_PARK | Connector_PinHeader_2.54mm:PinHeader_1x03_P2.54mm_Vertical | 1
K1 | RELAY_PUMPE_16A | FW_Pumpengruppe:Relay_SPST_16A | 1
K2 | MIX_ENABLE_RELAY | FW_Pumpengruppe:Relay_SPST_8A | 1
K3 | MIX_DIR_SPDT_RELAY | FW_Pumpengruppe:Relay_SPDT_8A | 1
PSU1 | HLK-5M05 | Converter_ACDC:Converter_ACDC_Hi-Link_HLK-5Mxx | 1
Q1 | AO3400A_PUMP | FW_Pumpengruppe:SOT23_NMOS | 1
Q2 | AO3400A_MIX_ENABLE | FW_Pumpengruppe:SOT23_NMOS | 1
Q3 | AO3400A_MIX_DIR | FW_Pumpengruppe:SOT23_NMOS | 1
R1 | 5k1_CC1_TO_GND | FW_Pumpengruppe:R_0603 | 1
R2 | 5k1_CC2_TO_GND | FW_Pumpengruppe:R_0603 | 1
R3 | 120R_RS485_TERM | FW_Pumpengruppe:R_0603 | 1
R4 | 100R_GATE_PUMP | FW_Pumpengruppe:R_0603 | 1
R5 | 100R_GATE_MIX_ENABLE | FW_Pumpengruppe:R_0603 | 1
R6 | 100R_GATE_MIX_DIR | FW_Pumpengruppe:R_0603 | 1
R7 | 100k_GATE_PD_PUMP | FW_Pumpengruppe:R_0603 | 1
R8 | 100k_GATE_PD_MIX_ENABLE | FW_Pumpengruppe:R_0603 | 1
R9 | 100k_GATE_PD_MIX_DIR | FW_Pumpengruppe:R_0603 | 1
R10 | 2k2_LED_PUMP | FW_Pumpengruppe:R_0603 | 1
R11 | 2k2_LED_MIX_ENABLE | FW_Pumpengruppe:R_0603 | 1
R12 | 2k2_LED_MIX_DIR | FW_Pumpengruppe:R_0603 | 1
R20 | 2k2_LED_5V | FW_Pumpengruppe:R_0603 | 1
R21 | 1k5_LED_3V3 | FW_Pumpengruppe:R_0603 | 1
R30 | 4k7_LED_TX | FW_Pumpengruppe:R_0603 | 1
R31 | 4k7_LED_RX | FW_Pumpengruppe:R_0603 | 1
R32 | 0R_BUS_0V_LINK | FW_Pumpengruppe:R_0603 | 1
R40 | 150k_LED_230V_1 | Resistor_SMD:R_1206_3216Metric | 1
R41 | 150k_LED_230V_2 | Resistor_SMD:R_1206_3216Metric | 1
R60 | 330R_RGB_DATA | Resistor_SMD:R_0603_1608Metric | 1
RV1 | MOV_275VAC | Varistor:RV_Disc_D12mm_W3.9mm_P7.5mm | 1
U1 | ESP32-WROOM-32D | RF_Module:ESP32-WROOM-32D | 1
U2 | MAX31865_VL | FW_Pumpengruppe:SOIC16_RTD | 1
U3 | MAX31865_RL | FW_Pumpengruppe:SOIC16_RTD | 1
U4 | MAX3485 | Package_SO:SOIC-8_3.9x4.9mm_P1.27mm | 1
U5 | 3V3_REG | FW_Pumpengruppe:LDO_SOT223 | 1
U6 | CP2102N_USB_UART | FW_Pumpengruppe:USB_UART_QFN24 | 1
X1 | 230V_IN_L_N_PE | FW_Pumpengruppe:TB_3_762 | 1
X2 | PUMPE_L_SW_N_PE | FW_Pumpengruppe:TB_3_762 | 1
X3 | MISCHER_AUF_ZU_N_PE | FW_Pumpengruppe:TB_4_762 | 1
X4 | RTD_VL_PT1000 | FW_Pumpengruppe:TB_2_350 | 1
X5 | RTD_RL_PT1000 | FW_Pumpengruppe:TB_2_350 | 1
X6 | USB_C_SERVICE_FLASH | Connector_USB:USB_C_Receptacle_HRO_TYPE-C-31-M-12 | 1

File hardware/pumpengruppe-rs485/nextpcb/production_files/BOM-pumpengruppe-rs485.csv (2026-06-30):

Designator | Quantity | MPN | manufacturer | Package/Footprint | Description | Procurement Type | Customer Note
C81,C62,C71,C72,C61,C75,C66,C73,C82,C70,C63,C65,C60,C78,C83,C79,C76,C74,C69,C77,C80,C67,C64,C68 | 24 | LD03YC104KAB2A | Kyocera | C_0603_1608Metric | 100nF 16V
D4,D1,D2,D3 | 4 | B5819W | WPMtek | D_SOD-123 | B5819W
D10,D11,D12,D20,D21,D30,D31 | 7 | A16-24DSG | Omron | LED_0603_1608Metric | LED green 0603
D40 | 1 | A16-24DSG | Omron | LED_0805_2012Metric | LED green 0805
D41 | 1 | 1N4148W | World Products | D_SOD-123 | 1N4148W
D50,D51,D52 | 3 | T212A123K050MS | Kemet | D_SOD-123 | DNP TVS SOD-123
D77,D82,D78,D71,D65,D67,D63,D75,D60,D76,D66,D70,D69,D83,D81,D62,D61,D68,D80,D74,D79,D73,D72,D64 | 24 | SK6812MINI-E | OPSCO OPTOELECTRONICS | LED_SK6812MINI_PLCC4_3.5x3.5mm_P1.75mm | SK6812MINI-E
F1 | 1 | YFT-20-05-H-05-SB | Samtec | FUSE_5X20 | 5x20 fuse holder
F2 | 1 | 1812L110/24DR | Littelfuse | Fuse_1812_4532Metric | PTC 1.1A 1812
J1,J2 | 2 | TMK021CG8R8BK5W | Taiyo Yuden | RJ45_Amphenol_54602-x08_Horizontal | RJ45 8P8C horizontal
J3,J4 | 2 | 1844223 | Phoenix Contact | TB_3_350 | 3-pin 3.5mm terminal
JP1 | 1 | 87220-3 | TE Connectivity (Tyco Electronics) | PinHeader_1x03_P2.54mm_Vertical | 1x3 2.54mm header
K1 | 1 | G5LE-1A-E DC5 | Omron | Relay_SPST_16A | G5LE-1A-E DC5
K2 | 1 | G5LE-1A-E DC5 | Omron | Relay_SPST_8A | G5LE-1A-E DC5
K3 | 1 | G5LE-1 DC5 | Omron | Relay_SPDT_8A | G5LE-1 DC5
MB1 | 1 |  |  | BREAKAWAY_MOUSEBITES | BREAKAWAY_MOUSEBITES
PSU1 | 1 | IRM-05-5 | Mean Well | Converter_ACDC_MeanWell_IRM-05-xx_THT | IRM-05-5
Q1,Q2,Q3 | 3 | AO3400A | UMW | SOT-23 | AO3400A
R1,R2 | 2 | RK73G1JTTD5101F | KOA | R_0603_1608Metric | 5.1k 1% 0603
R3 | 1 | CR0603-FX-1200ELF | Bourns | R_0603_1608Metric | 120R 1% 0603
R4,R5,R6 | 3 | CR0603-FX-1000ELF | Bourns | R_0603_1608Metric | 100R 1% 0603
R7,R8,R9 | 3 | CR0603-FX-1003ELF | Bourns | R_0603_1608Metric | 100k 1% 0603
R10,R11,R12,R20 | 4 | CR0603-FX-2201ELF | Bourns | R_0603_1608Metric | 2.2k 1% 0603
R21 | 1 | AC0603FR-071K5L | Yageo | R_0603_1608Metric | 1.5k 1% 0603
R30,R31 | 2 | AC0603FR-074K7L | Yageo | R_0603_1608Metric | 4.7k 1% 0603
R32 | 1 | CR0603-J/-000ELF | Bourns | R_0603_1608Metric | 0R 0603
R40,R41 | 2 | RK73H2BTTD1503F | KOA | R_1206_3216Metric | 150k 1% 1206
R60 | 1 | RC0603FR-07330RL | Yageo | R_0603_1608Metric | 330R 1% 0603
RV1 | 1 | B72210S2141K101 | TDK | RV_Disc_D12mm_W3.9mm_P7.5mm | MOV 275VAC
U1 | 1 | ESP32-WROOM-32D | Espressif Systems | ESP32-WROOM-32D | ESP32-WROOM-32D-N4
U2,U3 | 2 | MAX31865AAP+ | Analog Devices | SOIC-16_3.9x9.9mm_P1.27mm | MAX31865AAP+
U4 | 1 | MAX3485EESA+ | Analog Devices | SOIC-8_3.9x4.9mm_P1.27mm | MAX3485EESA+
U5 | 1 | AMS1117-3.3 | UMW | SOT-223-3_TabPin2 | AMS1117-3.3
U6 | 1 | CP2102N-A02-GQFN24 | Silicon | QFN-24-1EP_4x4mm_P0.5mm_EP2.7x2.7mm | CP2102N-A02-GQFN24
X1,X2 | 2 | 5001 | Terminal | TB_3_762 | 3-pin 7.62mm terminal
X3 | 1 | 5001 | Terminal | TB_4_762 | 4-pin 7.62mm terminal
X4,X5 | 2 | B88069X8091B502 | TDK | TB_2_350 | 2-pin 3.5mm terminal
X6 | 1 | TYPE-C-31-M-12 | HRO | USB_C_Receptacle_HRO_TYPE-C-31-M-12 | USB-C receptacle

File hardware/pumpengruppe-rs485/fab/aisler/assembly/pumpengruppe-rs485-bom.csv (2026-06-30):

Refs | Value | Footprint | Qty | DNP | Notes
X1 | 230V_IN_L_N_PE | FW_Pumpengruppe:TB_3_762 | 1 |  | 7.62 mm screw terminal, mains rated
X2 | PUMPE_L_SW_N_PE | FW_Pumpengruppe:TB_3_762 | 1 |  | 7.62 mm screw terminal, mains rated
X3 | MISCHER_AUF_ZU_N_PE | FW_Pumpengruppe:TB_4_762 | 1 |  | 7.62 mm screw terminal, mains rated
F1 | 5x20 slow-blow fuse 5A | FW_Pumpengruppe:FUSE_5X20 | 1 |  | Use fuse and holder rated for 250 VAC
PSU1 | IRM-05-5 230VAC to 5V module | Converter_ACDC:Converter_ACDC_MeanWell_IRM-05-xx_THT | 1 |  | Mean Well IRM-05-5, AISLER assembly target; verify 230VAC clearance and final routing
K1 | RELAY_PUMPE_16A | FW_Pumpengruppe:Relay_SPST_16A | 1 |  | 5 V coil, contact rating suitable for pump load
K2 | MIX_ENABLE_RELAY_SPST_5V | FW_Pumpengruppe:Relay_SPST_8A | 1 |  | 5 V coil, contact rating suitable for actuator
K3 | MIX_DIR_RELAY_SPDT_5V_NC_ZU_NO_AUF | FW_Pumpengruppe:Relay_SPDT_8A | 1 |  | SPDT direction relay, 5 V coil
U1 | ESP32-WROOM-32D PCB antenna | RF_Module:ESP32-WROOM-32D | 1 |  | Espressif ESP32-WROOM-32D
U2,U3 | MAX31865 RTD frontend | FW_Pumpengruppe:SOIC16_RTD | 2 |  | MAX31865 or pin-compatible RTD frontend
U4 | MAX3485/SP3485 3.3V RS485 transceiver SOIC-8 | Package_SO:SOIC-8_3.9x4.9mm_P1.27mm | 1 |  | 3.3 V half-duplex RS485 transceiver
U5 | AMS1117-3.3 compatible 3V3 regulator | FW_Pumpengruppe:LDO_SOT223 | 1 |  | SOT-223 LDO, check dissipation from 5 V
U6 | CP2102N USB-UART | FW_Pumpengruppe:USB_UART_QFN24 | 1 |  | Silicon Labs CP2102N QFN24
J1,J2 | RJ45 RS485 daisychain edge connector | Connector_RJ:RJ45_Amphenol_54602-x08_Horizontal | 2 |  | Horizontal RJ45, edge accessible
J3,J4 | YSTY RS485 screw terminal | FW_Pumpengruppe:TB_3_350 | 2 |  | 3.5 mm screw terminal
X4,X5 | RTD screw terminal VL/RL | FW_Pumpengruppe:TB_2_350 | 2 |  | 3.5 mm screw terminal
X6 | USB-C service / flash edge connector | Connector_USB:USB_C_Receptacle_HRO_TYPE-C-31-M-12 | 1 |  | HRO TYPE-C-31-M-12 or compatible
R1,R2 | 5k1 USB-C CC pulldown | FW_Pumpengruppe:R_0603 | 2 |  | Generic 0603 1 percent
R3 | 120R RS485 termination | FW_Pumpengruppe:R_0603 | 1 |  | Generic 0603 1 percent
JP1 | RS485 termination 1x3 jumper, 1-2 on / 2-3 park | Connector_PinHeader_2.54mm:PinHeader_1x03_P2.54mm_Vertical | 1 |  | 2.54 mm 1x3 header plus shunt
Q1,Q2,Q3 | AO3400A compatible logic-level NMOS SOT-23 | FW_Pumpengruppe:SOT23_NMOS | 3 |  | AO3400A or similar logic-level NMOS
R4,R5,R6 | 100R 0603 gate series resistor | FW_Pumpengruppe:R_0603 | 3 |  | Generic 0603
R7,R8,R9 | 100k 0603 gate pulldown | FW_Pumpengruppe:R_0603 | 3 |  | Generic 0603
D1,D2,D3 | SS14 SOD123 flyback diode | FW_Pumpengruppe:D_SOD123 | 3 |  | SS14 or compatible Schottky
R10,R11,R12 | 2k2 0603 relay status LED resistor | FW_Pumpengruppe:R_0603 | 3 |  | Generic 0603
D10,D11,D12 | 0603 relay status LED | FW_Pumpengruppe:LED_0603 | 3 |  | Generic low-current LED
R40,R41 | 150k 1206 mains LED dropper resistor | Resistor_SMD:R_1206_3216Metric | 2 |  | Use voltage-rated resistors; mains-side only
D40 | 0805 230VAC indicator LED on mains side | LED_SMD:LED_0805_2012Metric | 1 |  | Mains-side indicator LED
D41 | 1N4148/SOD-123 antiparallel LED protection diode | Diode_SMD:D_SOD-123 | 1 |  | 1N4148W or compatible
RV1 | MOV 275VAC disc varistor across L/N | Varistor:RV_Disc_D12mm_W3.9mm_P7.5mm | 1 |  | MOV 275 VAC, lead pitch 7.5 mm
R20 | 2k2 0603 5V indicator resistor | FW_Pumpengruppe:R_0603 | 1 |  | Generic 0603
D20 | 0603 5V indicator LED | FW_Pumpengruppe:LED_0603 | 1 |  | Generic low-current LED
R21 | 1k5 0603 3V3 indicator resistor | FW_Pumpengruppe:R_0603 | 1 |  | Generic 0603
D21 | 0603 3V3 indicator LED | FW_Pumpengruppe:LED_0603 | 1 |  | Generic low-current LED
R30,R31 | 4k7 0603 RS485 TX/RX activity LED resistor | FW_Pumpengruppe:R_0603 | 2 |  | Generic 0603
D30,D31 | 0603 RS485 TX/RX activity LED | FW_Pumpengruppe:LED_0603 | 2 |  | Generic low-current LED
R60 | 330R 0603 RGB data series resistor | Resistor_SMD:R_0603_1608Metric | 1 |  | ESP32 GPIO21 to first SK6812 DIN
C60-C83 | 100nF 16V 0603 RGB LED local decoupling capacitor | Capacitor_SMD:C_0603_1608Metric | 24 |  | One capacitor per RGB LED
D60-D83 | SK6812MINI 3535 5V addressable RGB LED PLCC4 | LED_SMD:LED_SK6812MINI_PLCC4_3.5x3.5mm_P1.75mm | 24 |  | 4 status LEDs plus 20 vertical valve-position LEDs, 5 percent per LED
D50,D51,D52 | Optional RS485 TVS positions A-COM/B-COM/A-B | Diode_SMD:D_SOD-123 | 3 | DNP | Optional protection footprints, do not populate for base assembly
D4 | SS14 USB VBUS to +5V Schottky diode | FW_Pumpengruppe:D_SOD123 | 1 |  | SS14 or compatible Schottky
F2 | 1812 resettable fuse BUS_5V to local +5V | Fuse:Fuse_1812_4532Metric | 1 |  | Polyfuse sized for RJ45 5 V sharing
R32 | 0R 0603 BUS_COM to local GND link for RJ45 power sharing | FW_Pumpengruppe:R_0603 | 1 |  | Populate only when common SELV bus ground is intended

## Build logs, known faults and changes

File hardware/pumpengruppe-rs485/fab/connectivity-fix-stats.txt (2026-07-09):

removed_wires=33
removed_no_connect=20
added_labels=49

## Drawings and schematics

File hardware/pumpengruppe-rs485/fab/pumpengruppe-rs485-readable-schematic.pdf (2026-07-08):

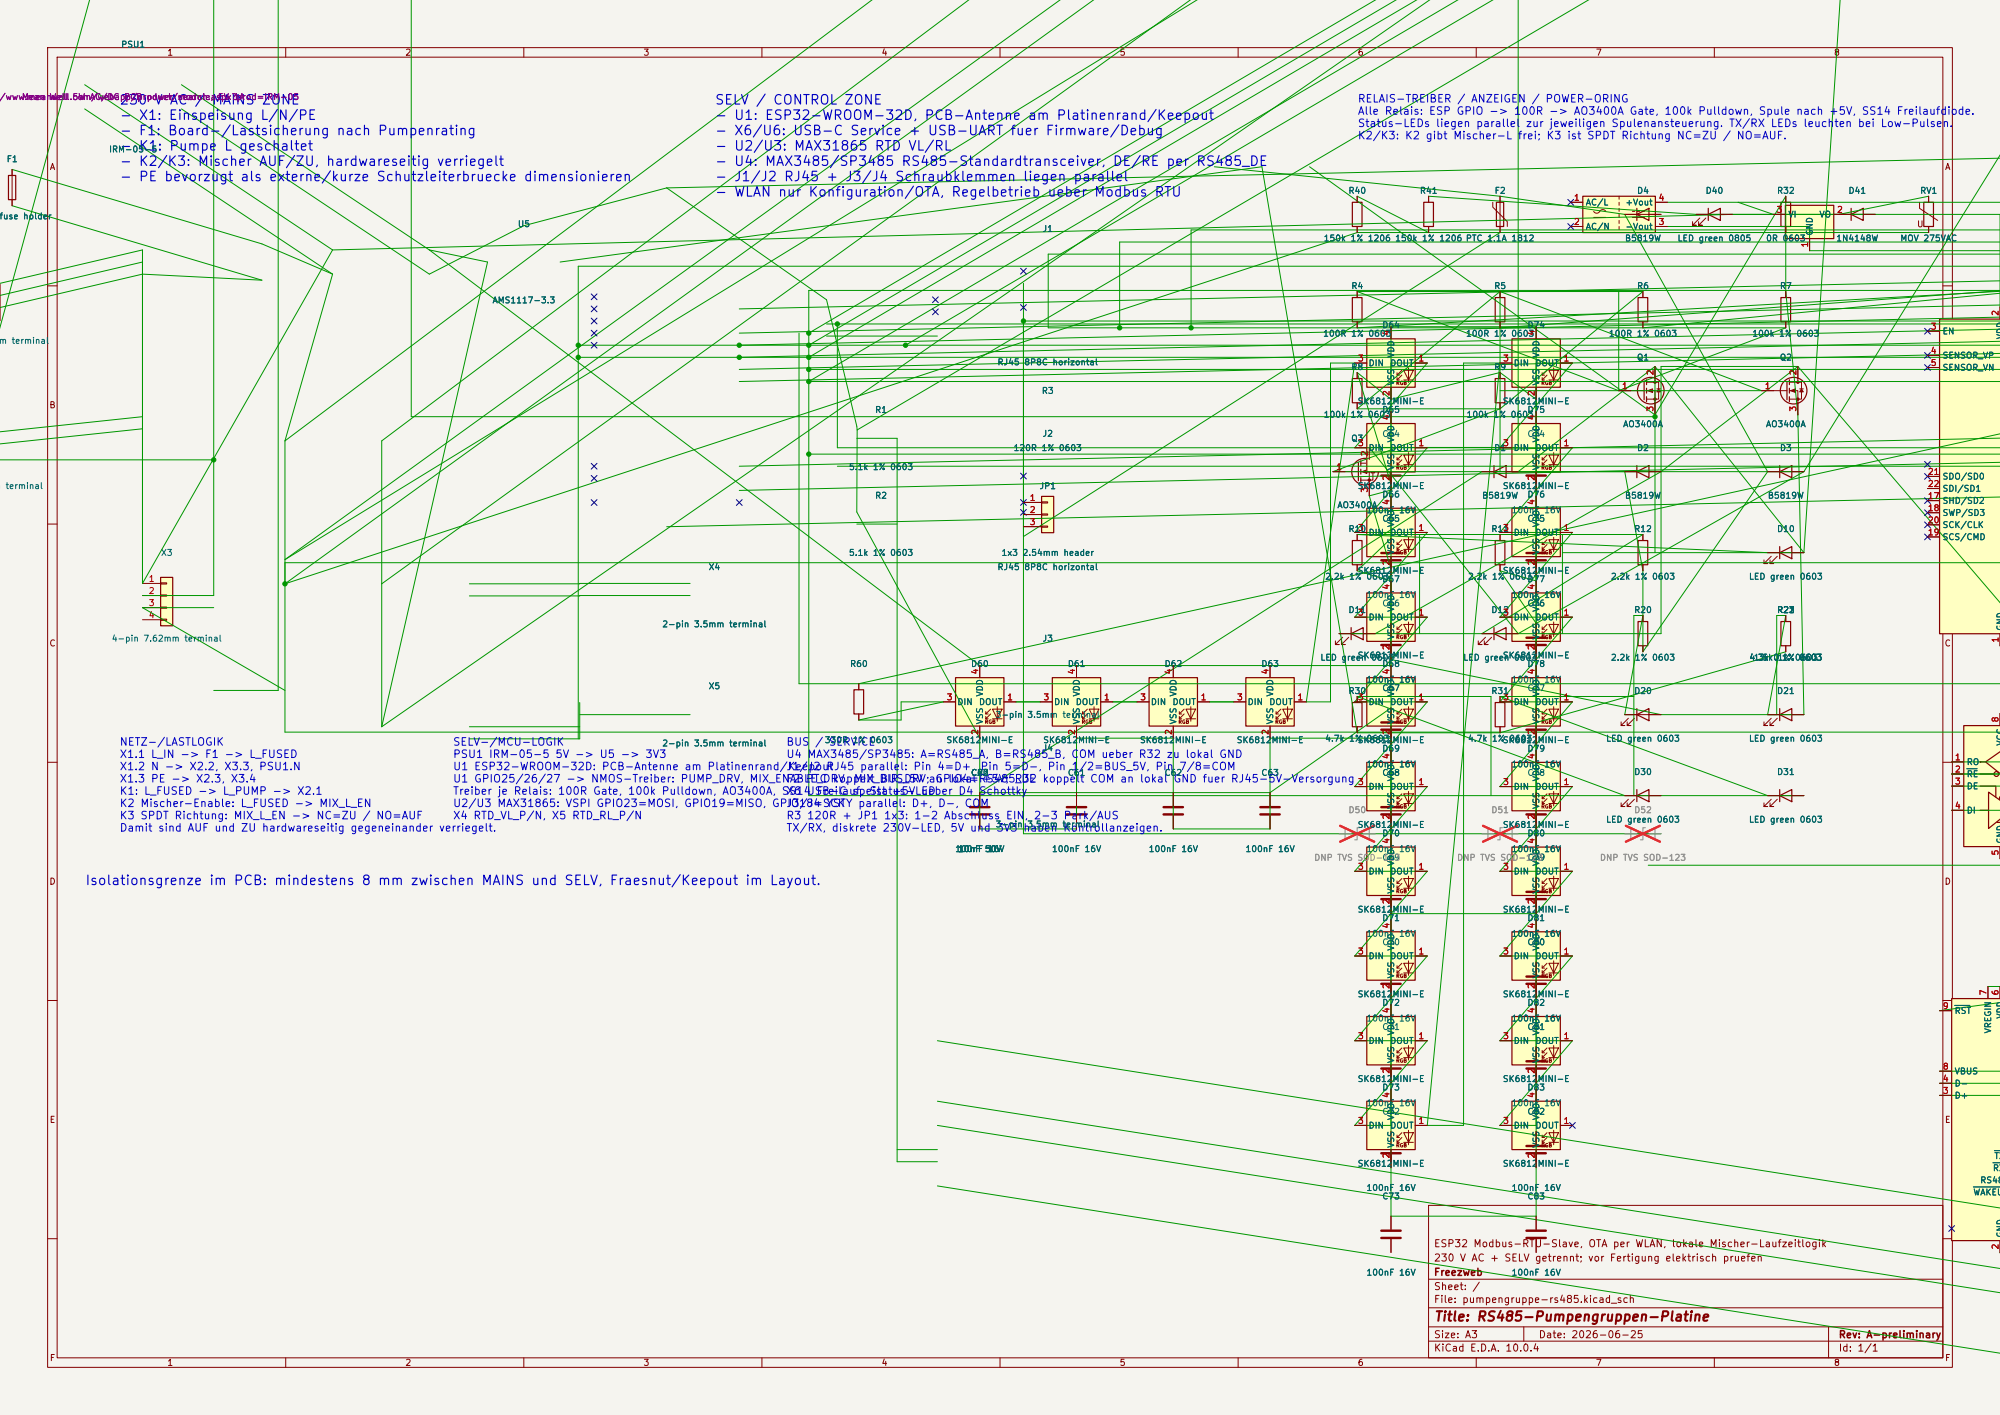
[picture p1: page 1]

230 V AC / MAINS ZONE - X1: Einspeisung L/N/PE - F1: Board-/Lastsicherung nach Pumpenrating - K1: Pumpe L geschaltet - K2/K3: Mischer AUF/ZU, hardwareseitig verriegelt - PE bevorzugt als externe/kurze Schutzleiterbruecke dimensionieren

SELV / CONTROL ZONE - U1: ESP32-WROOM-32D, PCB-Antenne am Platinenrand/Keepout - X6/U6: USB-C Service + USB-UART fuer Firmware/Debug - U2/U3: MAX31865 RTD VL/RL - U4: MAX3485/SP3485 RS485-Standardtransceiver, DE/RE per RS485_DE - J1/J2 RJ45 + J3/J4 Schraubklemmen liegen parallel - WLAN nur Konfiguration/OTA, Regelbetrieb ueber Modbus RTU

RELAIS-TREIBER / ANZEIGEN / POWER-ORING
Alle Relais: ESP GPIO -> 100R -> AO3400A Gate, 100k Pulldown, Spule nach +5V, SS14 Freilaufdiode.
Status-LEDs liegen parallel zur jeweiligen Spulenansteuerung. TX/RX LEDs leuchten bei Low-Pulsen.

R8 | RGB DOUT | 1 VSS

4 4 Q2 | SENSOR_VP

5 5 | SENSOR_VN

RGB DOUT | 1 VSS | RGB DOUT | 1 VSS

330R 1% 0603 | C23 C60 | SK6812MINI-E C60 J4 J4 | 4.7k 1% 0603 | 4.7k | 1% 0603 SK6812MINI-E | LED green 0603 D20 | LED green 0603 D21 LED green 0603 LED green 0603 D31 | RO RO

NETZ-/LASTLOGIK
X1.1 L_IN -> F1 -> L_FUSED
X1.2 N -> X2.2, X3.3, PSU1.N
K1: L_FUSED -> L_PUMP -> X2.1
K2 Mischer-Enable: L_FUSED -> MIX_L_EN
K3 SPDT Richtung: MIX_L_EN -> NC=ZU / NO=AUF
Damit sind AUF und ZU hardwareseitig gegeneinander verriegelt.

SELV-/MCU-LOGIK
PSU1 IRM-05-5 5V -> U5 -> 3V3
U1 ESP32-WROOM-32D: PCB-Antenne am Platinenrand/Keepout
U1 GPIO25/26/27 -> NMOS-Treiber: PUMP_DRV, MIX_ENABLE_DRV, MIX_DIR_DRV; GPIO4=RS485_DE
Treiber je Relais: 100R Gate, 100k Pulldown, AO3400A, SS14 Freilauf, Status-LED
U2/U3 MAX31865: VSPI GPIO23=MOSI, GPIO19=MISO, GPIO18=SCK
X4 RTD_VL_P/N, X5 RTD_RL_P/N

BUS / SERVICE
J3/J4 YSTY parallel: D+, D-, COM
R3 120R + JP1 1x3: 1-2 Abschluss EIN, 2-3 Park/AUS

SK6812MINI-E | SK6812MINI-E | SK6812MINI-E

Isolationsgrenze im PCB: mindestens 8 mm zwischen MAINS und SELV, Fraesnut/Keepout im Layout.

ESP32 Modbus-RTU-Slave, OTA per WLAN, lokale Mischer-Laufzeitlogik 230 V AC + SELV getrennt; vor Fertigung elektrisch pruefen

Freezweb 100nF 16V

Size: A3 | Rev: A-preliminary | F Date: 2026-06-25
KiCad E.D.A. 10.0.4 | Id: 1/1

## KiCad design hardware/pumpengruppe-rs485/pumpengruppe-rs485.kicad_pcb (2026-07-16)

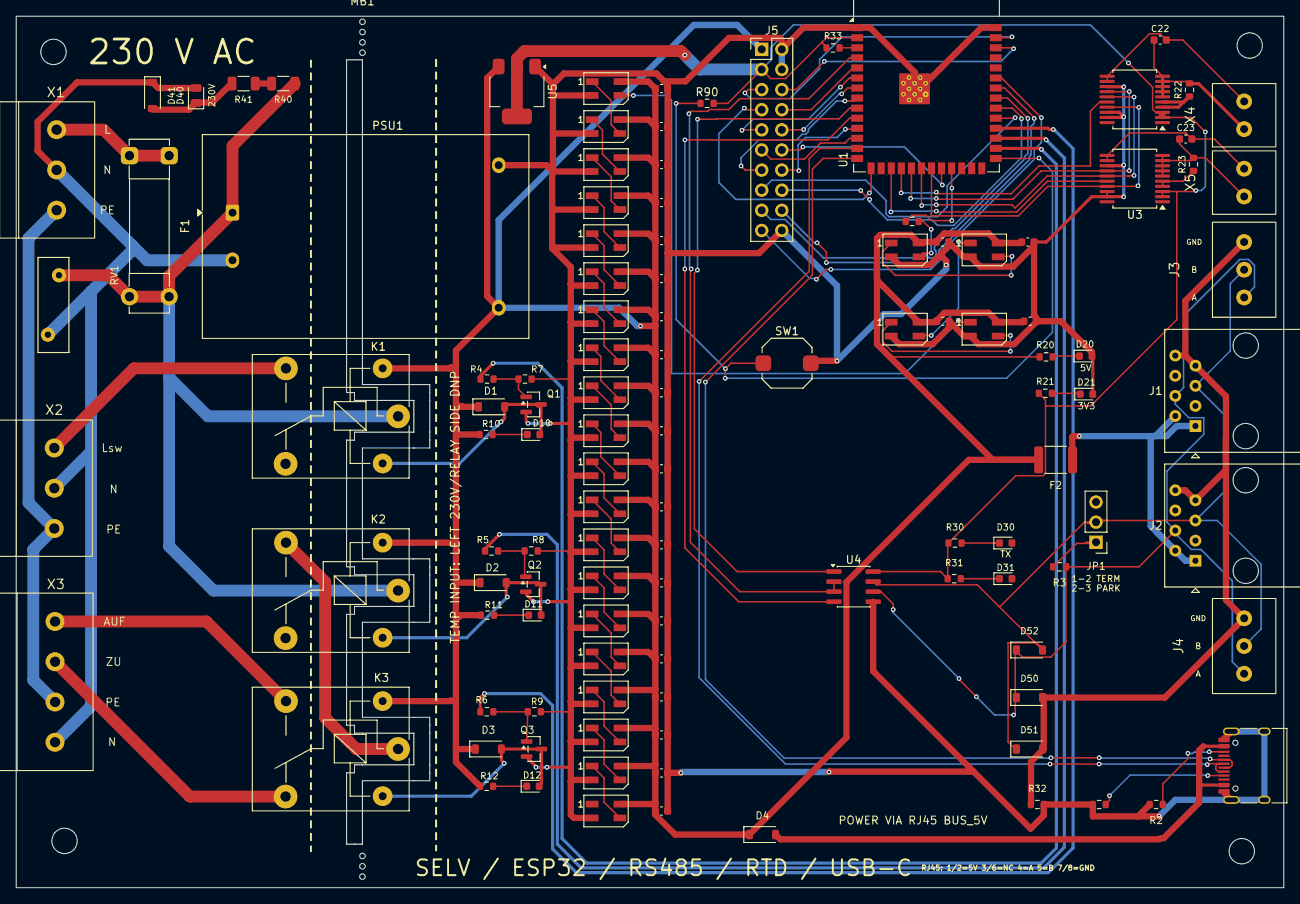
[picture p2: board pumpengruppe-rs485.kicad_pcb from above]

Board: 2 copper layers, 160.0 x 110.0 mm, 123 parts (0 on the bottom side), 95 nets.

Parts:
C22, C23: 10nF 50V; C_0603_1608Metric
C60, C61, C62, C63, C64, C65, C66, C67, C68, C69, C70, C71, C72, C73, C74, C75, C76, C77, C78, C79, C80, C81, C82, C83: 100nF 16V; C_0603_1608Metric
D1, D2, D3, D4: B5819W; D_SOD-123
D10, D11, D12, D20, D21, D30, D31: LED green 0603; LED_0603_1608Metric
D40: LED green 0805; LED_0805_2012Metric
D41: 1N4148W; D_SOD-123
D50, D51, D52: DNP TVS SOD-123; D_SOD-123
D60, D61, D62, D63, D64, D65, D66, D67, D68, D69, D70, D71, D72, D73, D74, D75, D76, D77, D78, D79, D80, D81, D82, D83: SK6812MINI-E; LED_SK6812MINI_PLCC4_3.5x3.5mm_P1.75mm
F1: 2x FC-203-22 fuse clips for 5x20; Fuseholder_Clip-5x20mm_Bel_FC-203-22_Lateral_P17.80x5.00mm_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
F2: PTC 1.1A 1812; Fuse_1812_4532Metric
H1, H2, H3, H4: MountingHole_M3; MountingHole_3.2mm_M3
J1, J2: RJ45 8P8C horizontal; RJ45_Amphenol_54602-x08_Horizontal
J3, J4: KF128L-3.5-3P; TB_KF128L_350_3P
J5: EXT_GPIO_HEADER; PinHeader_2x10_P2.54mm_Vertical
JP1: 1x3 2.54mm header; PinHeader_1x03_P2.54mm_Vertical
K1, K2, K3: SRD-05VDC-SL-C; Relay_SPDT_SANYOU_SRD_Series_Form_C
MB1: BREAKAWAY_MOUSEBITES
PSU1: HLK-5M05; Converter_ACDC_Hi-Link_HLK-5Mxx
Q1, Q2, Q3: AO3400A; SOT-23
R1, R2: 5.1k 1% 0603; R_0603_1608Metric
R3: 120R 1% 0603; R_0603_1608Metric
R4, R5, R6: 100R 1% 0603; R_0603_1608Metric
R7, R8, R9: 100k 1% 0603; R_0603_1608Metric
R10, R11, R12, R20: 2.2k 1% 0603; R_0603_1608Metric
R21: 1.5k 1% 0603; R_0603_1608Metric
R22, R23: 4.3k 0.1% 0603; R_0603_1608Metric
R30, R31: 4.7k 1% 0603; R_0603_1608Metric
R32: 0R 0603; R_0603_1608Metric
R33, R90: 10k 1% 0603; R_0603_1608Metric
R40, R41: 150k 1% 1206; R_1206_3216Metric
R60: 330R 1% 0603; R_0603_1608Metric
RV1: MOV 275VAC; RV_Disc_D12mm_W3.9mm_P7.5mm
SW1: BOOT/CFG RESET; SW_Push_1TS009xxxx-xxxx-xxxx_6x6x5mm
U1: ESP32-S3-WROOM-1-N4; ESP32-S3-WROOM-1
U2, U3: MAX31865AAP+; SSOP-20_5.3x7.2mm_P0.65mm
U4: SP3485EN-L/TR; SOIC-8_3.9x4.9mm_P1.27mm
U5: AMS1117-3.3; SOT-223-3_TabPin2
X1, X2: KF128-5.08-3P-AA; TB_KF128_508_3P
X3: DB128L-5.08-4P-GN-S; TB_DB128L_508_4P
X4, X5: KF128L-3.5-2P; TB_KF128L_350_2P
X6: USB-C receptacle; USB_C_Receptacle_HRO_TYPE-C-31-M-12

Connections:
/+3V3: J5.3, R21.1, R30.1, R31.1, R33.1, R90.2, U1.2, U2.2 (DVDD), U2.3 (VDD), U3.2 (DVDD), U3.3 (VDD), U4.8 (VCC), U5.2 (VO)
/+5V: C60.1, C61.1, C62.1, C63.1, C64.1, C65.1, C66.1, C67.1, C68.1, C69.1, C70.1, C71.1, C72.1, C73.1, C74.1, C75.1, C76.1, C77.1, C78.1, C79.1, C80.1, C81.1, C82.1, C83.1, D1.1 (K), D2.1 (K), D3.1 (K), D4.1 (K), D60.4 (VDD), D61.4 (VDD), D62.4 (VDD), D63.4 (VDD), D64.4 (VDD), D65.4 (VDD), D66.4 (VDD), D67.4 (VDD), D68.4 (VDD), D69.4 (VDD), D70.4 (VDD), D71.4 (VDD), D72.4 (VDD), D73.4 (VDD), D74.4 (VDD), D75.4 (VDD), D76.4 (VDD), D77.4 (VDD), D78.4 (VDD), D79.4 (VDD), D80.4 (VDD), D81.4 (VDD), D82.4 (VDD), D83.4 (VDD), F2.2, J5.1, K1.2, K2.2, K3.2, PSU1.4 (+Vout), R10.1, R11.1, R12.1, R20.1, U5.3 (VI)
/BUS_5V: F2.1, J1.1, J1.2, J2.1, J2.2
/ESP_EN: R33.2, U1.3
/ESP_IO0_BOOT: R90.1, SW1.1, U1.27
/ESP_IO1_EXT: J5.5, U1.39
/ESP_IO2_EXT: J5.6, U1.38
/ESP_IO3_EXT: J5.7, U1.15
/ESP_IO5_EXT: J5.8, U1.5
/ESP_IO6_EXT: J5.9, U1.6
/ESP_IO7_EXT: J5.10, U1.7
/ESP_IO8_EXT: J5.11, U1.12
/ESP_IO14_EXT: J5.12, U1.22
/ESP_IO15_EXT: J5.13, U1.8
/ESP_IO18_EXT: J5.14, U1.11
/ESP_IO38_EXT: J5.15, U1.31
/ESP_IO39_EXT: J5.16, U1.32
/ESP_IO40_EXT: J5.17, U1.33
/ESP_IO41_EXT: J5.18, U1.34
/ESP_IO42_EXT: J5.19, U1.35
/GND: C60.2, C61.2, C62.2, C63.2, C64.2, C65.2, C66.2, C67.2, C68.2, C69.2, C70.2, C71.2, C72.2, C73.2, C74.2, C75.2, C76.2, C77.2, C78.2, C79.2, C80.2, C81.2, C82.2, C83.2, D20.2 (A), D21.2 (A), D60.2 (VSS), D61.2 (VSS), D62.2 (VSS), D63.2 (VSS), D64.2 (VSS), D65.2 (VSS), D66.2 (VSS), D67.2 (VSS), D68.2 (VSS), D69.2 (VSS), D70.2 (VSS), D71.2 (VSS), D72.2 (VSS), D73.2 (VSS), D74.2 (VSS), D75.2 (VSS), D76.2 (VSS), D77.2 (VSS), D78.2 (VSS), D79.2 (VSS), D80.2 (VSS), D81.2 (VSS), D82.2 (VSS), D83.2 (VSS), J5.2, J5.4, J5.20, PSU1.3 (-Vout), Q1.2 (D), Q2.2 (D), Q3.2 (D), R1.2, R2.2, R7.2, R8.2, R9.2, R32.2, SW1.2, U1.1, U1.40, U1.41, U2.13 (GND), U2.18 (DGND), U2.19 (GND), U3.13 (GND), U3.18 (DGND), U3.19 (GND), U4.5 (GND), U5.1 (GND), X6.A1 (GND), X6.A12 (GND), X6.B1 (GND), X6.B12 (GND), X6.SH (SHIELD)
/LED_3V3_K: D21.1 (K), R21.2
/LED_5V_K: D20.1 (K), R20.2
/LED_MIX_DIR_K: D12.1 (K), R12.2
/LED_MIX_ENABLE_K: D11.1 (K), R11.2
/LED_PUMP_K: D10.1 (K), R10.2
/LED_USB_RX_K: D31.1 (K), R31.2
/LED_USB_TX_K: D30.1 (K), R30.2
/L_FUSED: F1.2, K1.1, K2.1, PSU1.1 (AC/L), R40.1, RV1.1
/L_IN: F1.1, X1.1
/L_MIX_CLOSE: K3.4, X3.2
/L_MIX_ENABLE: K2.3, K3.1
/L_MIX_OPEN: K3.3, X3.1
/L_PUMP: K1.3, X2.1
/MAINS_LED_K: D40.1 (K), D41.2 (A), R41.2
/MAINS_LED_SERIES: R40.2, R41.1
/MIX_DIR_COIL_DRV: D3.2 (A), D12.2 (A), K3.5, Q3.3 (S)
/MIX_DIR_DRV: Q3.1 (G), R6.2, R9.1
/MIX_DIR_DRV_GPIO: R6.1, U1.30
/MIX_ENABLE_COIL_DRV: D2.2 (A), D11.2 (A), K2.5, Q2.3 (S)
/MIX_ENABLE_DRV: Q2.1 (G), R5.2, R8.1
/MIX_ENABLE_DRV_GPIO: R5.1, U1.29
/N: D40.2 (A), D41.1 (K), PSU1.2 (AC/N), RV1.2, X1.2, X2.2, X3.4
/PE: X1.3, X2.3, X3.3
/PUMP_COIL_DRV: D1.2 (A), D10.2 (A), K1.5, Q1.3 (S)
/PUMP_DRV: Q1.1 (G), R4.2, R7.1
/PUMP_DRV_GPIO: R4.1, U1.28
/RGB_D60_DIN: D60.3 (DIN), R60.2
/RGB_D60_DOUT: D60.1 (DOUT), D61.3 (DIN)
/RGB_D61_DOUT: D61.1 (DOUT), D62.3 (DIN)
/RGB_D62_DOUT: D62.1 (DOUT), D63.3 (DIN)
/RGB_D63_DOUT: D63.1 (DOUT), D64.3 (DIN)
/RGB_D64_DOUT: D64.1 (DOUT), D65.3 (DIN)
/RGB_D65_DOUT: D65.1 (DOUT), D66.3 (DIN)
/RGB_D66_DOUT: D66.1 (DOUT), D67.3 (DIN)
/RGB_D67_DOUT: D67.1 (DOUT), D68.3 (DIN)
/RGB_D68_DOUT: D68.1 (DOUT), D69.3 (DIN)
/RGB_D69_DOUT: D69.1 (DOUT), D70.3 (DIN)
/RGB_D70_DOUT: D70.1 (DOUT), D71.3 (DIN)
/RGB_D71_DOUT: D71.1 (DOUT), D72.3 (DIN)
/RGB_D72_DOUT: D72.1 (DOUT), D73.3 (DIN)
/RGB_D73_DOUT: D73.1 (DOUT), D74.3 (DIN)
/RGB_D74_DOUT: D74.1 (DOUT), D75.3 (DIN)
/RGB_D75_DOUT: D75.1 (DOUT), D76.3 (DIN)
/RGB_D76_DOUT: D76.1 (DOUT), D77.3 (DIN)
/RGB_D77_DOUT: D77.1 (DOUT), D78.3 (DIN)
/RGB_D78_DOUT: D78.1 (DOUT), D79.3 (DIN)
/RGB_D79_DOUT: D79.1 (DOUT), D80.3 (DIN)
/RGB_D80_DOUT: D80.1 (DOUT), D81.3 (DIN)
/RGB_D81_DOUT: D81.1 (DOUT), D82.3 (DIN)
/RGB_D82_DOUT: D82.1 (DOUT), D83.3 (DIN)
/RGB_DATA: R60.1, U1.23
/RS485_A: D50.1 (A1), D52.1 (A1), J1.4, J2.4, J3.1, J4.1, R3.1, U4.6 (A)
/RS485_B: D51.1 (A1), D52.2 (A2), J1.5, J2.5, J3.2, J4.2, JP1.2, U4.7 (B)
/RS485_DE: U1.4, U4.2 (~RE), U4.3 (DE)
/RS485_GND: D50.2 (A2), D51.2 (A2), J1.7, J1.8, J2.7, J2.8, J3.3, J4.3, R32.1
/RS485_TERM: JP1.1, R3.2
/RS485_UART_RX: U1.9, U4.1 (RO)
/RS485_UART_TX: U1.10, U4.4 (DI)
/RTD_RL_BIAS: R23.1, U3.4 (BIAS), U3.5 (REFIN+)
/RTD_RL_CS: U1.17, U3.16 (~CS)
/RTD_RL_FORCE_MINUS: C23.2, U3.11 (RTDIN-), U3.12 (FORCE-), X5.2
/RTD_RL_FORCE_PLUS: C23.1, R23.2, U3.6 (REFIN-), U3.7 (ISENSOR), U3.8 (FORCE+), U3.9 (FORCE2), U3.10 (RTDIN+), X5.1
/RTD_VL_BIAS: R22.1, U2.4 (BIAS), U2.5 (REFIN+)
/RTD_VL_CS: U1.18, U2.16 (~CS)
/RTD_VL_FORCE_MINUS: C22.2, U2.11 (RTDIN-), U2.12 (FORCE-), X4.2
/RTD_VL_FORCE_PLUS: C22.1, R22.2, U2.6 (REFIN-), U2.7 (ISENSOR), U2.8 (FORCE+), U2.9 (FORCE2), U2.10 (RTDIN+), X4.1
/SPI_MISO: U1.21, U2.17 (SDO), U3.17 (SDO)
/SPI_MOSI: U1.19, U2.14 (SDI), U3.14 (SDI)
/SPI_SCK: U1.20, U2.15 (SCLK), U3.15 (SCLK)
/USB_CC1: R1.1, X6.A5 (CC1)
/USB_CC2: R2.1, X6.B5 (CC2)
/USB_D+: U1.14, X6.A6 (D+), X6.B6 (D+)
/USB_D-: U1.13, X6.A7 (D-), X6.B7 (D-)
/USB_VBUS: D4.2 (A), X6.A4 (VBUS), X6.A9 (VBUS), X6.B4 (VBUS), X6.B9 (VBUS)

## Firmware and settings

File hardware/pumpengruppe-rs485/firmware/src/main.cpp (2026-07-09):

#include <Arduino.h>
#include <ArduinoOTA.h>
#include <DNSServer.h>
#include <ESPmDNS.h>
#include <Preferences.h>
#include <PubSubClient.h>
#include <Update.h>
#include <WebServer.h>
#include <WiFi.h>
#include <Adafruit_MAX31865.h>
#include <Adafruit_NeoPixel.h>

#ifndef FW_NAME
#define FW_NAME "pumpengruppe-rs485"
#endif

#ifndef FW_VERSION
#define FW_VERSION "0.1.0"
#endif

static constexpr uint16_t FW_VERSION_BCD = 0x0020;
static constexpr uint16_t DNS_PORT = 53;
static constexpr uint32_t POSITION_SAVE_INTERVAL_MS = 30000;
static constexpr uint32_t WIFI_CONNECT_TIMEOUT_MS = 15000;
static constexpr uint32_t MODBUS_SILENCE_US = 4000;
static constexpr uint32_t HARDWARE_POLL_INTERVAL_MS = 1000;
static constexpr uint32_t CONFIG_RESET_HOLD_MS = 10000;
static constexpr uint8_t MQTT_PUBLISH_CACHE_SIZE = 32;
static constexpr float RTD_RREF_PT1000 = 4300.0f;
static constexpr float RTD_RREF_PT100 = 430.0f;
static constexpr float RTD_RNOMINAL_PT1000 = 1000.0f;
static constexpr float RTD_RNOMINAL_PT100 = 100.0f;

namespace HwPin {
static constexpr uint8_t RS485_RX = 16;
static constexpr uint8_t RS485_TX = 17;
static constexpr uint8_t RS485_DE = 4;
static constexpr uint8_t PUMP_DRV = 35;
static constexpr uint8_t MIX_ENABLE_DRV = 36;
static constexpr uint8_t MIX_DIR_DRV = 37;
static constexpr uint8_t RGB_DATA = 21;
static constexpr uint8_t RGB_COUNT = 24;
static constexpr uint8_t SPI_MOSI = 11;
static constexpr uint8_t SPI_MISO = 13;
static constexpr uint8_t SPI_SCK = 12;
static constexpr uint8_t RTD_VL_CS = 10;
static constexpr uint8_t RTD_RL_CS = 9;
static constexpr uint8_t CONFIG_RESET_BTN = 0;
}

enum Mode : uint16_t {
  MODE_AUTO = 0,
  MODE_HAND = 1,
  MODE_CAL_CLOSE = 2,
  MODE_CAL_OPEN = 3,
};

enum FaultCode : uint16_t {
  FAULT_OK = 0,
  FAULT_MODBUS_WATCHDOG = 1,
  FAULT_VL_SENSOR = 2,
  FAULT_RL_SENSOR = 3,
  FAULT_RELAY_CONFLICT = 4,
  FAULT_CALIBRATION_MISSING = 5,
  FAULT_RELAY_DIAG = 6,
};

enum ParityMode : uint8_t {
  PARITY_8N1 = 0,
  PARITY_8E1 = 1,
  PARITY_8O1 = 2,
};

enum RtdType : uint16_t {
  RTD_PT1000 = 0,
  RTD_PT100 = 1,
};

struct Config {
  char wifiSsid[33] = "";
  char wifiPass[65] = "";
  char hostname[33] = "pumpengruppe-rs485";
  char adminPass[33] = "admin";
  uint8_t slaveId = 30;
  uint32_t baud = 9600;
  ParityMode parity = PARITY_8N1;
  uint16_t watchdogTimeoutS = 60;
  uint16_t mixerRuntimeS = 120;
  uint16_t endstopOverrunS = 5;
  RtdType rtdType = RTD_PT1000;
  uint16_t failsafePump = 0;
  bool modbusTcpEnabled = true;
  uint16_t modbusTcpPort = 502;
  bool mqttEnabled = false;
  char mqttHost[65] = "";
  uint16_t mqttPort = 1883;
  char mqttUser[33] = "";
  char mqttPass[65] = "";
  char mqttBase[65] = "";
  uint16_t mqttPublishIntervalS = 5;
};

struct RuntimeState {
  uint16_t commandSeq = 0;
  bool pumpRequested = false;
  bool pumpOn = false;
  int16_t targetPctX10 = 0;
  int16_t positionPctX10 = 0;
  Mode mode = MODE_AUTO;
  bool moving = false;
  int8_t moveDirection = 0;
  uint32_t moveStartMs = 0;
  uint32_t moveDurationMs = 0;
  int16_t moveStartPctX10 = 0;
  uint16_t lastCommandSeq = 0;
  FaultCode faultCode = FAULT_OK;
  int16_t vlTempX10 = 315;
  int16_t rlTempX10 = 285;
  uint32_t lastModbusMs = 0;
  uint32_t lastPositionSaveMs = 0;
  uint32_t txCount = 0;
  uint32_t rxCount = 0;
  uint32_t crcErrorCount = 0;
  bool wifiApMode = false;
  bool rtdVlOk = false;
  bool rtdRlOk = false;
  uint8_t rtdVlFault = 0;
  uint8_t rtdRlFault = 0;
  bool rgbConfigured = false;
  bool rs485Configured = false;
  bool relaysConfigured = false;
  bool mqttConfigured = false;
  uint32_t mqttRxCount = 0;
  uint32_t mqttTxCount = 0;
  uint32_t lastMqttMs = 0;
};

struct MqttPublishCacheEntry {
  String topic;
  String payload;
  bool valid = false;
};

Config cfg;
RuntimeState st;
Preferences prefs;
WebServer server(80);
DNSServer dnsServer;
HardwareSerial rs485(2);
Adafruit_NeoPixel *pixels = nullptr;
Adafruit_MAX31865 rtdVl(HwPin::RTD_VL_CS, HwPin::SPI_MOSI, HwPin::SPI_MISO, HwPin::SPI_SCK);
Adafruit_MAX31865 rtdRl(HwPin::RTD_RL_CS, HwPin::SPI_MOSI, HwPin::SPI_MISO, HwPin::SPI_SCK);
WiFiServer *modbusTcpServer = nullptr;
WiFiClient modbusTcpClients[4];
WiFiClient mqttWifiClient;
PubSubClient mqttClient(mqttWifiClient);

static uint16_t holding[9] = {};
static uint16_t inputRegs[9] = {};
static uint8_t mbBuf[256] = {};
static size_t mbLen = 0;
static uint32_t lastMbByteUs = 0;
static uint32_t rebootAtMs = 0;
static uint32_t lastMqttConnectAttemptMs = 0;
static uint32_t lastMqttPublishMs = 0;
static uint32_t lastMqttHintsPublishMs = 0;
static uint32_t lastMqttSubscribeMs = 0;
static uint32_t lastMqttHeartbeatMs = 0;
static bool mqttStateDirty = true;
static uint32_t configResetPressedSinceMs = 0;
static bool configResetTriggered = false;
static String lastMqttStateDigest;
static MqttPublishCacheEntry mqttPublishCache[MQTT_PUBLISH_CACHE_SIZE];

static String mqttBaseTopic();
static void setupMqtt();
static void setupModbusTcp();

template <typename T>
static T clampValue(T value, T minValue, T maxValue) {
  if (value < minValue) return minValue;
  if (value > maxValue) return maxValue;
  return value;
}

static String htmlEscape(const String &in) {
  String out;
  out.reserve(in.length());
  for (char c : in) {
    switch (c) {
    case '&': out += F("&amp;"); break;
    case '<': out += F("&lt;"); break;
    case '>': out += F("&gt;"); break;
    case '"': out += F("&quot;"); break;
    default: out += c; break;
    }
  }
  return out;
}

static void copyString(char *dst, size_t len, const String &value) {
  String trimmed = value;
  trimmed.trim();
  strlcpy(dst, trimmed.c_str(), len);
}

static uint32_t serialConfig() {
  if (cfg.parity == PARITY_8E1) return SERIAL_8E1;
  if (cfg.parity == PARITY_8O1) return SERIAL_8O1;
  return SERIAL_8N1;
}

static const char *parityName(ParityMode parity) {
  switch (parity) {
  case PARITY_8E1: return "8E1";
  case PARITY_8O1: return "8O1";
  default: return "8N1";
  }
}

static String chipSuffix() {
  uint64_t mac = ESP.getEfuseMac();
  char buf[7];
  snprintf(buf, sizeof(buf), "%06X", static_cast<uint32_t>(mac & 0xFFFFFF));
  return String(buf);
}

static bool isAuthenticated() {
  return server.authenticate("admin", cfg.adminPass);
}

static bool requireAuth() {
  if (st.wifiApMode) return true;
  if (isAuthenticated()) return true;
  server.requestAuthentication();
  return false;
}

static void saveConfig() {
  prefs.begin("pumpgrp", false);
  prefs.putString("wifiSsid", cfg.wifiSsid);
  prefs.putString("wifiPass", cfg.wifiPass);
  prefs.putString("hostname", cfg.hostname);
  prefs.putString("adminPass", cfg.adminPass);
  prefs.putUChar("slaveId", cfg.slaveId);
  prefs.putUInt("baud", cfg.baud);
  prefs.putUChar("parity", cfg.parity);
  prefs.putUShort("wdS", cfg.watchdogTimeoutS);
  prefs.putUShort("runS", cfg.mixerRuntimeS);
  prefs.putUShort("overS", cfg.endstopOverrunS);
  prefs.putUShort("rtdType", cfg.rtdType);
  prefs.putUShort("failPump", cfg.failsafePump);
  prefs.putBool("mbTcpEn", cfg.modbusTcpEnabled);
  prefs.putUShort("mbTcpPort", cfg.modbusTcpPort);
  prefs.putBool("mqttEn", cfg.mqttEnabled);
  prefs.putString("mqttHost", cfg.mqttHost);
  prefs.putUShort("mqttPort", cfg.mqttPort);
  prefs.putString("mqttUser", cfg.mqttUser);
  prefs.putString("mqttPass", cfg.mqttPass);
  prefs.putString("mqttBase", cfg.mqttBase);
  prefs.putUShort("mqttPubS", cfg.mqttPublishIntervalS);
  prefs.putShort("pos", st.positionPctX10);
  prefs.end();
}

static String prefStringOrDefault(const char *key, const char *fallback) {
  if (!prefs.isKey(key)) return String(fallback);
  return prefs.getString(key, fallback);
}

static void loadConfig() {
  prefs.begin("pumpgrp", true);
  copyString(cfg.wifiSsid, sizeof(cfg.wifiSsid), prefStringOrDefault("wifiSsid", cfg.wifiSsid));
  copyString(cfg.wifiPass, sizeof(cfg.wifiPass), prefStringOrDefault("wifiPass", cfg.wifiPass));
  copyString(cfg.hostname, sizeof(cfg.hostname), prefStringOrDefault("hostname", cfg.hostname));
  copyString(cfg.adminPass, sizeof(cfg.adminPass), prefStringOrDefault("adminPass", cfg.adminPass));
  cfg.slaveId = prefs.getUChar("slaveId", cfg.slaveId);
  cfg.baud = prefs.getUInt("baud", cfg.baud);
  cfg.parity = static_cast<ParityMode>(prefs.getUChar("parity", cfg.parity));
  cfg.watchdogTimeoutS = prefs.getUShort("wdS", cfg.watchdogTimeoutS);
  cfg.mixerRuntimeS = prefs.getUShort("runS", cfg.mixerRuntimeS);
  cfg.endstopOverrunS = prefs.getUShort("overS", cfg.endstopOverrunS);
  cfg.rtdType = static_cast<RtdType>(prefs.getUShort("rtdType", cfg.rtdType));
  cfg.failsafePump = prefs.getUShort("failPump", cfg.failsafePump);
  cfg.modbusTcpEnabled = prefs.getBool("mbTcpEn", cfg.modbusTcpEnabled);
  cfg.modbusTcpPort = prefs.getUShort("mbTcpPort", cfg.modbusTcpPort);
  cfg.mqttEnabled = prefs.getBool("mqttEn", cfg.mqttEnabled);
  copyString(cfg.mqttHost, sizeof(cfg.mqttHost), prefStringOrDefault("mqttHost", cfg.mqttHost));
  cfg.mqttPort = prefs.getUShort("mqttPort", cfg.mqttPort);
  copyString(cfg.mqttUser, sizeof(cfg.mqttUser), prefStringOrDefault("mqttUser", cfg.mqttUser));
  copyString(cfg.mqttPass, sizeof(cfg.mqttPass), prefStringOrDefault("mqttPass", cfg.mqttPass));
  copyString(cfg.mqttBase, sizeof(cfg.mqttBase), prefStringOrDefault("mqttBase", cfg.mqttBase));
  cfg.mqttPublishIntervalS = prefs.getUShort("mqttPubS", cfg.mqttPublishIntervalS);
  st.positionPctX10 = prefs.getShort("pos", 0);
  prefs.end();
}

static void initHoldingFromConfig() {
  holding[0] = st.commandSeq;
  holding[1] = st.pumpRequested ? 1 : 0;
  holding[2] = static_cast<uint16_t>(st.targetPctX10);
  holding[3] = st.mode;
  holding[4] = cfg.watchdogTimeoutS;
  holding[5] = cfg.mixerRuntimeS;
  holding[6] = cfg.endstopOverrunS;
  holding[7] = cfg.rtdType;
  holding[8] = cfg.failsafePump;
}

static void applyOutputs() {
  digitalWrite(HwPin::PUMP_DRV, st.pumpOn ? HIGH : LOW);
  digitalWrite(HwPin::MIX_DIR_DRV, st.moveDirection > 0 ? HIGH : LOW);
  digitalWrite(HwPin::MIX_ENABLE_DRV, st.moving ? HIGH : LOW);
}

static void allOutputsOff() {
  st.pumpOn = false;
  st.moving = false;
  st.moveDirection = 0;
  applyOutputs();
}

static void clearStoredConfigAndRestart() {
  allOutputsOff();
  prefs.begin("pumpgrp", false);
  prefs.clear();
  prefs.end();
  Serial.println("BOOT/CFG RESET: Konfiguration geloescht, Neustart folgt.");
  rebootAtMs = millis() + 500;
}

static void pollConfigResetButton() {
  const bool pressed = digitalRead(HwPin::CONFIG_RESET_BTN) == LOW;
  if (!pressed) {
    configResetPressedSinceMs = 0;
    configResetTriggered = false;
    return;
  }

  if (configResetPressedSinceMs == 0) {
    configResetPressedSinceMs = millis();
    return;
  }

  if (!configResetTriggered && millis() - configResetPressedSinceMs >= CONFIG_RESET_HOLD_MS) {
    configResetTriggered = true;
    clearStoredConfigAndRestart();
  }
}

static void updateInputRegisters() {
  uint16_t status = 0;
  status |= 1U << 0;
  if (st.faultCode != FAULT_OK) status |= 1U << 1;
  if (st.moving) status |= 1U << 2;
  if (st.pumpOn) status |= 1U << 3;
  if (st.moving && st.moveDirection > 0) status |= 1U << 4;
  if (st.moving && st.moveDirection < 0) status |= 1U << 5;
  inputRegs[0] = status;
  inputRegs[1] = static_cast<uint16_t>(st.positionPctX10);
  inputRegs[2] = static_cast<uint16_t>(st.vlTempX10);
  inputRegs[3] = static_cast<uint16_t>(st.rlTempX10);
  inputRegs[4] = st.lastCommandSeq;
  inputRegs[5] = st.faultCode;
  uint32_t uptime = millis() / 1000;
  inputRegs[6] = uptime & 0xFFFF;
  inputRegs[7] = uptime >> 16;
  inputRegs[8] = FW_VERSION_BCD;
}

static void configurePixels() {
  if (pixels) {
    delete pixels;
    pixels = nullptr;
  }
  pixels = new Adafruit_NeoPixel(HwPin::RGB_COUNT, HwPin::RGB_DATA, NEO_GRB + NEO_KHZ800);
  pixels->begin();
  pixels->clear();
  pixels->show();
  st.rgbConfigured = true;
}

static uint32_t rgb(uint8_t r, uint8_t g, uint8_t b) {
  return pixels ? pixels->Color(r, g, b) : 0;
}

static void updatePixels() {
  if (!pixels) return;
  pixels->clear();

  uint32_t wifiColor = WiFi.status() == WL_CONNECTED ? rgb(0, 32, 0) : rgb(32, 16, 0);
  uint32_t busColor = (millis() - st.lastModbusMs < 5000) ? rgb(0, 0, 32) : rgb(16, 16, 16);
  uint32_t faultColor = st.faultCode == FAULT_OK ? rgb(0, 12, 0) : rgb(48, 0, 0);
  uint32_t pumpColor = st.pumpOn ? rgb(0, 32, 0) : rgb(4, 4, 4);

  if (HwPin::RGB_COUNT > 0) pixels->setPixelColor(0, wifiColor);
  if (HwPin::RGB_COUNT > 1) pixels->setPixelColor(1, busColor);
  if (HwPin::RGB_COUNT > 2) pixels->setPixelColor(2, faultColor);
  if (HwPin::RGB_COUNT > 3) pixels->setPixelColor(3, pumpColor);

  int lit = map(clampValue<int16_t>(st.positionPctX10, 0, 1000), 0, 1000, 0, 20);
  for (int i = 0; i < 20 && (4 + i) < HwPin::RGB_COUNT; i++) {
    pixels->setPixelColor(4 + i, i < lit ? rgb(0, 0, 36) : rgb(2, 2, 2));
  }
  pixels->show();
}

static void startMoveTo(int16_t targetPctX10) {
  targetPctX10 = clampValue<int16_t>(targetPctX10, 0, 1000);
  int16_t delta = targetPctX10 - st.positionPctX10;
  if (abs(delta) < 2) {
    st.targetPctX10 = targetPctX10;
    st.positionPctX10 = targetPctX10;
    st.moving = false;
    st.moveDirection = 0;
    applyOutputs();
    return;
  }

  st.targetPctX10 = targetPctX10;
  st.moveDirection = delta > 0 ? 1 : -1;
  st.moveStartPctX10 = st.positionPctX10;
  st.moveStartMs = millis();
  uint32_t baseMs = static_cast<uint32_t>(abs(delta)) * cfg.mixerRuntimeS;
  if (targetPctX10 == 0 || targetPctX10 == 1000 || st.mode == MODE_CAL_CLOSE || st.mode == MODE_CAL_OPEN) {
    baseMs += static_cast<uint32_t>(cfg.endstopOverrunS) * 1000UL;
  }
  st.moveDurationMs = max<uint32_t>(baseMs, 200);
  st.moving = true;
  applyOutputs();
}

static void applyCommandRegisters() {
  cfg.watchdogTimeoutS = clampValue<uint16_t>(holding[4], 1, 600);
  cfg.mixerRuntimeS = clampValue<uint16_t>(holding[5], 5, 1000);
  cfg.endstopOverrunS = clampValue<uint16_t>(holding[6], 0, 120);
  cfg.rtdType = holding[7] == 1 ? RTD_PT100 : RTD_PT1000;
  cfg.failsafePump = holding[8] ? 1 : 0;

  st.pumpRequested = holding[1] != 0;
  st.mode = static_cast<Mode>(holding[3]);
  int16_t target = clampValue<int16_t>(static_cast<int16_t>(holding[2]), 0, 1000);

  if (st.mode == MODE_CAL_CLOSE) target = 0;
  if (st.mode == MODE_CAL_OPEN) target = 1000;

  if (holding[0] != st.lastCommandSeq || target != st.targetPctX10 || st.mode == MODE_CAL_CLOSE || st.mode == MODE_CAL_OPEN) {
    st.lastCommandSeq = holding[0];
    Serial.printf("Command seq=%u pump=%u target=%.1f%% mode=%u\n",
                  st.lastCommandSeq,
                  st.pumpRequested ? 1 : 0,
                  target / 10.0f,
                  static_cast<unsigned>(st.mode));
    startMoveTo(target);
    mqttStateDirty = true;
  }
}

static void applyExternalCommand(bool hasPump, bool pumpOn, bool hasTarget, int16_t targetPctX10, Mode mode, const char *source) {
  if (hasPump) {
    st.pumpRequested = pumpOn;
    holding[1] = st.pumpRequested ? 1 : 0;
  }
  if (hasTarget) {
    st.commandSeq++;
    holding[0] = st.commandSeq;
    holding[2] = clampValue<int16_t>(targetPctX10, 0, 1000);
    holding[3] = mode;
  }
  st.lastModbusMs = millis();
  Serial.printf("%s command pump=%u target=%s%.1f%% seq=%u\n",
                source,
                st.pumpRequested ? 1 : 0,
                hasTarget ? "" : "(unchanged) ",
                hasTarget ? holding[2] / 10.0f : st.targetPctX10 / 10.0f,
                st.commandSeq);
  applyCommandRegisters();
  mqttStateDirty = true;
}

static void updateMotion() {
  if (!st.moving) return;
  uint32_t elapsed = millis() - st.moveStartMs;
  if (elapsed >= st.moveDurationMs) {
    st.positionPctX10 = st.targetPctX10;
    if (st.mode == MODE_CAL_CLOSE) st.positionPctX10 = 0;
    if (st.mode == MODE_CAL_OPEN) st.positionPctX10 = 1000;
    st.moving = false;
    st.moveDirection = 0;
    applyOutputs();
    return;
  }
  int32_t travel = static_cast<int32_t>(elapsed) * 1000L / max<uint32_t>(1, cfg.mixerRuntimeS * 1000UL);
  st.positionPctX10 = clampValue<int16_t>(st.moveStartPctX10 + st.moveDirection * travel, 0, 1000);
}

static void updateTemperatures() {
  static uint32_t lastMs = 0;
  if (millis() - lastMs < 1000) return;
  lastMs = millis();
  float t = millis() / 1000.0f;
  st.vlTempX10 = 320 + static_cast<int16_t>(20.0f * sinf(t / 15.0f));
  st.rlTempX10 = 285 + static_cast<int16_t>(15.0f * sinf(t / 18.0f));
}

static void updateWatchdog() {
  bool watchdogExpired = st.lastModbusMs > 0 && (millis() - st.lastModbusMs > static_cast<uint32_t>(cfg.watchdogTimeoutS) * 1000UL);
  if (watchdogExpired) {
    st.faultCode = FAULT_MODBUS_WATCHDOG;
    st.pumpOn = cfg.failsafePump != 0;
    st.moving = false;
    st.moveDirection = 0;
  } else if (st.faultCode == FAULT_MODBUS_WATCHDOG) {
    st.faultCode = FAULT_OK;
  }
  if (!watchdogExpired) st.pumpOn = st.pumpRequested;
  applyOutputs();
}

static void maybeSavePosition() {
  if (millis() - st.lastPositionSaveMs < POSITION_SAVE_INTERVAL_MS) return;
  st.lastPositionSaveMs = millis();
  prefs.begin("pumpgrp", false);
  prefs.putShort("pos", st.positionPctX10);
  prefs.end();
}

static uint16_t modbusCrc(const uint8_t *data, size_t len) {
  uint16_t crc = 0xFFFF;
  for (size_t i = 0; i < len; i++) {
    crc ^= data[i];
    for (uint8_t bit = 0; bit < 8; bit++) {
      crc = (crc & 1) ? (crc >> 1) ^ 0xA001 : crc >> 1;
    }
  }
  return crc;
}

static void rs485Send(const uint8_t *data, size_t len) {
  digitalWrite(HwPin::RS485_DE, HIGH);
  delayMicroseconds(50);
  rs485.write(data, len);
  rs485.flush();
  delayMicroseconds(100);
  digitalWrite(HwPin::RS485_DE, LOW);
  st.txCount++;
}

static void sendException(uint8_t id, uint8_t fn, uint8_t code) {
  uint8_t frame[5] = {id, static_cast<uint8_t>(fn | 0x80), code, 0, 0};
  uint16_t crc = modbusCrc(frame, 3);
  frame[3] = crc & 0xFF;
  frame[4] = crc >> 8;
  rs485Send(frame, sizeof(frame));
}

static void handleReadRegs(uint8_t id, uint8_t fn, const uint8_t *req, const uint16_t *regs, uint16_t regCount) {
  uint16_t start = (req[2] << 8) | req[3];
  uint16_t qty = (req[4] << 8) | req[5];
  if (qty < 1 || qty > 60 || start + qty > regCount) {
    sendException(id, fn, 0x02);
    return;
  }
  uint8_t resp[128] = {};
  resp[0] = id;
  resp[1] = fn;
  resp[2] = qty * 2;
  for (uint16_t i = 0; i < qty; i++) {
    uint16_t v = regs[start + i];
    resp[3 + i * 2] = v >> 8;
    resp[4 + i * 2] = v & 0xFF;
  }
  uint16_t len = 3 + qty * 2;
  uint16_t crc = modbusCrc(resp, len);
  resp[len++] = crc & 0xFF;
  resp[len++] = crc >> 8;
  rs485Send(resp, len);
}

static void handleWriteSingle(uint8_t id, const uint8_t *req) {
  uint16_t addr = (req[2] << 8) | req[3];
  uint16_t value = (req[4] << 8) | req[5];
  if (addr >= 9) {
    sendException(id, 0x06, 0x02);
    return;
  }
  holding[addr] = value;
  Serial.printf("Modbus RTU write single addr=%u value=%u\n", addr, value);
  applyCommandRegisters();
  rs485Send(req, 8);
}

static void handleWriteMultiple(uint8_t id, const uint8_t *req, size_t len) {
  uint16_t start = (req[2] << 8) | req[3];
  uint16_t qty = (req[4] << 8) | req[5];
  uint8_t byteCount = req[6];
  if (qty < 1 || qty > 9 || start + qty > 9 || byteCount != qty * 2 || len < static_cast<size_t>(9 + byteCount)) {
    sendException(id, 0x10, 0x02);
    return;
  }
  for (uint16_t i = 0; i < qty; i++) {
    holding[start + i] = (req[7 + i * 2] << 8) | req[8 + i * 2];
  }
  Serial.printf("Modbus RTU write multiple start=%u qty=%u targetReg=%u seq=%u\n",
                start, qty, holding[2], holding[0]);
  applyCommandRegisters();
  uint8_t resp[8] = {id, 0x10, req[2], req[3], req[4], req[5], 0, 0};
  uint16_t crc = modbusCrc(resp, 6);
  resp[6] = crc & 0xFF;
  resp[7] = crc >> 8;
  rs485Send(resp, sizeof(resp));
}
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
void loop() {
  pollConfigResetButton();
  server.handleClient();
  if (st.wifiApMode) dnsServer.processNextRequest();
  ArduinoOTA.handle();
  pollMqtt();
  pollModbus();
  pollModbusTcp();
  pollMqtt();
  updateTemperatures();
  updateMotion();
  updateWatchdog();
  updateInputRegisters();
  updatePixels();
  maybeSavePosition();
  if (rebootAtMs && millis() > rebootAtMs) {
    allOutputsOff();
    delay(50);
    ESP.restart();
  }
}

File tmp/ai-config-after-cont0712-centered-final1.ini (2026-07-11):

[TakeImage]
;RawImagesLocation = undefined
;RawImagesRetention = 
WaitBeforeTakingPicture = 5
CamGainceiling = x8
CamQuality = 10
CamBrightness = 0
CamContrast = 0
CamSaturation = 0
CamSharpness = 0
CamAutoSharpness = false
CamSpecialEffect = no_effect
CamWbMode = auto
CamAwb = true
CamAwbGain = true
CamAec = true
CamAec2 = true
CamAeLevel = 2
CamAecValue = 600
CamAgc = true
CamAgcGain = 8
CamBpc = true
CamWpc = true
CamRawGma = true
CamLenc = true
CamHmirror = false
CamVflip = false
CamDcw = true
CamDenoise = 0
CamZoom = false
CamZoomOffsetX = 0
CamZoomOffsetY = 0
CamZoomSize = 0
LEDIntensity = 40
Demo = false

[Alignment]
InitialRotate = -6.0
SearchFieldX = 20
SearchFieldY = 20
AlignmentAlgo = Off

/config/ref0.jpg 248 37
/config/ref1.jpg 452 303
[Digits]
Model = /config/dig-cont_0712_s3_q.tflite
;CNNGoodThreshold = 
;ROIImagesLocation = undefined
;ROIImagesRetention = 
zaehlerstand.dig 248 98 27 45 0
zaehlerstand.dig2 287 98 28 45 0
zaehlerstand.dig3 327 98 29 45 0
zaehlerstand.dig4 362 98 34 45 0
zaehlerstand.dig5 400 98 32 45 0

[Analog]
Model = /config/ana-cont_1500_s2_q.tflite
;ROIImagesLocation = undefined
;ROIImagesRetention = 
zaehlerstand.ana1 436 190 58 58 false
zaehlerstand.ana2 399 266 58 58 false
zaehlerstand.ana3 323 292 58 58 false
zaehlerstand.ana4 227 257 58 58 false

[PostProcessing]
zaehlerstand.DecimalShift = 0
zaehlerstand.AnalogToDigitTransitionStart = 9.2
zaehlerstand.ChangeRateThreshold = 2
PreValueUse = true
;PreValueAgeStartup = 
zaehlerstand.AllowNegativeRates = false
zaehlerstand.MaxRateValue = 0.05
;zaehlerstand.MaxRateType = RateChange
zaehlerstand.ExtendedResolution = false
zaehlerstand.IgnoreLeadingNaN = false
ErrorMessage = false
zaehlerstand.CheckDigitIncreaseConsistency = false

;[MQTT]
Uri = mqtt://mqtt.esrv.center:1883
MainTopic = watermeter
ClientID = watermeter
user = vbnet
password = vbnet
RetainMessages = true
;DomoticzTopicIn = undefined
;zaehlerstand.DomoticzIDX = undefined
HomeassistantDiscovery = false
MeterType = water_m3
;CACert = undefined
;ClientCert = undefined
;ClientKey = undefined
;ValidateServerCert = true

;[InfluxDB]
;Uri = undefined
;Database = undefined
;user = undefined
;password = undefined
;zaehlerstand.Measurement = undefined
;zaehlerstand.Field = undefined

;[InfluxDBv2]
;Uri = undefined
;Bucket = undefined
;Org = undefined
;Token = undefined
;zaehlerstand.Measurement = undefined
;zaehlerstand.Field = undefined

;[Webhook]
;Uri = undefined
;ApiKey = undefined
;UploadImg = 0

;[GPIO]
;IO0 = input disabled false false  
;IO1 = input disabled false false  
;IO3 = input disabled false false  
;IO4 = input disabled false false  
;IO12 = input disabled false false  
;IO13 = input disabled false false  
LEDType = WS2812
LEDNumbers = 2
LEDColor = 50 50 50

[AutoTimer]
AutoStart = false
Interval = 5

;[DataLogging]
DataLog

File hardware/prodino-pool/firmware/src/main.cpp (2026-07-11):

#include <Arduino.h>
#include <Ethernet.h>

static constexpr uint16_t MODBUS_PORT = 502;
static constexpr uint16_t FIRMWARE_VERSION = 2;
static constexpr unsigned long COMMAND_TIMEOUT_MS = 120000;

// KMP ProDino MKR Zero Ethernet V1 pinout.
// We use the pins directly because the upstream PlatformIO package currently
// pulls unrelated legacy KMP libraries into the build.
static constexpr uint8_t RELAY_PINS[4] = {21, 20, 19, 18};
static constexpr uint8_t OPTO_INPUT_PINS[4] = {16, 7, 0, 1};
static constexpr uint8_t STATUS_LED_PIN = 6;
static constexpr uint8_t W5500_RESET_PIN = 5;
static constexpr uint8_t W5500_CS_PIN = 4;

// Aktuelle UniFi/DHCP-MAC des WIZnet-Moduls beibehalten.
static byte mac[] = {0x00, 0x08, 0xDC, 0x53, 0x09, 0x73};
static EthernetServer server(MODBUS_PORT);

static bool relayState[4] = {false, false, false, false};
static unsigned long lastCommandMs = 0;
static unsigned long lastStatusMs = 0;

static void setRelay(uint8_t index, bool enabled) {
  if (index >= 4 || relayState[index] == enabled) {
    return;
  }
  relayState[index] = enabled;
  digitalWrite(RELAY_PINS[index], enabled ? HIGH : LOW);
  Serial.print(F("Relay "));
  Serial.print(index + 1);
  Serial.print(F(" = "));
  Serial.println(enabled ? F("ON") : F("OFF"));
}

static void allRelaysOff() {
  for (uint8_t i = 0; i < 4; i++) {
    setRelay(i, false);
  }
}

static uint16_t relayMask() {
  uint16_t mask = 0;
  for (uint8_t i = 0; i < 4; i++) {
    if (relayState[i]) {
      mask |= (1U << i);
    }
  }
  return mask;
}

static uint16_t inputMask() {
  uint16_t mask = 0;
  for (uint8_t i = 0; i < 4; i++) {
    if (digitalRead(OPTO_INPUT_PINS[i]) == HIGH) {
      mask |= (1U << i);
    }
  }
  return mask;
}

static void put16(uint8_t *buffer, size_t offset, uint16_t value) {
  buffer[offset] = static_cast<uint8_t>(value >> 8);
  buffer[offset + 1] = static_cast<uint8_t>(value & 0xFF);
}

static uint16_t get16(const uint8_t *buffer, size_t offset) {
  return (static_cast<uint16_t>(buffer[offset]) << 8) | buffer[offset + 1];
}

static void sendMbap(EthernetClient &client, const uint8_t *request, uint16_t pduLength) {
  uint8_t header[7];
  header[0] = request[0];
  header[1] = request[1];
  header[2] = 0;
  header[3] = 0;
  put16(header, 4, pduLength + 1);
  header[6] = request[6];
  client.write(header, sizeof(header));
}

static void sendException(EthernetClient &client, const uint8_t *request, uint8_t function, uint8_t code) {
  uint8_t pdu[2] = {static_cast<uint8_t>(function | 0x80), code};
  sendMbap(client, request, sizeof(pdu));
  client.write(pdu, sizeof(pdu));
}

static bool addressInRange(uint16_t address, uint16_t count) {
  return count >= 1 && address < 4 && (address + count) <= 4;
}

static void sendBits(EthernetClient &client, const uint8_t *request, uint8_t function, uint16_t mask, uint16_t address, uint16_t count) {
  if (!addressInRange(address, count)) {
    sendException(client, request, function, 2);
    return;
  }
  uint8_t byteCount = static_cast<uint8_t>((count + 7) / 8);
  uint8_t pdu[4] = {function, byteCount, 0, 0};
  for (uint16_t i = 0; i < count; i++) {
    if (mask & (1U << (address + i))) {
      pdu[2 + (i / 8)] |= (1U << (i % 8));
    }
  }
  sendMbap(client, request, 2 + byteCount);
  client.write(pdu, 2 + byteCount);
}

static void sendHoldingRegisters(EthernetClient &client, const uint8_t *request, uint8_t function, uint16_t address, uint16_t count) {
  if (count < 1 || address + count > 5) {
    sendException(client, request, function, 2);
    return;
  }
  uint16_t regs[5];
  uint32_t uptime = millis() / 1000UL;
  regs[0] = static_cast<uint16_t>(uptime & 0xFFFF);
  regs[1] = static_cast<uint16_t>((uptime >> 16) & 0xFFFF);
  regs[2] = relayMask();
  regs[3] = inputMask();
  regs[4] = FIRMWARE_VERSION;

  uint8_t byteCount = static_cast<uint8_t>(count * 2);
  uint8_t pdu[2 + 10] = {function, byteCount};
  for (uint16_t i = 0; i < count; i++) {
    put16(pdu, 2 + i * 2, regs[address + i]);
  }
  sendMbap(client, request, 2 + byteCount);
  client.write(pdu, 2 + byteCount);
}

static void handleModbusPdu(EthernetClient &client, const uint8_t *request, const uint8_t *pdu, uint16_t pduLength) {
  if (pduLength < 1) {
    return;
  }
  uint8_t function = pdu[0];
  switch (function) {
    case 1:
      if (pduLength < 5) {
        sendException(client, request, function, 3);
        return;
      }
      sendBits(client, request, function, relayMask(), get16(pdu, 1), get16(pdu, 3));
      return;

    case 2:
      if (pduLength < 5) {
        sendException(client, request, function, 3);
        return;
      }
      sendBits(client, request, function, inputMask(), get16(pdu, 1), get16(pdu, 3));
      return;

    case 3:
    case 4:
      if (pduLength < 5) {
        sendException(client, request, function, 3);
        return;
      }
      sendHoldingRegisters(client, request, function, get16(pdu, 1), get16(pdu, 3));
      return;

    case 5: {
      if (pduLength < 5) {
        sendException(client, request, function, 3);
        return;
      }
      uint16_t address = get16(pdu, 1);
      uint16_t value = get16(pdu, 3);
      if (address >= 4 || (value != 0xFF00 && value != 0x0000)) {
        sendException(client, request, function, 2);
        return;
      }
      setRelay(static_cast<uint8_t>(address), value == 0xFF00);
      lastCommandMs = millis();
      sendMbap(client, request, 5);
      client.write(pdu, 5);
      return;
    }

    case 15: {
      if (pduLength < 6) {
        sendException(client, request, function, 3);
        return;
      }
      uint16_t address = get16(pdu, 1);
      uint16_t count = get16(pdu, 3);
      uint8_t byteCount = pdu[5];
      if (!addressInRange(address, count) || pduLength < static_cast<uint16_t>(6 + byteCount)) {
        sendException(client, request, function, 2);
        return;
      }
      for (uint16_t i = 0; i < count; i++) {
        bool enabled = bool(pdu[6 + (i / 8)] & (1U << (i % 8)));
        setRelay(static_cast<uint8_t>(address + i), enabled);
      }
      lastCommandMs = millis();
      uint8_t response[5] = {function, pdu[1], pdu[2], pdu[3], pdu[4]};
      sendMbap(client, request, sizeof(response));
      client.write(response, sizeof(response));
      return;
    }

    default:
      sendException(client, request, function, 1);
      return;
  }
}
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

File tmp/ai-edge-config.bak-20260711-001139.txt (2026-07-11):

;[TakeImage]
;RawImagesLocation = 
;RawImagesRetention = 
WaitBeforeTakingPicture = 5
CamGainceiling = x8
CamQuality = 10
CamBrightness = 0
CamContrast = 0
CamSaturation = 0
CamSharpness = 0
CamAutoSharpness = false
CamSpecialEffect = no_effect
CamWbMode = auto
CamAwb = true
CamAwbGain = true
CamAec = true
CamAec2 = true
CamAeLevel = 2
CamAecValue = 600
CamAgc = true
CamAgcGain = 8
CamBpc = true
CamWpc = true
CamRawGma = true
CamLenc = true
CamHmirror = false
CamVflip = false
CamDcw = true
CamDenoise = 0
CamZoom = false
CamZoomOffsetX = 0
CamZoomOffsetY = 0
CamZoomSize = 0
LEDIntensity = 50
;Demo = 

;[Alignment]
InitialRotate = 0.0
;SearchFieldX = 
;SearchFieldY = 
;AlignmentAlgo = 

;[Digits]
;Model = 
;CNNGoodThreshold = 
;ROIImagesLocation = 
;ROIImagesRetention = 

;[Analog]
;Model = 
;ROIImagesLocation = 
;ROIImagesRetention = 

;[PostProcessing]
;PreValueUse = 
;PreValueAgeStartup = 
;ErrorMessage = 

;[MQTT]
;Uri = 
;MainTopic = 
;ClientID = 
;user = 
;password = 
;RetainMessages = 
;DomoticzTopicIn = 
;HomeassistantDiscovery = 
;MeterType = 
;CACert = 
;ClientCert = 
;ClientKey = 
;ValidateServerCert = 

;[InfluxDB]
;Uri = 
;Database = 
;user = 
;password = 

;[InfluxDBv2]
;Uri = 
;Bucket = 
;Org = 
;Token = 

;[Webhook]
;Uri = 
;ApiKey = 
;UploadImg = 

;[GPIO]
;IO0 =      
;IO1 =      
;IO3 =      
;IO4 =      
;IO12 =      
;IO13 =      
;LEDType = WS2812
;LEDNumbers = 2
;LEDColor = 50 50 50

;[AutoTimer]
;Interval = 

[DataLogging]
DataLogActive = true
DataFilesRetention = 3

;[Debug]
;LogLevel = 
;LogfilesRetention = 

;[System]
Tooltip = true
;TimeZone = 
;TimeServer = 
;Hostname = 
;RSSIThreshold = 0
;CPUFrequency = 
SetupMode = false
